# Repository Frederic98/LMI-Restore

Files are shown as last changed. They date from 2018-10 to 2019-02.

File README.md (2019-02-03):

# LMI-Restore

This is the github repository for the LMI re-store project at the Mechatronics lab at Fontys.

To run the software:
1. Start the server `python3 LMI_Server/server.py`
2. Start the client `python3 LMI_GUI/main.py`

The motion controller is programmed with Mbed: https://os.mbed.com/users/Frederic98/code/LMI_restore_V2/.  
The host talks to it using [g-code](https://reprap.org/wiki/G-code). It uses the existing codes where possible (G0/G1 to move to a position, G28 to home...) or a custom code when this doesn't exist yet. (M200 to set the velocity for an axis. Normally, this is done with Fxxx in a G0/G1 command to set the total velocity of all axes combined when they are all synchronized. This, however, is not the case in this project, so another command had to be added to set the velocity of a specific axis)

Initially, the G-code was sent over the ethernet interface to the nucleo. This, however, seemed a bit unstable with the connection dropping after a couple of commands.
For this reason, it was replaced by the USB UART port (available at the programming USB connector).

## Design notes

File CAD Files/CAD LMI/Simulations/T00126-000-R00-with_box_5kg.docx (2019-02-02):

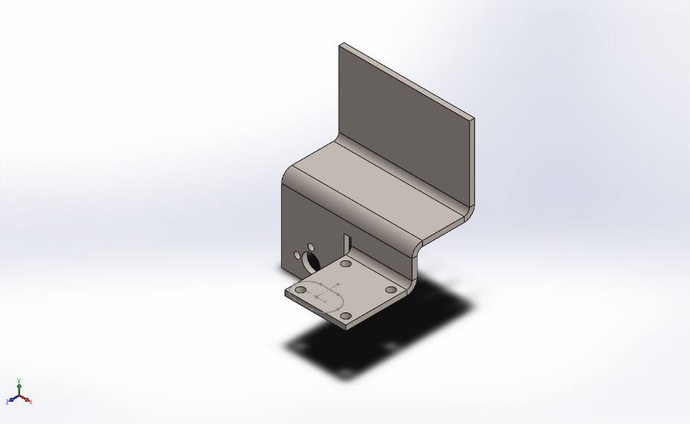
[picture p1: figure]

Simulation of T00126-000-R00

Date: woensdag 12 december 2018
Designer: Jari Wernaart

Study name: Static 2

Analysis type: Static
Description No Data

# Assumptions

# Model Information

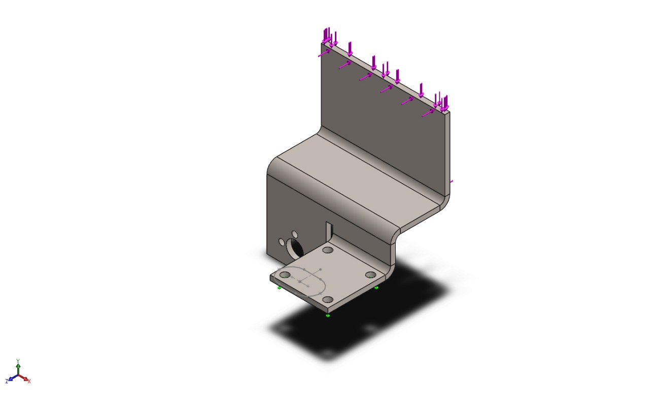
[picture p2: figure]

Model name: T00126-000-R00

Current Configuration: Default

# Study Properties

Study name | Static 2
Analysis type | Static
Mesh type | Shell Mesh Using Mid-surfaces
Thermal Effect: | On
Thermal option | Include temperature loads
Zero strain temperature | 298 Kelvin
Include fluid pressure effects from SOLIDWORKS Flow Simulation | Off
Solver type | FFEPlus
Inplane Effect: | Off
Soft Spring: | Off
Inertial Relief: | Off
Incompatible bonding options | Automatic
Large displacement | Off
Compute free body forces | On
Friction | Off
Use Adaptive Method: | Off
Result folder | SOLIDWORKS document (F:\Google drive\LMI restore system\1. Documenten\7. CAD files\CAD LMI)

# Units

Unit system: | SI (MKS)
Length/Displacement | mm
Temperature | Kelvin
Angular velocity | Rad/sec
Pressure/Stress | N/m^2

# Material Properties

Model Reference | Properties | Components

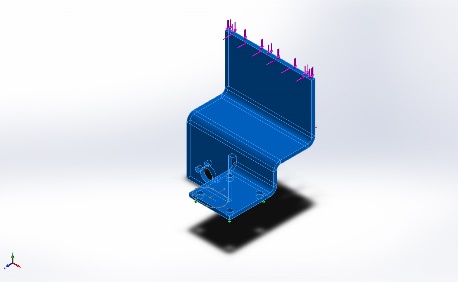
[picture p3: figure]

| Name: Alloy Steel Model type: Linear Elastic Isotropic Default failure criterion: Max von Mises Stress Yield strength: 6.20422e+08 N/m^2 Tensile strength: 7.23826e+08 N/m^2 Elastic modulus: 2.1e+11 N/m^2 Poisson's ratio: 0.28 Mass density: 7700 kg/m^3 Shear modulus: 7.9e+10 N/m^2 Thermal expansion coefficient: 1.3e-05 /Kelvin | SolidBody 1(Body-Move/Copy1)(T00126-000-R00)

Curve Data:N/A

# Loads and Fixtures

Fixture name | Fixture Image | Fixture Details

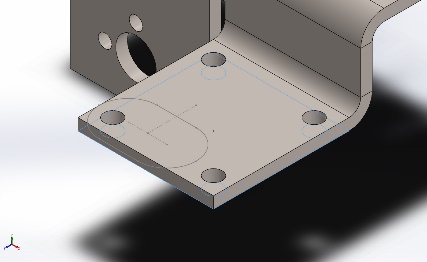
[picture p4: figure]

Fixed-1 | | Entities: 1 face(s) Type: Fixed Geometry

Resultant Forces

Components | X | Y | Z | Resultant
Reaction force(N) | -0.0373039 | 48.8594 | -0.0282078 | 48.8594
Reaction Moment(N.m) | 5.58892 | 0.000350614 | 0.00770916 | 5.58893

Load name | Load Image | Load Details

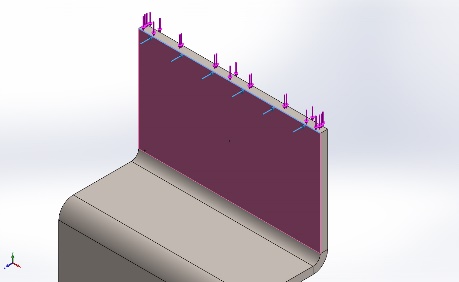
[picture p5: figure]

Force-2 | | Entities: 1 edge(s) Reference: Face< 1 > Type: Apply force Values: ---, ---, -87.2 N Moments: ---, ---, --- N.m

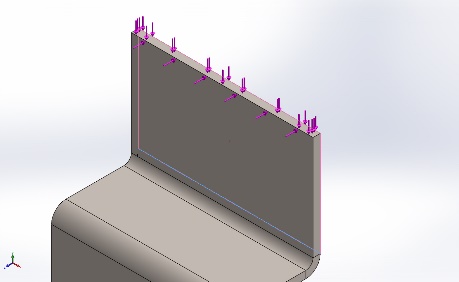
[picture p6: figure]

Force-3 | | Entities: 1 edge(s) Reference: Face< 1 > Type: Apply force Values: ---, ---, 87.2 N Moments: ---, ---, --- N.m

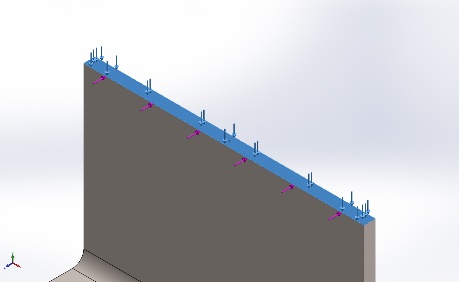
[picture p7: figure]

Force-4 | | Entities: 1 face(s) Type: Apply normal force Value: 49.05 N

# Connector Definitions

No Data

# Contact Information

No Data

# Mesh information

Mesh type | Shell Mesh Using Mid-surfaces
Mesher Used: | Standard mesh
Automatic Transition: | Off
Include Mesh Auto Loops: | Off
Jacobian points | 4 Points
Element Size | 1.9994 mm
Tolerance | 0.0999699 mm
Mesh Quality Plot | High

## Mesh information - Details

Total Nodes | 10121
Total Elements | 4902
Time to complete mesh(hh;mm;ss): | 00:00:03
Computer name:

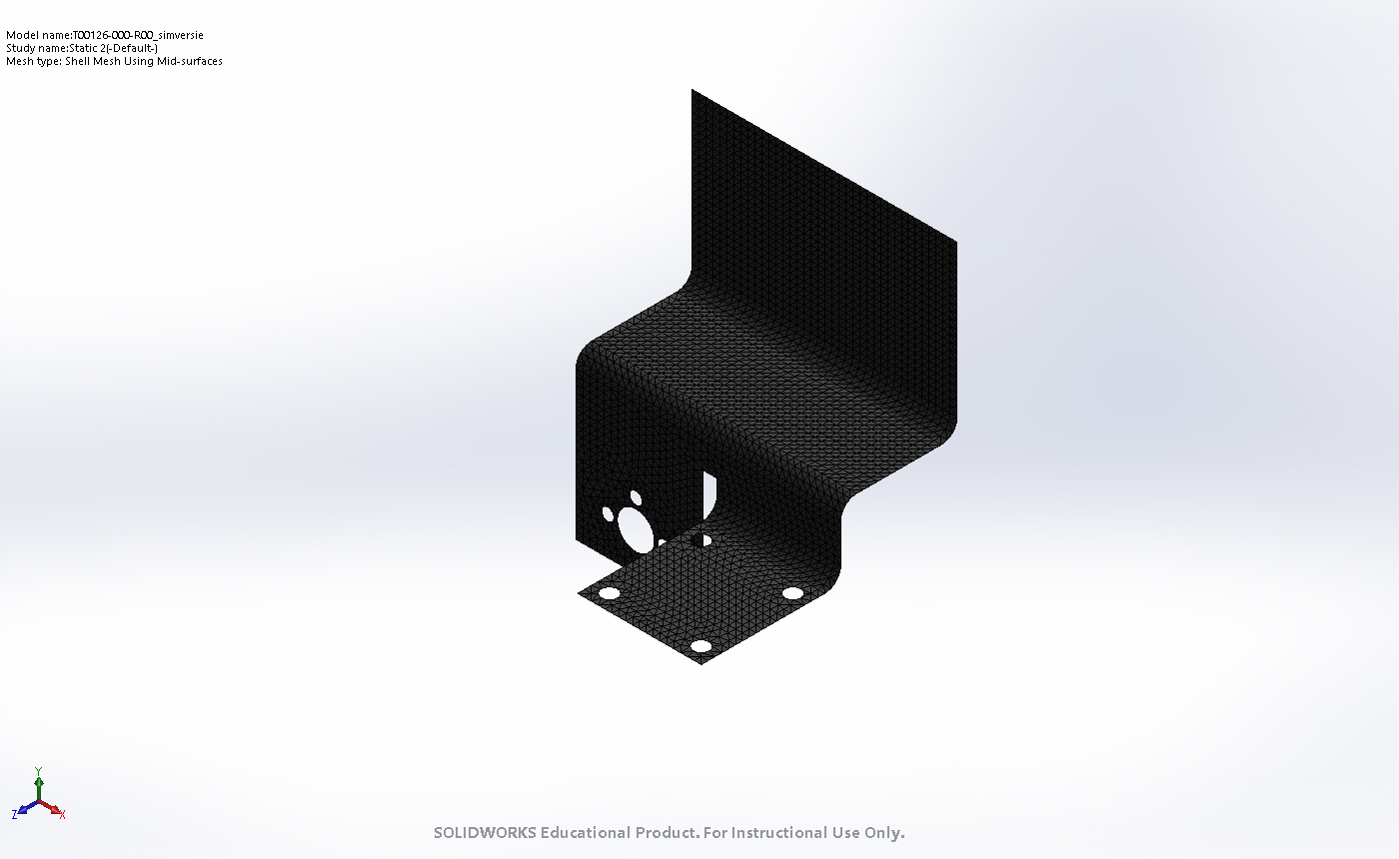
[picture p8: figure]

# Sensor Details

No Data

# Resultant Forces

## Reaction forces

Selection set | Units | Sum X | Sum Y | Sum Z | Resultant
Entire Model | N | -0.0373039 | 48.8594 | -0.0282078 | 48.8594

## Reaction Moments

Selection set | Units | Sum X | Sum Y | Sum Z | Resultant
Entire Model | N.m | 5.58892 | 0.000350614 | 0.00770916 | 5.58893

# Beams

No Data

# Study Results

Name | Type | Min | Max
Stress1 | VON: von Mises Stress | 0.000e+00 N/m^2 Node: 2273 | 2.903e+08 N/m^2 Node: 925

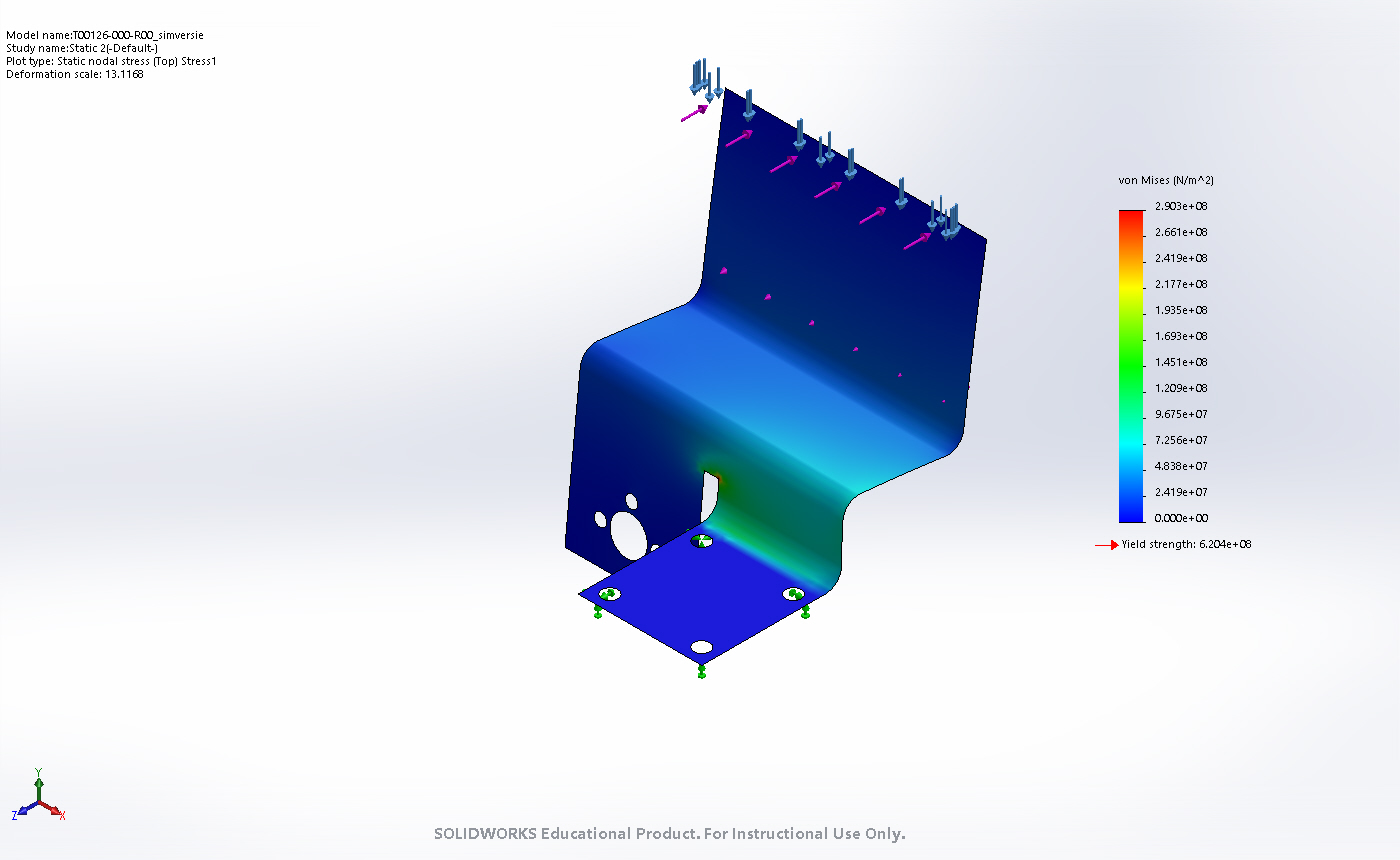
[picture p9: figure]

T00126-000-R00 -Static 2-Stress-Stress1

Name | Type | Min | Max
Displacement1 | URES: Resultant Displacement | 0.000e+00 mm Node: 2200 | 7.911e-01 mm Node: 1339

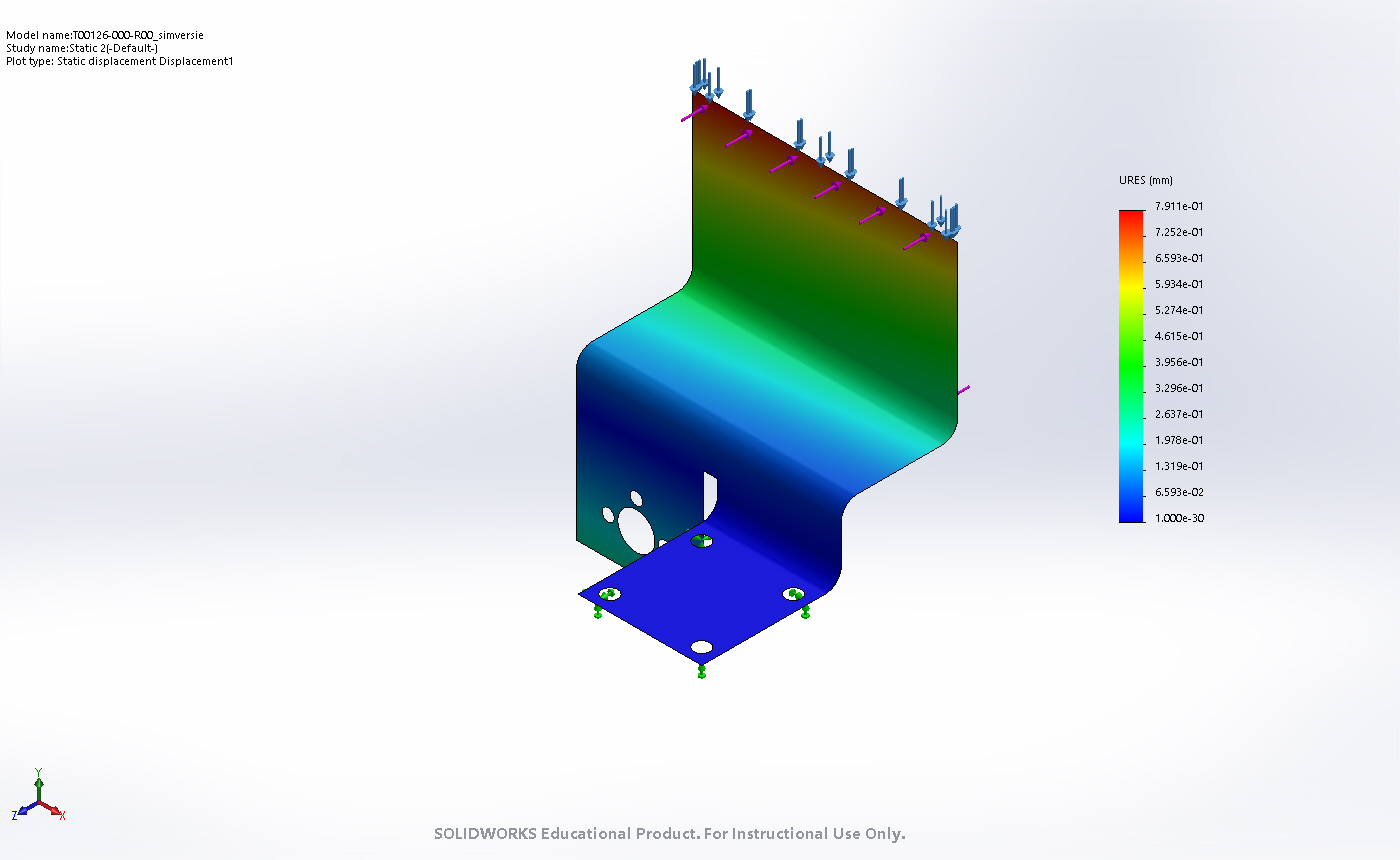
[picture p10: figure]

T00126-000-R00 -Static 2-Displacement-Displacement1

Name | Type | Min | Max
Strain1 | ESTRN: Equivalent Strain | 0.000e+00 Element: 4295 | 7.981e-04 Element: 2136

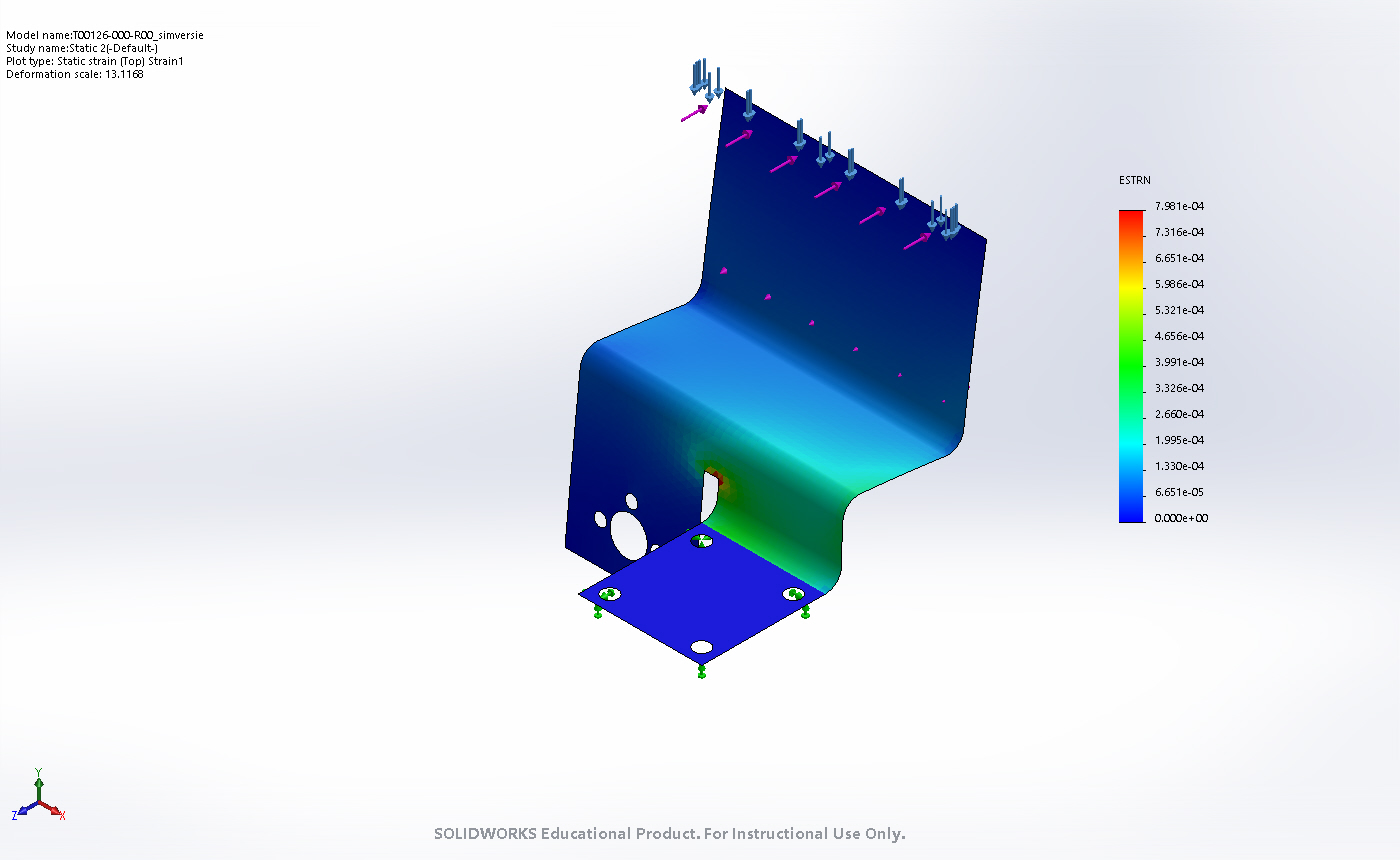
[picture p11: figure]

T00126-000-R00 -Static 2-Strain-Strain1

# Conclusion

Analyzed with SOLIDWORKS Simulation Simulation of T00126-000-R00 7

Analyzed with SOLIDWORKS Simulation Simulation of T00126-000-R00 1

Fontys Jari Wernaart 12-12-2018

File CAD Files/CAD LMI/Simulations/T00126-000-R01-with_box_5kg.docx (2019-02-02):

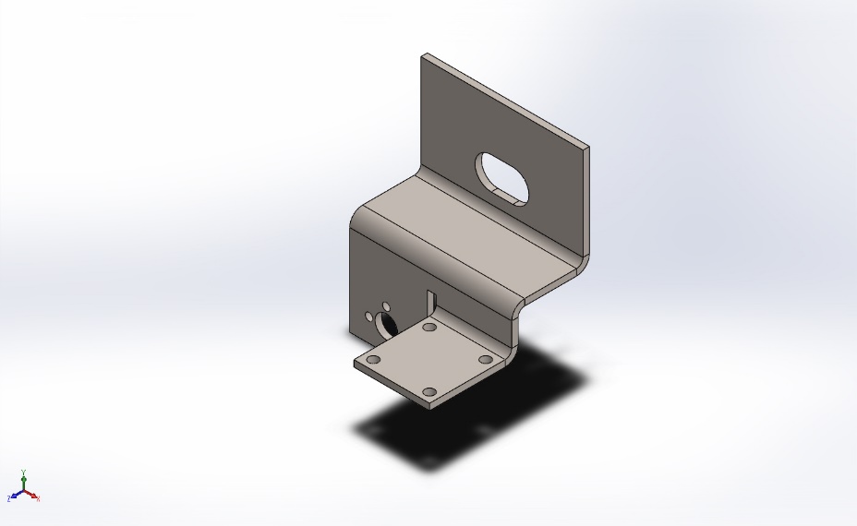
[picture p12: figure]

Simulation of T00126-000-R01

Date: woensdag 12 december 2018
Designer: Jari Wernaart

Study name: Static 2

Analysis type: Static
Description No Data

# Assumptions

# Model Information

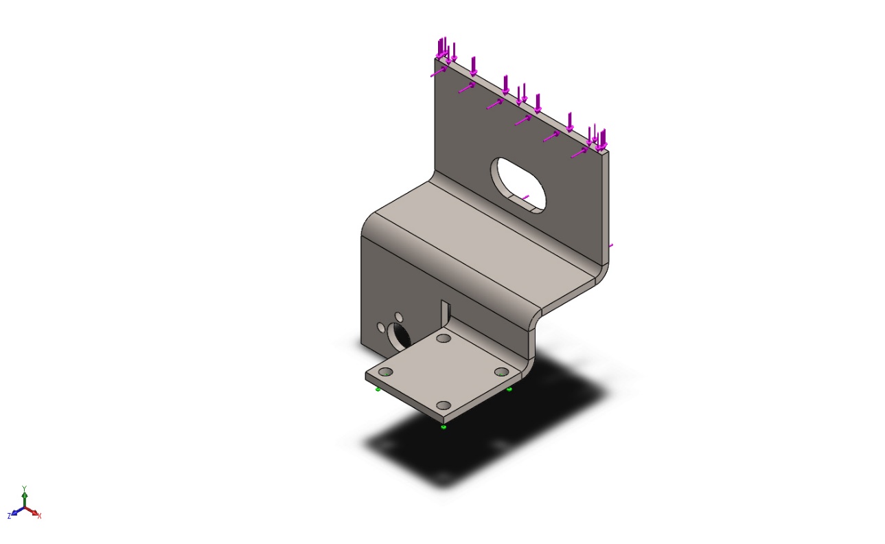
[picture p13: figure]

Model name: T00126-000-R01

Current Configuration: Default

# Study Properties

Study name | Static 2
Analysis type | Static
Mesh type | Shell Mesh Using Mid-surfaces
Thermal Effect: | On
Thermal option | Include temperature loads
Zero strain temperature | 298 Kelvin
Include fluid pressure effects from SOLIDWORKS Flow Simulation | Off
Solver type | FFEPlus
Inplane Effect: | Off
Soft Spring: | Off
Inertial Relief: | Off
Incompatible bonding options | Automatic
Large displacement | Off
Compute free body forces | On
Friction | Off
Use Adaptive Method: | Off
Result folder | SOLIDWORKS document (F:\Google drive\LMI restore system\1. Documenten\7. CAD files\CAD LMI)

# Units

Unit system: | SI (MKS)
Length/Displacement | mm
Temperature | Kelvin
Angular velocity | Rad/sec
Pressure/Stress | N/m^2

# Material Properties

Model Reference | Properties | Components

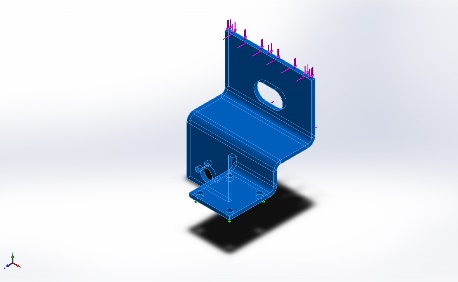
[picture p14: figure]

| Name: Alloy Steel Model type: Linear Elastic Isotropic Default failure criterion: Max von Mises Stress Yield strength: 6.20422e+08 N/m^2 Tensile strength: 7.23826e+08 N/m^2 Elastic modulus: 2.1e+11 N/m^2 Poisson's ratio: 0.28 Mass density: 7700 kg/m^3 Shear modulus: 7.9e+10 N/m^2 Thermal expansion coefficient: 1.3e-05 /Kelvin | SolidBody 1(Body-Move/Copy1)(T00126-000-R01)

Curve Data:N/A

# Loads and Fixtures

Fixture name | Fixture Image | Fixture Details

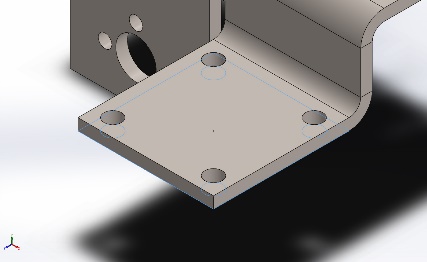
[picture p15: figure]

Fixed-1 | | Entities: 1 face(s) Type: Fixed Geometry

Resultant Forces

Components | X | Y | Z | Resultant
Reaction force(N) | -0.0425277 | 48.854 | -0.00805473 | 48.854
Reaction Moment(N.m) | 5.58896 | 0.000318305 | 0.00770636 | 5.58896

Load name | Load Image | Load Details

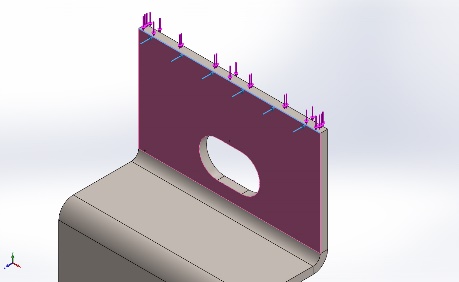
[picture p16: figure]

Force-2 | | Entities: 1 edge(s) Reference: Face< 1 > Type: Apply force Values: ---, ---, -87.2 N Moments: ---, ---, --- N.m

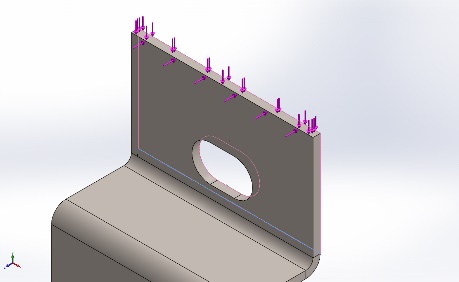
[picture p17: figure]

Force-3 | | Entities: 1 edge(s) Reference: Face< 1 > Type: Apply force Values: ---, ---, 87.2 N Moments: ---, ---, --- N.m

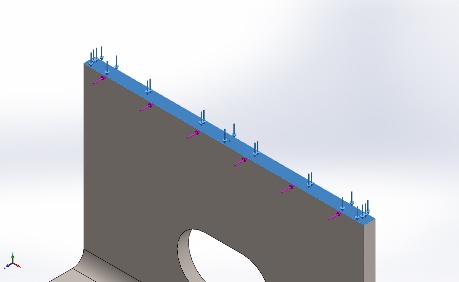
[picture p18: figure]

Force-4 | | Entities: 1 face(s) Type: Apply normal force Value: 49.05 N

# Connector Definitions

No Data

# Contact Information

No Data

# Mesh information

Mesh type | Shell Mesh Using Mid-surfaces
Mesher Used: | Standard mesh
Automatic Transition: | Off
Include Mesh Auto Loops: | Off
Jacobian points | 4 Points
Element Size | 1.9994 mm
Tolerance | 0.0999699 mm
Mesh Quality Plot | High

## Mesh information - Details

Total Nodes | 9826
Total Elements | 4738
Time to complete mesh(hh;mm;ss): | 00:00:03
Computer name:

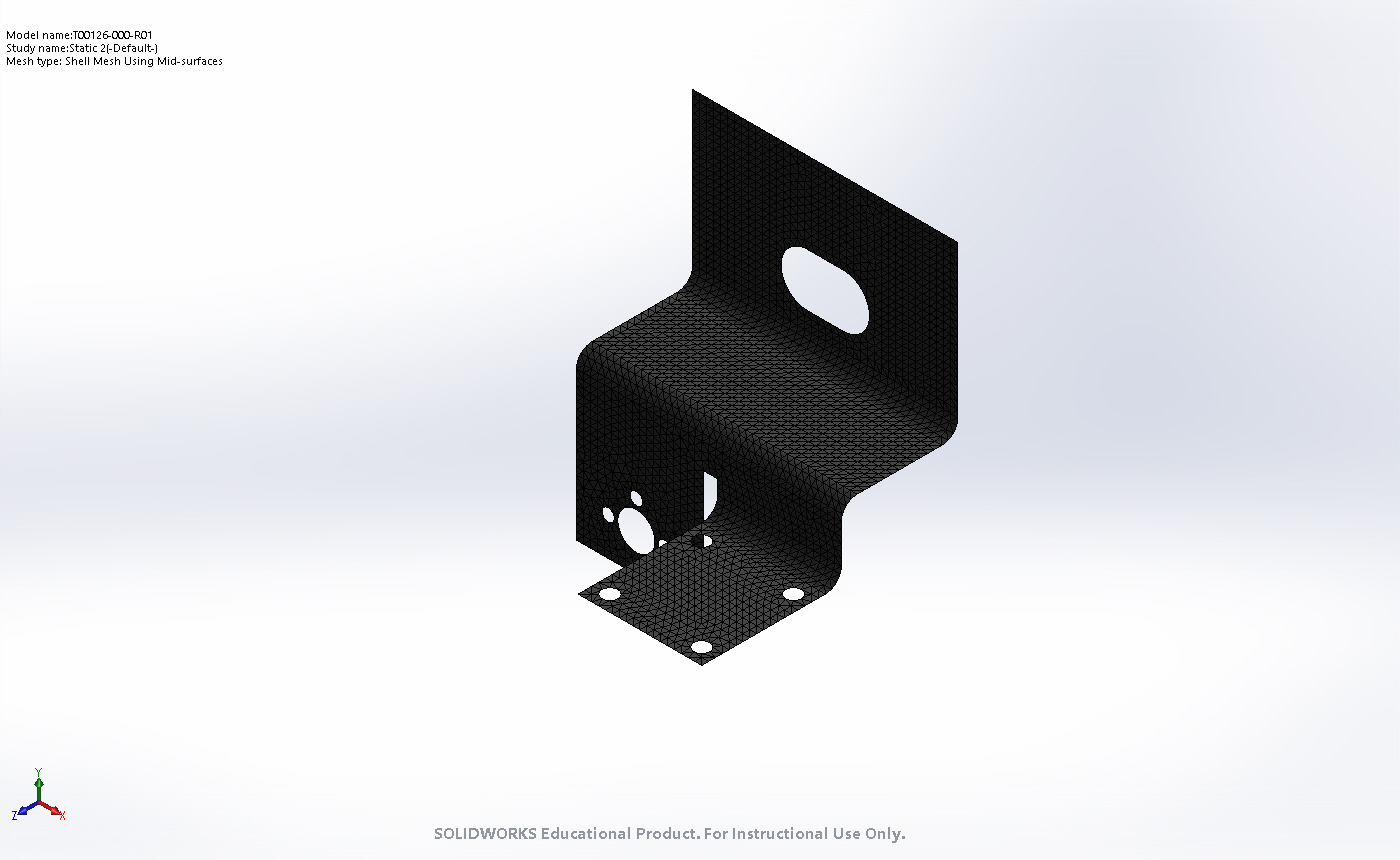
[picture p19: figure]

# Sensor Details

No Data

# Resultant Forces

## Reaction forces

Selection set | Units | Sum X | Sum Y | Sum Z | Resultant
Entire Model | N | -0.0425277 | 48.854 | -0.00805473 | 48.854

## Reaction Moments

Selection set | Units | Sum X | Sum Y | Sum Z | Resultant
Entire Model | N.m | 5.58896 | 0.000318305 | 0.00770636 | 5.58896

# Beams

No Data

# Study Results

Name | Type | Min | Max
Stress1 | VON: von Mises Stress | 0.000e+00 N/m^2 Node: 2207 | 2.911e+08 N/m^2 Node: 925

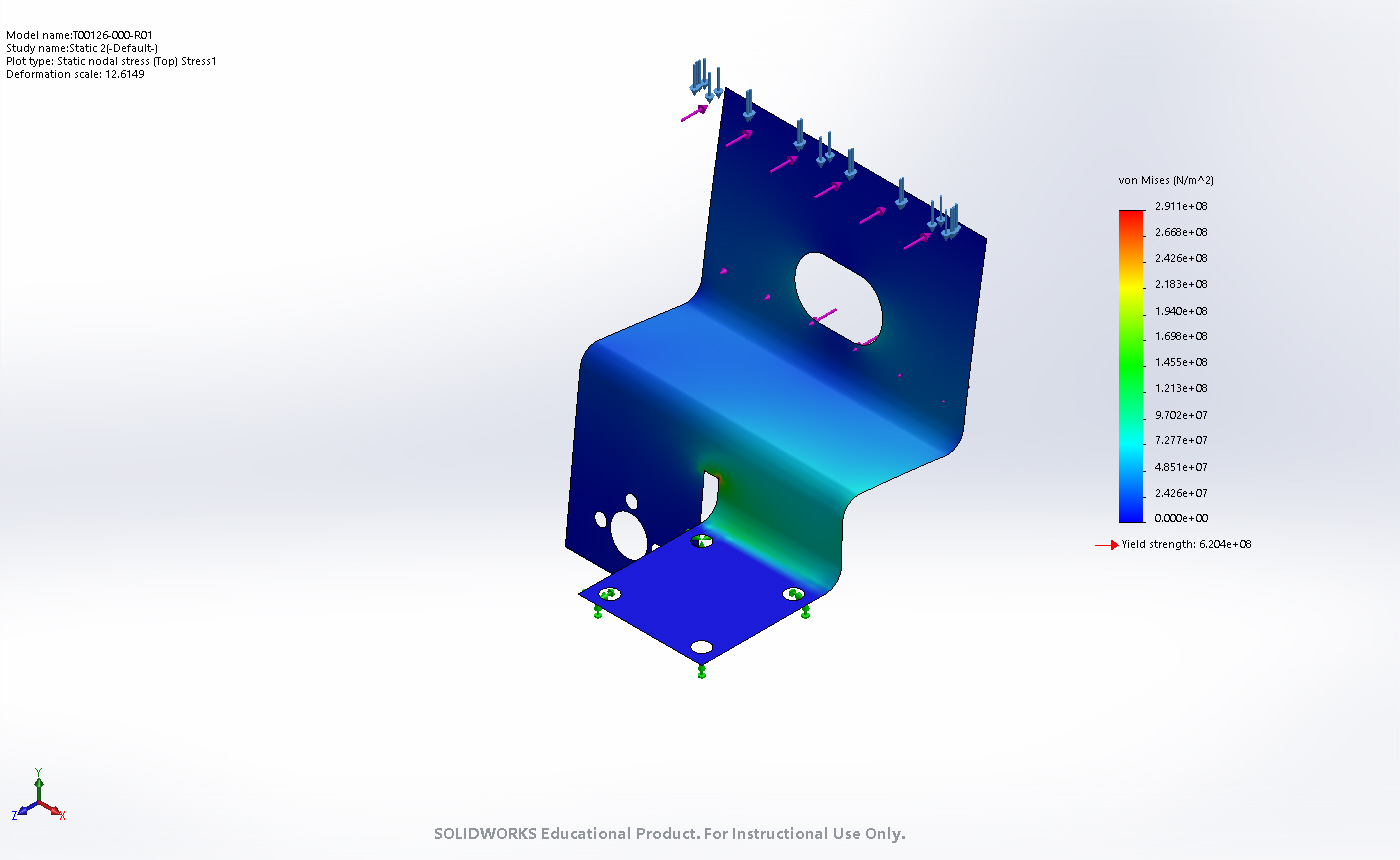
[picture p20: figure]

T00126-000-R01-Static 2-Stress-Stress1

Name | Type | Min | Max
Displacement1 | URES: Resultant Displacement | 0.000e+00 mm Node: 2134 | 8.171e-01 mm Node: 1373

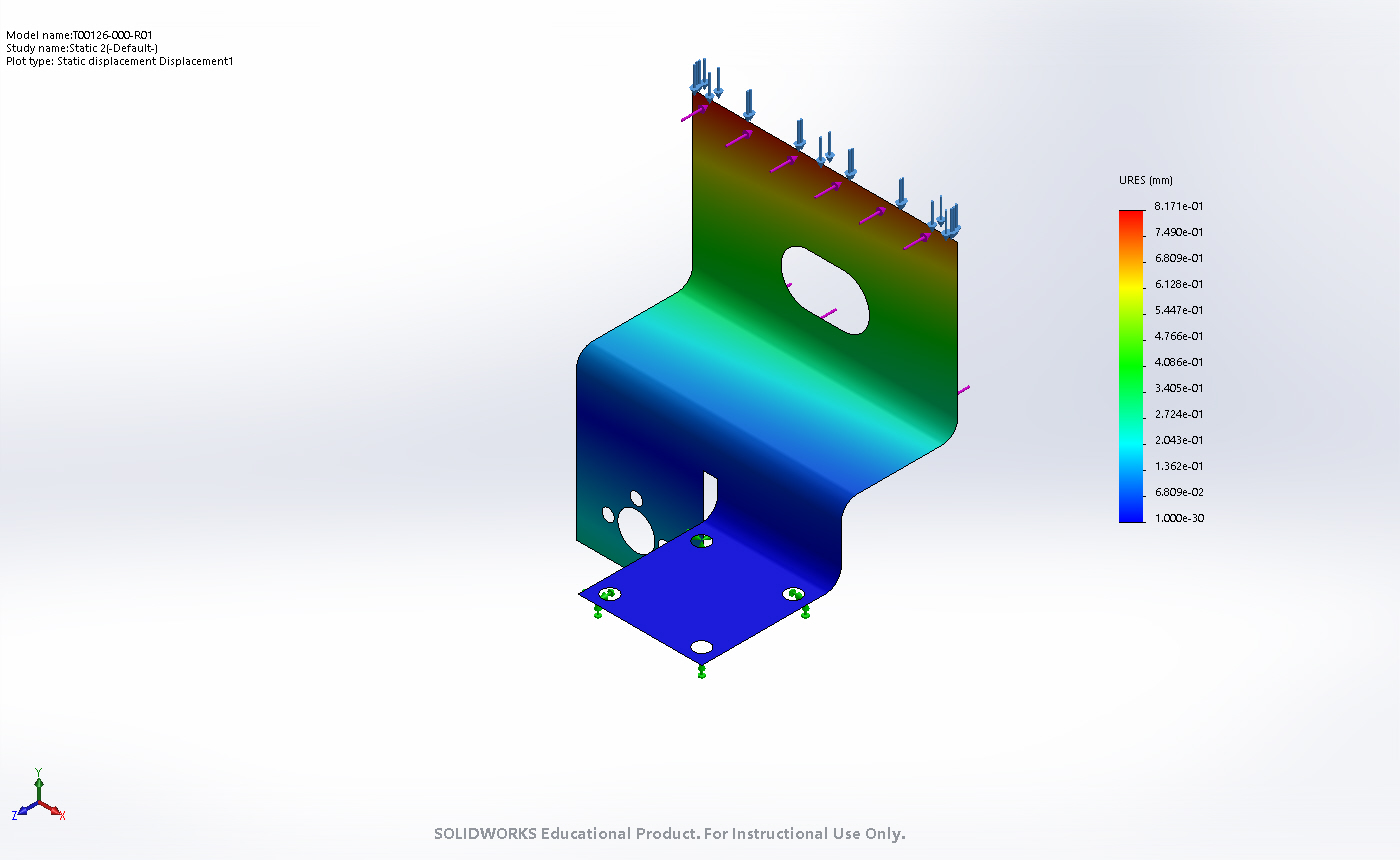
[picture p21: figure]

T00126-000-R01-Static 2-Displacement-Displacement1

Name | Type | Min | Max
Strain1 | ESTRN: Equivalent Strain | 0.000e+00 Element: 4131 | 7.999e-04 Element: 2136

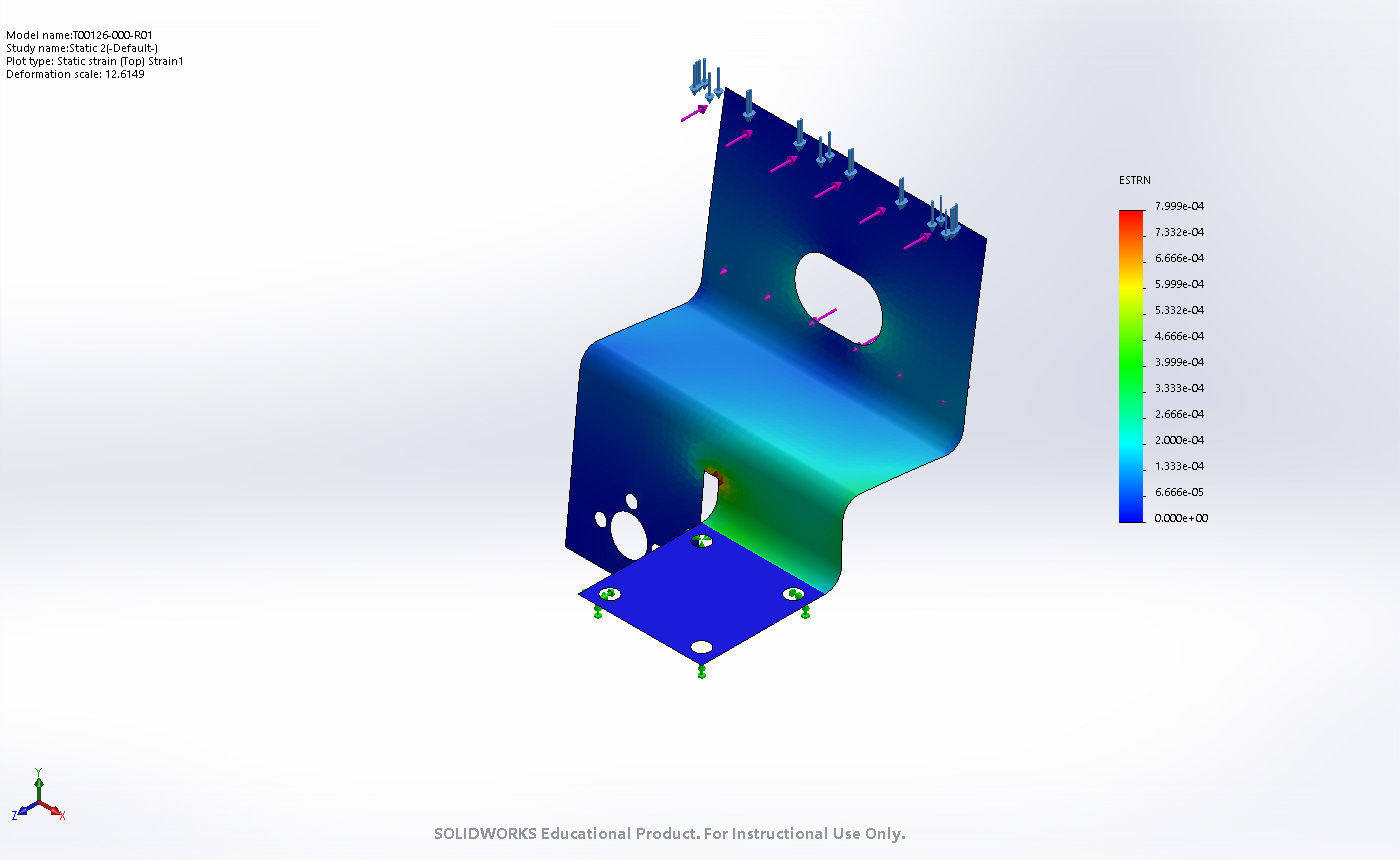
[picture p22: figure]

T00126-000-R01-Static 2-Strain-Strain1

# Conclusion

Analyzed with SOLIDWORKS Simulation Simulation of T00126-000-R01 7

Analyzed with SOLIDWORKS Simulation Simulation of T00126-000-R01 1

Fontys Jari Wernaart 12-12-2018

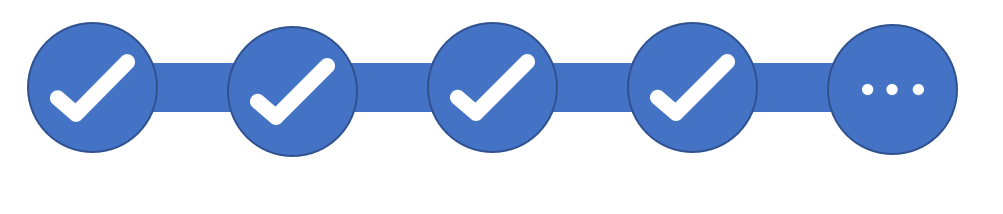
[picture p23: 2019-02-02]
LMI_GUI/Images/busy_5.PNG

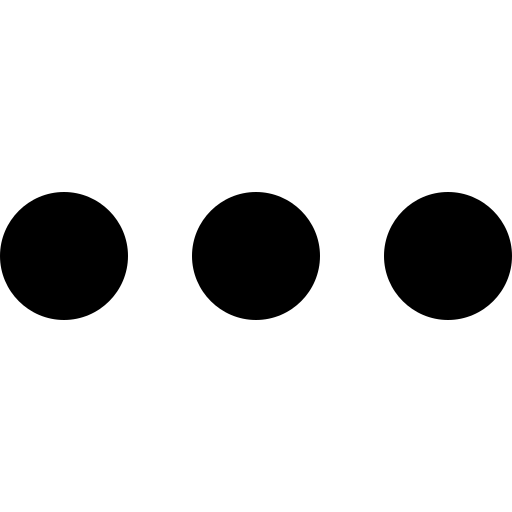
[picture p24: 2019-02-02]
LMI_GUI/Images/Triple-dot_black.png

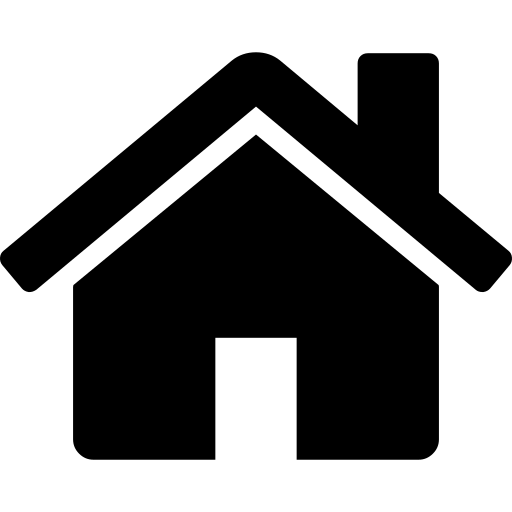
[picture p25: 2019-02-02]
LMI_GUI/Images/home.png

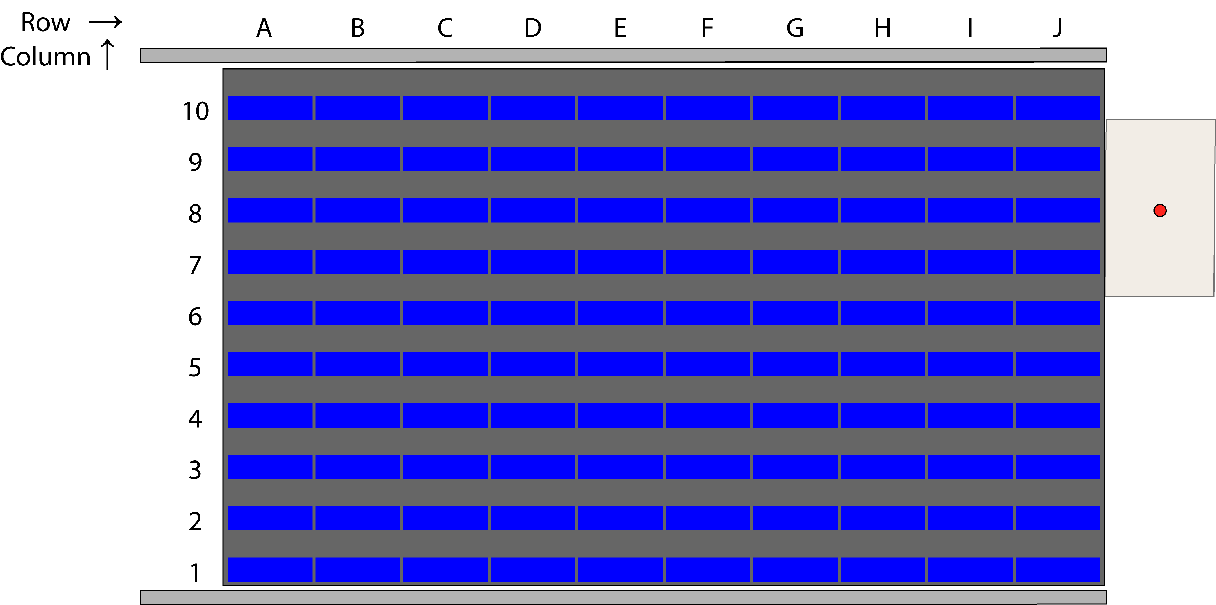
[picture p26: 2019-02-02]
LMI_GUI/Images/Storage_unit_RC.png

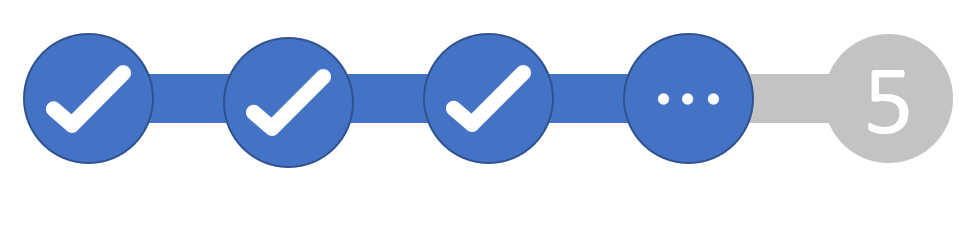
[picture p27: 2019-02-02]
LMI_GUI/Images/busy_4.PNG

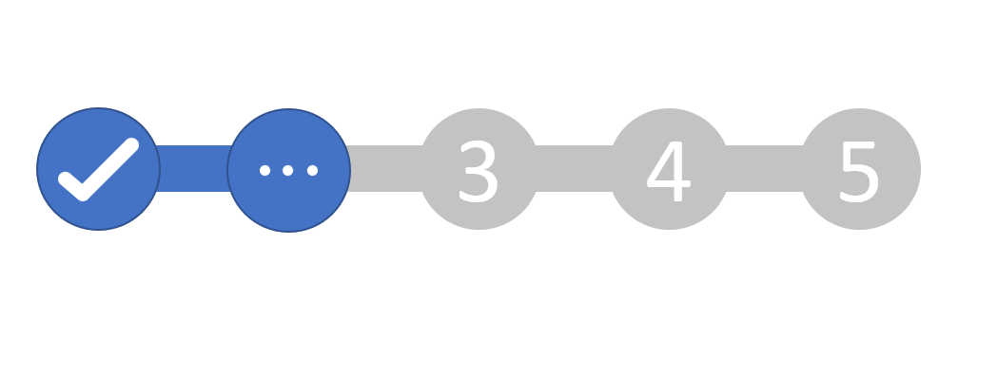
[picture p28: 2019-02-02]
LMI_GUI/Images/busy_2.PNG

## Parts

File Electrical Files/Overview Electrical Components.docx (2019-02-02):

Electrical components inside electrical box

QTY | Functie | Model/type | Leverancier - artikelnummer
1 | Elektrokast 400x500x210mm | Rittal AE 1045.500 | Conrad - 531738 (https://www.conrad.nl/p/rittal-ae-1045500-schakelkast-400-x-500-x-210-plaatstaal-grijs-wit-ral-7035-1-stuks-531738)
1 | 230V connector | 59JR101-1FR-LR | Conrad - 736709 (https://www.conrad.nl/p/apparaatstekker-42r-serie-connectoren-42r-stekker-inbouw-verticaal-totaal-aantal-polen-2-pe-10-a-zwart-k-b-59jr1-736709)
1 | Emergency switch | 1233815 | Conrad - 1233815 (https://www.conrad.nl/p/deca-a20l-v4e02q6r-noodstopschakelaar-met-contactelement-240-vac-6-a-2x-nc-ip65-1-stuks-1233815)
1 | Power supply 24V, 15A | POWER-S25024 - 24V | Reprap World - 8719128324975 (https://reprapworld.nl/products/elektronica/voeding/stroomadapter_24v_240_115v_15a_max/)
1 | Power supply 12V, 30A | POWER-S25012-12V30A | Reprap World - 8719128327037 (https://reprapworld.nl/products/elektronica/voeding/stroomadapter_12v_240_115v_30a_max/)
2 | Stepper driver R and Z | SDTB6600 9-42V, 3.5A | Reprap World - 8719345004964 (https://reprapworld.nl/products/elektronica/stappenmotordriver/tb6600_stappenmotor_3_5a_1_32_microstappen_9_42v/)
2 | Stepper driver X and Y | SL2690A 20-90V, 6.5A | Reprap World - 8719345005824 (https://reprapworld.nl/products/elektronica/stappenmotordriver/sl2690a_stappenmotor_6_5a_1_128_microstappen_20_90v/)
1 | 5V relay 1-channel high active | 5VRELHA | TinyTronics - 000131 (https://www.tinytronics.nl/shop/nl/diversen/relais/5v-relais-1-channel-hoog-actief?search=relais)
1 | STM32 Nucleo-144 | NUCLEO-F439ZI | Farnll - 2845532 (https://nl.farnell.com/stmicroelectronics/nucleo-f439zi/dev-board-32bit-arm-cortex-m4/dp/2845532?ost=2845532)
1 | Raspberry Pi 3 Model B+ 1GB | RPI3B+ | TinyTronics - 001587 (https://www.tinytronics.nl/shop/nl/raspberry-pi/main-boards/raspberry-pi-3-model-b-1gb-1?search=1587)
1 | Ethernet cable | F6TP0,25RT | Conrad - 1886785 (https://www.conrad.nl/p/econ-connect-rj45-netwerk-aansluitkabel-cat-6-sftp-025-m-rood-pair-afscherming-1886785)
2 | USB Adapter | NAUSB-W | Farnell - 1760681 (https://nl.farnell.com/neutrik/nausb-w/usb-adaptor-2-0-type-a-type-b/dp/1760681?ost=1760681)
2 | USB-B cable | USB-BUSB30CM | TinyTronics - 000927 (https://www.tinytronics.nl/shop/nl/kabels/usb/usb-b-usb-kabel-30cm?search=927)
2 | PC-ventilator | BL046 | Conrad - 756546 (https://www.conrad.nl/p/bequiet-pure-wings-2-pc-ventilator-zwart-b-x-h-x-d-120-x-120-x-25-mm-756546)
2 | PC fan grille | GRM120-30 | Conrad - 998782 (https://www.conrad.nl/p/pc-fan-grille-with-filter-akasa-grm120-30-120-x-120-mm-998782)
1 | Touchscreen | 7LCD1024X600TOUCHRPI | TinyTronics - 001501 (https://www.tinytronics.nl/shop/nl/raspberry-pi/accessoires/7-inch-lcd-display-1024*600-pixels-met-touchscreen-raspberry-pi-compatible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)
1 | HDMI cable | HDMICABLE1M | TinyTronics - 001270 (https://www.tinytronics.nl/shop/nl/kabels/hdmi/hdmi-kabel-1m?search=hdmi)
2 | Plug-in bridge - FBS 4-5 | Phoenix Contact FBS 4-5 | Conrad - 744072 (https://www.conrad.nl/p/geleiderbrug-fbs-4-5-phoenix-contact-inhoud-1-stuks-744072)
44 | Feed-through terminal block | Phoenix Contact UT2,5 | Conrad - 744725 (https://www.conrad.nl/p/phoenix-contact-ut-25-3044076-doorgangsklem-aantal-polen-2-014-mm-4-mm-grijs-1-stuks-744725)

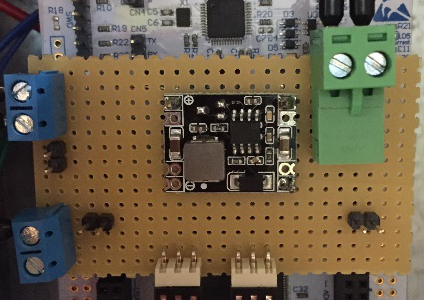
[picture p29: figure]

Nucleo Shield Components inside electrical box

QTY | Functie | Model/type | Leverancier - artikelnummer
1 | Voltage converter | DCDCSTEPDOWN5V | TinyTronics - 001319 (https://www.tinytronics.nl/shop/nl/spanning-converters/step-down/dc-dc-step-down-buck-converter-1.5a-5v-output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)
2 | Fan connector | 1580964 | Conrad - 1580964 (https://www.conrad.nl/p/tru-components-male-header-standaard-totaal-aantal-polen-3-rastermaat-254-mm-1580964-1-stuks-1580964)
2 | 2 pin screw terminal | PM 5.08/2/90 3.5 SW -1760510000 | RS - 425-8720 (https://nl.rs-online.com/web/p/pcb-terminal-blocks/4258720/)
1 | Pluggable Terminal Block PCB header | 691313510002 | RS - 826-7494 (https://nl.rs-online.com/web/p/pcb-terminal-blocks/8267494/)
1 | Pluggable Terminal Block | 1758364 | RS - 802-5919 (https://nl.rs-online.com/web/p/pcb-terminal-blocks/8025919/)

Raspberry Pi Shield Components inside electrical box

QTY | Functie | Model/type | Leverancier - artikelnummer
1 | Voltage converter | XL6009UPDOWN | TinyTronics - 001319 (https://www.tinytronics.nl/shop/nl/spanning-converters/step-up/dc-dc-verstelbare-step-up-down-buck-boost-converter-xl6009-4a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)
2 | 2 pin screw terminal | PM 5.08/2/90 3.5 SW -1760510000 | RS - 425-8720 (https://nl.rs-online.com/web/p/pcb-terminal-blocks/4258720/)
1 | Mini RS232 to TTL converter | MAX3232 | OpenCircuit - 34764 (https://opencircuit.nl/Product/11581/MAX3232-Mini-RS232-naar-TTL-converter)
2 | PCB Terminal Block | 1725656 | RS- 220-4260 (https://nl.rs-online.com/web/p/pcb-terminal-blocks/2204260/)

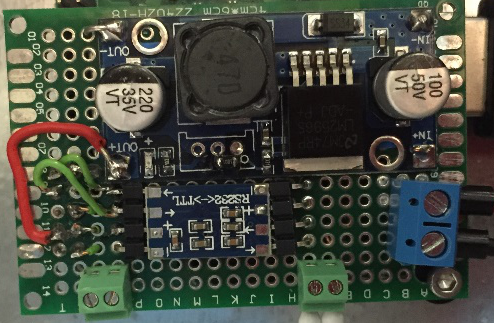
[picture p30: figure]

Electrical components outside electrical box

QTY | Functie | Model/type | Leverancier - artikelnummer
2 | Stepper Motor NEMA17 | SL42S247A | Reprap World - 8719345003981 (https://reprapworld.nl/products/motoren_fans/stappenmotoren/nema17_stappenmotor_1_8_stap_stekker_platte_as_5_0_kg_cm/)
1 | Stepper Motor NEMA23 | SMNM23S18KG31 | Reprap World - 8719345005800 (https://reprapworld.nl/products/motoren_fans/stappenmotoren/nema23_stappenmotor_1_8_stap_30_59_kg_cm)
1 | Nema 24 Stepper w/ Brake | 24HS39-4204D-B200 | Stepperonline - 24HS39-4204D-B200 (https://www.omc-stepperonline.com/nema-24-stepper-40nm566-ozin-w-brake-friction-torque-20nm283ozin-24hs39-4204d-b200.html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)
5 | Panasonic lightswitch F-type | PM-F65W-P | Conrad - 1547476 (https://www.conrad.nl/p/panasonic-pm-f65w-p-vorklichtsluis-f-type-lichtschakelend-donkerschakelend-5-24-vdc-1-stuks-1547476)
2 | Panasonic lightswitch | PM-Y65-P | Conrad - 1547442 (https://www.conrad.nl/p/panasonic-pm-y65-p-vorklichtsluis-y-type-lichtschakelend-donkerschakelend-5-24-vdc-1-stuks-1547442)
1 | Panasonic CN14AC1 light switch cable (1m) | CN14AC1 | Conrad - 1429076 (https://www.conrad.nl/p/panasonic-cn14ac1-aansluitkabel-serie-cn14-uitvoering-algemeen-aansluitkabel-1429076)
1 | Panasonic CN14AC3 light switch cable (3m) | CN14AC3 | Conrad - 1429107 (https://www.conrad.nl/p/panasonic-cn14ac3-aansluitkabel-serie-cn14-uitvoering-algemeen-aansluitkabel-1429107)
5 | Panasonic CN14AC5 light switch cable (5m) | CN14AC5 | Conrad - 1429077 (https://www.conrad.nl/p/panasonic-cn14ac5-aansluitkabel-serie-cn14-uitvoering-algemeen-aansluitkabel-1429077)
3 | Load cell – 5kg | LOADCELL5KG | Tinytronics - 000951 (https://www.tinytronics.nl/shop/nl/sensoren/gewicht-druk-kracht/load-cell-5kg)
3 | Load Cell Amplifier - HX711 | HX711MOD | TinyTronics - 000747 (https://www.tinytronics.nl/shop/nl/sensoren/gewicht-druk-kracht/load-cell-versterker-hx711?search=747)
1 | Voltage converter | DCDCSTEPDOWN5V | TinyTronics - 001319 (https://www.tinytronics.nl/shop/nl/spanning-converters/step-down/dc-dc-step-down-buck-converter-1.5a-5v-output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)
1 | Mini RS232 to TTL converter | MAX3232 | OpenCircuit - 34764 (https://opencircuit.nl/Product/11581/MAX3232-Mini-RS232-naar-TTL-converter)
1 | Barcode Scanner Module – 1D/2D | WS-14810 | Kiwi Electronics - WS-14810 (https://www.kiwi-electronics.nl/barcode-scanner-14810)
1 | GX16-4 Connector Set | GX16-4 | TinyTronics - 001081 (https://www.tinytronics.nl/shop/nl/connectoren/overige/gx16-4-connector-set?search=1081)
1 | GX16-6 Connector Set | GX16-6 | TinyTronics - 001593 (https://www.tinytronics.nl/shop/nl/connectoren/overige/gx16-6-connector-set?search=Connector%20Set)

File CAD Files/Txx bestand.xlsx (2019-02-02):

Tekeningnummer: | Omschrijving: | K/M | CAD Model: | Drawing: | 3D machining file (Bijv. STL of STEP): | Custom: | Hoogste revisie: | Samenstelling: | Link: | Bestandsnaam:
00000 | LMI Re-store system hoofdsamenstelling | K/M | JA | NEE | NEE | JA | 01 |  |  | T00000-000-R01 | 01 | 000 | 00000
00001 | XY-carriage samenstelling | K/M | JA | NEE | NEE | JA | 01 |  |  | T00001-000-R01 | 01 | 000 | 00001
00002 | Magazijn samenstelling | K/M | JA | NEE | NEE | JA | 00 |  |  | T00002-000-R00 | 00 | 000 | 00002
00003 | Arm samenstelling | K/M | JA | NEE | NEE | JA | 02 | 00001 |  | T00003-000-R02 | 02 | 000 | 00003
00004 | Weegschaal samenstelling | K/M | JA | NEE | NEE | JA | 00 | 00002 |  | T00004-000-R00 | 00 | 000 | 00004
00005 | Barcode case samenstelling | K/M | JA | NEE | NEE | JA | 00 |  |  | T00005-000-R00 | 00 | 000 | 00005
00006 | Pick-up plate samenstelling | K/M | JA | NEE | NEE | JA | 00 |  |  | T00006-000-R00 | 00 | 000 | 00006
00007 | Elektrobox samenstelling | K/M | JA | NEE | NEE | JA | 00 | 00000 |  | T00007-000-R00 | 00 | 000 | 00007
00008 |  |  |  |  |  |  |  |  |  |  |  | Error | 00008
00009 |  |  |  |  |  |  |  |  |  |  |  | Error | 00009
00010 |  |  |  |  |  |  |  |  |  |  |  | Error | 00010
00011 |  |  |  |  |  |  |  |  |  |  |  | Error | 00011
00012 |  |  |  |  |  |  |  |  |  |  |  | Error | 00012
00013 |  |  |  |  |  |  |  |  |  |  |  | Error | 00013
00014 |  |  |  |  |  |  |  |  |  |  |  | Error | 00014
00015 |  |  |  |  |  |  |  |  |  |  |  | Error | 00015
00016 |  |  |  |  |  |  |  |  |  |  |  | Error | 00016
00017 |  |  |  |  |  |  |  |  |  |  |  | Error | 00017
00018 |  |  |  |  |  |  |  |  |  |  |  | Error | 00018
00019 |  |  |  |  |  |  |  |  |  |  |  | Error | 00019
00020 |  |  |  |  |  |  |  |  |  |  |  | Error | 00020
00021 |  |  |  |  |  |  |  |  |  |  |  | Error | 00021
00022 |  |  |  |  |  |  |  |  |  |  |  | Error | 00022
00023 |  |  |  |  |  |  |  |  |  |  |  | Error | 00023
00024 |  |  |  |  |  |  |  |  |  |  |  | Error | 00024
00025 |  |  |  |  |  |  |  |  |  |  |  | Error | 00025
00026 |  |  |  |  |  |  |  |  |  |  |  | Error | 00026
00027 |  |  |  |  |  |  |  |  |  |  |  | Error | 00027
00028 |  |  |  |  |  |  |  |  |  |  |  | Error | 00028
00029 |  |  |  |  |  |  |  |  |  |  |  | Error | 00029
00030 |  |  |  |  |  |  |  |  |  |  |  | Error | 00030
00031 |  |  |  |  |  |  |  |  |  |  |  | Error | 00031
00032 |  |  |  |  |  |  |  |  | https://nl.aliexpress.com/store/product/10Pcs-7mm-Thread-Multicolor-2-Pins-Momentary-Push-Button-Switch/1965448_32788356922.html |  |  | Error | 00032
00033 |  |  |  |  |  |  |  |  |  |  |  | Error | 00033
00034 |  |  |  |  |  |  |  |  |  |  |  | Error | 00034
00035 |  |  |  |  |  |  |  |  |  |  |  | Error | 00035
00036 |  |  |  |  |  |  |  |  | https://www.alternate.nl/Sharkoon/SilentStorm-SFX-450-Bronze-450-Watt-voeding/html/product/1161908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 |  |  | Error | 00036
00037 |  |  |  |  |  |  |  |  |  |  |  | Error | 00037
00038 |  |  |  |  |  |  |  |  |  |  |  | Error | 00038
00039 |  |  |  |  |  |  |  |  |  |  |  | Error | 00039
00040 |  |  |  |  |  |  |  |  |  |  |  | Error | 00040
00041 |  |  |  |  |  |  |  |  |  |  |  | Error | 00041
00042 |  |  |  |  |  |  |  |  |  |  |  | Error | 00042
00043 |  |  |  |  |  |  |  |  |  |  |  | Error | 00043
00044 |  |  |  |  |  |  |  |  |  |  |  | Error | 00044
00045 |  |  |  |  |  |  |  |  |  |  |  | Error | 00045
00046 |  |  |  |  |  |  |  |  |  |  |  | Error | 00046
00047 |  |  |  |  |  |  |  |  |  |  |  | Error | 00047
00048 |  |  |  |  |  |  |  |  |  |  |  | Error | 00048
00049 |  |  |  |  |  |  |  |  |  |  |  | Error | 00049
00050 |  |  |  |  |  |  |  |  |  |  |  | Error | 00050
00051 |  |  |  |  |  |  |  |  |  |  |  | Error | 00051
00052 |  |  |  |  |  |  |  |  |  |  |  | Error | 00052
00053 |  |  |  |  |  |  |  |  |  |  |  | Error | 00053
00054 |  |  |  |  |  |  |  |  |  |  |  | Error | 00054
00055 |  |  |  |  |  |  |  |  |  |  |  | Error | 00055
00056 |  |  |  |  |  |  |  |  | https://www.jerrycanshop.nl/stalen-groene-leger-jerrycan-20-liter-voor-benzine-diesel.html |  |  | Error | 00056
00057 |  |  |  |  |  |  |  |  |  |  |  | Error | 00057
00058 |  |  |  |  |  |  |  |  |  |  |  | Error | 00058
00059 |  |  |  |  |  |  |  |  |  |  |  | Error | 00059
00060 |  |  |  |  |  |  |  |  |  |  |  | Error | 00060
00061 |  |  |  |  |  |  |  |  | https://nl.aliexpress.com/item/200pcs-M3-PCB-Hex-Male-Female-Threaded-Brass-Spacer-Standoffs-Screw-Nut-Assortment-Set-kit/32645948444.html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 |  |  | Error | 00061
00062 |  |  |  |  |  |  |  |  | https://nl.aliexpress.com/item/200pcs-M3-PCB-Hex-Male-Female-Threaded-Brass-Spacer-Standoffs-Screw-Nut-Assortment-Set-kit/32645948444.html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 |  |  | Error | 00062
00063 |  |  |  |  |  |  |  |  | https://nl.aliexpress.com/item/10pcs-lot-m3-m4-m5-m6-m8-Aluminum-alloy-Multicolour-step-hand-thumb-screw/32819063866.html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 |  |  | Error | 00063
00064 |  |  |  |  |  |  |  |  |  |  |  | Error | 00064
00065 |  |  |  |  |  |  |  |  |  |  |  | Error | 00065
00066 |  |  |  |  |  |  |  |  |  |  |  | Error | 00066
00067 |  |  |  |  |  |  |  |  |  |  |  | Error | 00067
00068 |  |  |  |  |  |  |  |  |  |  |  | Error | 00068
00069 |  |  |  |  |  |  |  |  |  |  |  | Error | 00069
00070 |  |  |  |  |  |  |  |  |  |  |  | Error | 00070
00071 |  |  |  |  |  |  |  |  | https://nl.aliexpress.com/item/21-5mm-Cam-Lock-For-Security-Door-Cabinet-Mailbox-Drawer-Cupboard-Locker-With-2-Keys-Home/32734726775.html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 |  |  | Error | 00071
00072 |  |  |  |  |  |  |  |  |  |  |  | Error | 00072
00073 |  |  |  |  |  |  |  |  | https://nl.aliexpress.com/item/Cabinet-Drawer-Door-Plastic-Handle-Pull-Knob-120mm-4-7-2-Pcs/32814874852.html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 |  |  | Error | 00073
00074 |  |  |  |  |  |  |  |  |  |  |  | Error | 00074
00075 |  |  |  |  |  |  |  |  |  |  |  | Error | 00075
00076 |  |  |  |  |  |  |  |  |  |  |  | Error | 00076
00077 |  |  |  |  |  |  |  |  |  |  |  | Error | 00077
00078 |  |  |  |  |  |  |  |  |  |  |  | Error | 00078
00079 |  |  |  |  |  |  |  |  |  |  |  | Error | 00079
00080 |  |  |  |  |  |  |  |  |  |  |  | Error | 00080
00081 |  |  |  |  |  |  |  |  |  |  |  | Error | 00081
00082 |  |  |  |  |  |  |  |  |  |  |  | Error | 00082
00083 |  |  |  |  |  |  |  |  |  |  |  | Error | 00083
00084 |  |  |  |  |  |  |  |  |  |  |  | Error | 00084
00085 |  |  |  |  |  |  |  |  |  |  |  | Error | 00085
00086 |  |  |  |  |  |  |  |  |  |  |  | Error | 00086
00087 |  |  |  |  |  |  |  |  |  |  |  | Error | 00087
00088 |  |  |  |  |  |  |  |  |  |  |  | Error | 00088
00089 |  |  |  |  |  |  |  |  |  |  |  | Error | 00089
00090 |  |  |  |  |  |  |  |  |  |  |  | Error | 00090
00091 |  |  |  |  |  |  |  |  |  |  |  | Error | 00091
00092 |  |  |  |  |  |  |  |  |  |  |  | Error | 00092
00093 |  |  |  |  |  |  |  |  |  |  |  | Error | 00093
00094 |  |  |  |  |  |  |  |  |  |  |  | Error | 00094
00095 |  |  |  |  |  |  |  |  |  |  |  | Error | 00095
00096 |  |  |  |  |  |  |  |  |  |  |  | Error | 00096
00097 |  |  |  |  |  |  |  |  |  |  |  | Error | 00097
00098 |  |  |  |  |  |  |  |  |  |  |  | Error | 00098
00099 |  |  |  |  |  |  |  |  |  |  |  | Error | 00099 | VANAF HIER: PARTS
00100 | Flenslager binnenØ 15mm | K | JA | NEE | NEE | NEE | 00 | 00001 |  | T00100-E00-R00 | 00 | E00 | 00100
00101 | Reely Kogellager radiaal Chroomstaal Binnen binnenØ 8mm, buitenØ 15mm (Conrad artnr: 239758) | K | JA | NEE | NEE | NEE | 00 | 00001 | Link (https://www.conrad.nl/p/reely-kogellager-radiaal-chroomstaal-binnen-214477) | T00101-E00-R00 | 00 | E00 | 00101
00102 | Timing pulley T10 Ø 15mm | K | JA | NEE | NEE | NEE | 00 | 00001 | Link (https://uk.misumi-ec.com/vona2/detail/110300406910/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) | T00102-E00-R00 | 00 | E00 | 00102
00103 | Blickle 346601 wiel binnenØ 6mm, BuitenØ 50 mm (Conrad artnr: 826519) | K | JA | NEE | NEE | NEE | 00 | 00001 | Link (https://www.conrad.nl/p/blickle-346601-zwenkwiel-50-mm-uitvoering-algemeen-zwenkwiel-met-schroefplaat-826519) | T00103-E00-R00 | 00 | E00 | 00103
00104 | Afstandsbus 20x12x25mm | K | JA | NEE | NEE | NEE | 00 | 00001 |  | T00104-E00-R00 | 00 | E00 | 00104
00105 | Afstandsbus klein | K | JA | NEE | NEE | NEE | 00 | 00003 |  | T00105-E00-R00 | 00 | E00 | 00105
00106 | Stepper Motor DCNC-NEMA23-2.5Nm (RepRapworld.nl artnr: 8719345005800) | K | JA | NEE | NEE | NEE | 00 | 00001 | Link (https://reprapworld.nl/products/motoren_fans/stappenmotoren/nema23_stappenmotor_1_8_stap_30_59_kg_cm/) | T00106-E00-R00 | 00 | E00 | 00106
00107 | Stepper Motor DCNC-NEMA17-0.5Nm (RepRapworld.nl arnr: 8719345003981) | K | JA | NEE | NEE | NEE | 00 | 00003 | Link (https://reprapworld.nl/products/motoren_fans/stepper_motors/nema17_stappenmotor_1_8_stap_stekker_platte_as_5_0_kg_cm/) | T00107-E00-R00 | 00 | E00 | 00107
00108 | Carriage HG15 | K | JA | NEE | NEE | NEE | 00 | 00003 |  | T00108-E00-R00 | 00 | E00 | 00108
00109 | Rail HGR15R l=1530mm | K | JA | NEE | NEE | NEE | 00 | 00001 |  | T00109-E00-R00 | 00 | E00 | 00109
00110 | Rail HGR15R l=270mm | K | JA | NEE | NEE | NEE | 00 | 00003 | https://www.rotar.si/en/SPARE-PARTS-1/50EMB-WOLF-REZILO-SKARIJ | T00110-E00-R00 | 00 | E00 | 00110
00111 | Draaispindel l=240mm | K | JA | NEE | NEE | NEE | 00 | 00003 | https://www.rotar.si/en/SPARE-PARTS-1/50EMB-WOLF-REZILO-SKARIJ | T00111-000-R00 | 00 | 000 | 00111
00112 | Rechthoekig buisprofiel 50x30x2,6x1540mm (hoogte x breedte x dikte x lengte) | M | JA | NEE | NEE | JA | 00 | 00001 | https://www.zilvertron.com/product/ecg2232-12-14-dc-borstelloos/ | T00112-000-R00 | 00 | 000 | 00112
00113 | Vierkant buisprofiel 60x60x3,2x1600mm (hoogte x breedte x dikte x lengte) | M | JA | NEE | NEE | JA | 00 | 00002 |  | T00113-000-R00 | 00 | 000 | 00113
00114 | Voorplaat (2mm dik) | M | JA | DXF | NEE | JA | 00 | 00002 |  | T00114-DXF-R00 | 00 | DXF | 00114
00115 | Achterplaat (2mm dik) | M | JA | DXF | NEE | JA | 01 | 00002 |  | T00115-DXF-R01 | 01 | DXF | 00115
00116 | La magazijn (1mm dik) | M | JA | A4 | NEE | JA | 00 | 00002 |  | T00116-0A4-R00 | 00 | 0A4 | 00116
00117 | u-profiel 30x50x3 | M | JA | NEE | NEE | JA | 00 | 00001 |  | T00117-000-R00 | 00 | 000 | 00117
00118 |  | M | JA | NEE | NEE | JA | 00 | 00001 |  |  | 00 | 000 | 00118
00119 | Strip wielbevestiging (3mm dik) | M | JA | DXF | NEE | JA | 00 | 00001 |  | T00119-DXF-R00 | 00 | DXF | 00119
00120 | Bevestigingsplaat Y as (4mm dik) | M | JA | DXF | NEE | JA | 00 | 00001 |  | T00120-DXF-R00 | 00 | DXF | 00120
00121 | Bevestiging Nema Y as (4mm dik) | M | JA | A4 | NEE | JA | 00 | 00001 |  | T00121-0A4-R00 | 00 | 0A4 | 00121
00122 | Eindplaat rails (4mm dik) | M | JA | DXF | NEE | JA | 00 | 00001 |  | T00122-DXF-R00 | 00 | DXF | 00122
00123 | y-as staaf Ø 16mm | M | JA | A3 | NEE | JA | 01 | 00001 |  | T00123-0A3-R01 | 01 | 0A3 | 00123
00124 | Bevestigingsplaat motor x-as (4mm dik) | M | JA | DXF | NEE | JA | 00 | 00001 |  | T00124-DXF-R00 | 00 | DXF | 00124
00125 | X-as onderkant | M | JA | A4 | NEE | JA | 00 | 00001 |  | T00125-0A4-R00 | 00 | 0A4 | 00125
00126 | Oppikplaat (3mm dik) | M | JA | NEE | NEE | JA | 00 | 00003 |  | T00126-000-R00 | 00 | 000 | 00126
00127 | lager binnenØ 15mm DIN 625 6002 | K | JA | NEE | NEE | NEE | 00 | 00003 |  | T00127-E00-R00 | 00 | E00 | 00127
00128 | As rotatie r richting | M | JA | A4 | NEE | JA | 00 | 00003 |  | T00128-0A4-R00 | 00 | 0A4 | 00128
00129 | Zegering | K | JA | NEE | NEE | NEE | 00 | 00003 |  | T00129-E00-R00 | 00 | E00 | 00129
00130 | Draaiflens | M | JA | A4 | NEE | JA | 00 | 00003 |  | T00130-0A4-R00 | 00 | 0A4 | 00130
00131 | Reely Stalen tandwiel Boor-Ø = 5mm (Conrad artnr: 240311) | K | JA | NEE | NEE | NEE | 00 | 00003 |  | T00131-E00-R00 | 00 | E00 | 00131
00132 | Reely polyacetaal tandwiel Boor-Ø = 8mm (Conrad artnr: 1515292) | K | JA | NEE | NEE | NEE | 00 | 00003 | Link (https://www.conrad.nl/p/polyacetaal-recht-tandwiel-reely-soort-module-10-boordiameter-8-mm-aantal-tanden-60-1515292) | T00132-E00-R00 | 00 | E00 | 00132
00133 | Plateau stappenmotor R-as (3mm) | M | JA | A4 | NEE | JA | 00 | 00003 |  | T00133-0A4-R00 | 00 | 0A4 | 00133
00134 | Zijplaat plateau (3mm) | M | JA | DXF | NEE | JA | 00 | 00003 |  | T00134-DXF-R00 | 00 | DXF | 00134
00135 | Plaat draaiplateau (3mm) | M | JA | DXF | NEE | JA | 00 | 00003 |  | T00135-DXF-R00 | 00 | DXF | 00135
00136 | Meenemer tandriem (3mm) | M | JA | DXF | NEE | JA | 01 | 00003 |  | T00136-DXF-R01 | 01 | DXF | 00136
00137 | Oplasplaat plateau stappenmotor | M | JA | NEE | NEE | JA | 00 | 00003 |  | T00137-000-R00 | 00 | 000 | 00137
00138 | Oplasplaat plateau stappenmotor gespiegeld | M | JA | NEE | NEE | JA | 00 | 00003 |  | T00138-000-R00 | 00 | 000 | 00138
00139 | Zijplaat magazijn (2mm) | M | JA | DXF | NEE | JA | 00 | 00002 |  | T00139-DXF-R00 | 00 | DXF | 00139
00140 | Top- en onderplaat magazijn (2mm) | M | JA | A4 | NEE | JA | 00 | 00002 |  | T00140-0A4-R00 | 00 | 0A4 | 00140
00141 | Voetje | K | JA | NEE | NEE | NEE | 00 | 00002 |  | T00141-E00-R00 | 00 | E00 | 00141
00142 | Zijplaat rechtsonder (4mm) | M | JA | A4 | NEE | JA | 00 |  |  | T00142-0A4-R00 | 00 | 0A4 | 00142
00143 | Zijplaat links (4mm) | M | JA | DXF | NEE | JA | 00 |  |  | T00143-DXF-R00 | 00 | DXF | 00143
00144 | Zijplaat rechtsboven (4mm) | M | JA | A4 | NEE | JA | 00 |  |  | T00144-0A4-R00 | 00 | 0A4 | 00144
00145 | Reely Kogellager radiaal Chroomstaal Binnen binnenØ 8mm, buitenØ 22mm (Conrad artnr: 214477) | K | JA | NEE | NEE | NEE | 00 |  |  | T00145-E00-R00 | 00 | E00 | 00145
00146 | Rittal AE 1045.500 schakelkast 400x500x210mm (Conrad artnr:531738) | K/M | JA | NEE | NEE | NEE | 00 |  |  | T00146-E00-R00 | 00 | E00 | 00146
00147 | Vloer [referentie] |  | JA | NEE | NEE | NEE | 00 |  |  | T00147-E00-R00 | 00 | E00 | 00147
00148 | Bakje | K | JA | NEE | NEE | NEE | 00 | 00003 |  | T00148-E00-R00 | 00 | E00 | 00148
00149 | Panasonic PM-Y65-P Infrarood gate sensor (Conrad artnr: 1547442) | K | JA | NEE | NEE | NEE | 00 | 00001 | Link (https://www.conrad.nl/p/panasonic-pm-y65-p-vorklichtsluis-y-type-lichtschakelend-donkerschakelend-5-24-vdc-1-stuks-1547442) | T00149-E00-R00 | 00 | E00 | 00149
00150 | Eindstop X-as links (X+) en rechts (X-) | M | JA | NEE | JA | JA | 00 | 00001 |  | T00150-03D-R00 | 00 | 03D | 00150
00151 | Bracket eindstop Y boven (Y+) | M | JA | NEE | JA | JA | 00 | 00001 |  | T00151-03D-R00 | 00 | 03D | 00151
00152 | Bracket eindstop Y onder (Y-) | M | JA | NEE | JA | JA | 00 | 00001 |  | T00152-03D-R00 | 00 | 03D | 00152
00153 | Panasonic PM-F65W-P infrarood gate sensor (Conrad artnr: 1547476) | K | JA | NEE | NEE | NEE | 00 | 00001 |  | T00153-E00-R00 | 00 | E00 | 00153
00154 | Barcode Scanner Module - 1D/2D Codes Reader (Kiwi electronics artnr:WS-14810) | K | JA | NEE | NEE | NEE | 01 |  | Link (https://www.kiwi-electronics.nl/barcode-scanner-14810) | T00154-E00-R01 | 01 | E00 | 00154
00155 | Onderplaat weegschaal | M | JA | A4 | NEE | JA | 00 |  |  | T00155-0A4-R00 | 00 | 0A4 | 00155
00156 | Bovenplaat weegschaal | M | JA | NEE | NEE | JA | 00 |  |  | T00156-000-R00 | 00 | 000 | 00156
00157 | Load cell 5kg (Tinytronics artnr: 000951) | K | JA | NEE | NEE | NEE | 00 |  | Link (https://www.tinytronics.nl/shop/nl/sensoren/gewicht-druk-kracht/load-cell-5kg) | T00157-E00-R00 | 00 | E00 | 00157
00158 | Achterplaat 1v2 (2mm dik) | M | JA | DXF | NEE | JA | 00 | 0155 |  | T00158-DXF-R00 | 00 | DXF | 00158
00159 | Achterplaat 1v2 (2mm dik) | M | JA | DXF | NEE | JA | 00 | 0155 |  | T00159-DXF-R00 | 00 | DXF | 00159
00160 | Nema 24 Stappenmotor 4.0Nm(566 oz.in) w/ Rem Wrijvingskoppel 2.0Nm(283oz.in) (Stepperonline artnr: 24HS39-4204D-B200) | K | JA | NEE | NEE | NEE | 00 |  |  | T00160-E00-R00 | 00 | E00 | 00160
00161 | Bracket eindstop R as (R+ en R-) | M | JA | A4 | NEE | JA | 00 | 00003 |  | T00161-0A4-R00 | 00 | 0A4 | 00161
00162 | Eindstop R as (R+ of R-) | M | JA | NEE | JA | JA | 03 |  |  | T00162-03D-R03 | 03 | 03D | 00162
00163 | Eindstop Z | M | JA | NEE | JA | JA | 02 |  |  | T00163-03D-R02 | 02 | 03D | 00163
00164 | Eindstop houder R+ | M | JA | NEE | JA | JA | 00 |  |  | T00164-03D-R00 | 00 | 03D | 00164
00165 | Eindstop houder R- | M | JA | NEE | JA | JA | 00 |  |  | T00165-03D-R00 | 00 | 03D | 00165
00166 | HabaSYNC T10 Conveyer timing belt (Misumi) | K | JA | NEE | NEE | NEE | 00 | 00001 | Link (https://uk.misumi-ec.com/vona2/detail/221000419357/?CategorySpec=00000049757%3a%3ai) | T00166-E00-R00 | 00 | E00 | 00166
00167 | Bevestigingsplaat connectoren | M | JA | A4 | NEE | JA | 00 |  |  | T00167-0A4-R00 | 00 | 0A4 | 00167
00168 | Hoeksteun eindstop Z | M | JA | NEE | JA | JA | 01 | 00003 |  | T00168-03D-R01 | 01 | 03D | 00168
00169 | 7 inch HDMi Display-c 1024x600 pixel USB touch (Tinytronics) | K | JA | NEE | NEE | NEE | 00 | 00007 | Link (https://www.tinytronics.nl/shop/nl/raspberry-pi/7-inch-lcd-display-1024*600-pixels-met-touchscreen-raspberry-pi-compatible) | T00169-E00-R00 | 00 | E00 | 00169
00170 | Cover 7 inch Display | M | JA | NEE | JA | JA | 00 | 00000 |  | T00170-03D-R00 | 00 | 03D | 00170
00171 | Barcode scanner case bottom | M | JA | NEE | NEE | JA | 01 |  |  | T00171-000-R01 | 01 | 000 | 00171
00172 | Barcode scanner case top | M | JA | NEE | NEE | JA | 01 |  |  | T00172-000-R01 | 01 | 000 | 00172
00173 | Barcode scanner case button | M | JA | NEE | NEE | JA | 01 |  |  | T00173-000-R01 | 01 | 000 | 00173
00174 |  |  |  |  |  |  |  |  |  |  |  | Error | 00174
00175 |  |  |  |  |  |  |  |  |  |  |  | Error | 00175
00176 |  |  |  |  |  |  |  |  |  |  |  | Error | 00176
00177 |  |  |  |  |  |  |  |  |  |  |  | Error | 00177
00178 |  |  |  |  |  |  |  |  |  |  |  | Error | 00178
00179 |  |  |  |  |  |  |  |  |  |  |  | Error | 00179
00180 |  |  |  |  |  |  |  |  |  |  |  | Error | 00180
00181 |  |  |  |  |  |  |  |  |  |  |  | Error | 00181
00182 |  |  |  |  |  |  |  |  |  |  |  | Error | 00182
00183 |  |  |  |  |  |  |  |  |  |  |  | Error | 00183
00184 |  |  |  |  |  |  |  |  |  |  |  | Error | 00184
00185 |  |  |  |  |  |  |  |  |  |  |  | Error | 00185
00186 |  |  |  |  |  |  |  |  |  |  |  | Error | 00186
00187 |  |  |  |  |  |  |  |  |  |  |  | Error | 00187
00188 |  |  |  |  |  |  |  |  |  |  |  | Error | 00188
00189 |  |  |  |  |  |  |  |  |  |  |  | Error | 00189
00190 |  |  |  |  |  |  |  |  |  |  |  | Error | 00190
00191 |  |  |  |  |  |  |  |  |  |  |  | Error | 00191
00192 |  |  |  |  |  |  |  |  |  |  |  | Error | 00192
00193 |  |  |  |  |  |  |  |  |  |  |  | Error | 00193
00194 |  |  |  |  |  |  |  |  |  |  |  | Error | 00194
00195 |  |  |  |  |  |  |  |  |  |  |  | Error | 00195
00196 |  |  |  |  |  |  |  |  |  |  |  | Error | 00196
00197 |  |  |  |  |  |  |  |  |  |  |  | Error | 00197
00198 |  |  |  |  |  |  |  |  |  |  |  | Error | 00198
00199 |  |  |  |  |  |  |  |  |  |  |  | Error | 00199
00200 |  |  |  |  |  |  |  |  |  |  |  | Error | 00200
00201 |  |  |  |  |  |  |  |  |  |  |  | Error | 00201
00202 |  |  |  |  |  |  |  |  |  |  |  | Error | 00202
00203 |  |  |  |  |  |  |  |  |  |  |  | Error | 00203
00204 |  |  |  |  |  |  |  |  |  |  |  | Error | 00204
00205 |  |  |  |  |  |  |  |  |  |  |  | Error | 00205
00206 |  |  |  |  |  |  |  |  |  |  |  | Error | 00206
00207 |  |  |  |  |  |  |  |  |  |  |  | Error | 00207
00208 |  |  |  |  |  |  |  |  |  |  |  | Error | 00208
00209 |  |  |  |  |  |  |  |  |  |  |  | Error | 00209
00210 |  |  |  |  |  |  |  |  |  |  |  | Error | 00210
00211 |  |  |  |  |  |  |  |  |  |  |  | Error | 00211
00212 |  |  |  |  |  |  |  |  |  |  |  | Error | 00212
00213 |  |  |  |  |  |  |  |  |  |  |  | Error | 00213
00214 |  |  |  |  |  |  |  |  |  |  |  | Error | 00214
00215 |  |  |  |  |  |  |  |  |  |  |  | Error | 00215
00216 |  |  |  |  |  |  |  |  |  |  |  | Error | 00216
00217 |  |  |  |  |  |  |  |  |  |  |  | Error | 00217
00218 |  |  |  |  |  |  |  |  |  |  |  | Error | 00218
00219 |  |  |  |  |  |  |  |  |  |  |  | Error | 00219
00220 |  |  |  |  |  |  |  |  |  |  |  | Error | 00220
00221 |  |  |  |  |  |  |  |  |  |  |  | Error | 00221
00222 |  |  |  |  |  |  |  |  |  |  |  | Error | 00222
00223 |  |  |  |  |  |  |  |  |  |  |  | Error | 00223
00224 |  |  |  |  |  |  |  |  |  |  |  | Error | 00224
00225 |  |  |  |  |  |  |  |  |  |  |  | Error | 00225
00226 |  |  |  |  |  |  |  |  |  |  |  | Error | 00226
00227 |  |  |  |  |  |  |  |  |  |  |  | Error | 00227
00228 |  |  |  |  |  |  |  |  |  |  |  | Error | 00228
00229 |  |  |  |  |  |  |  |  |  |  |  | Error | 00229
00230 |  |  |  |  |  |  |  |  |  |  |  | Error | 00230
00231 |  |  |  |  |  |  |  |  |  |  |  | Error | 00231
00232 |  |  |  |  |  |  |  |  |  |  |  | Error | 00232
00233 |  |  |  |  |  |  |  |  |  |  |  | Error | 00233
00234 |  |  |  |  |  |  |  |  |  |  |  | Error | 00234
00235 |  |  |  |  |  |  |  |  |  |  |  | Error | 00235
00236 |  |  |  |  |  |  |  |  |  |  |  | Error | 00236
00237 |  |  |  |  |  |  |  |  |  |  |  | Error | 00237
00238 |  |  |  |  |  |  |  |  |  |  |  | Error | 00238
00239 |  |  |  |  |  |  |  |  |  |  |  | Error | 00239
00240 |  |  |  |  |  |  |  |  |  |  |  | Error | 00240
00241 |  |  |  |  |  |  |  |  |  |  |  | Error | 00241
00242 |  |  |  |  |  |  |  |  |  |  |  | Error | 00242
00243 |  |  |  |  |  |  |  |  |  |  |  | Error | 00243
00244 |  |  |  |  |  |  |  |  |  |  |  | Error | 00244
00245 |  |  |  |  |  |  |  |  |  |  |  | Error | 00245
00246 |  |  |  |  |  |  |  |  |  |  |  | Error | 00246
00247 |  |  |  |  |  |  |  |  |  |  |  | Error | 00247
00248 |  |  |  |  |  |  |  |  |  |  |  | Error | 00248
00249 |  |  |  |  |  |  |  |  |  |  |  | Error | 00249
00250 |  |  |  |  |  |  |  |  |  |  |  | Error | 00250
00251 |  |  |  |  |  |  |  |  |  |  |  | Error | 00251
00252 |  |  |  |  |  |  |  |  |  |  |  | Error | 00252
00253 |  |  |  |  |  |  |  |  |  |  |  | Error | 00253
00254 |  |  |  |  |  |  |  |  |  |  |  | Error | 00254
00255 |  |  |  |  |  |  |  |  |  |  |  | Error | 00255
00256 |  |  |  |  |  |  |  |  |  |  |  | Error | 00256
00257 |  |  |  |  |  |  |  |  |  |  |  | Error | 00257
00258 |  |  |  |  |  |  |  |  |  |  |  | Error | 00258
00259 |  |  |  |  |  |  |  |  |  |  |  | Error | 00259
00260 |  |  |  |  |  |  |  |  |  |  |  | Error | 00260
00261 |  |  |  |  |  |  |  |  |  |  |  | Error | 00261
00262 |  |  |  |  |  |  |  |  |  |  |  | Error | 00262
00263 |  |  |  |  |  |  |  |  |  |  |  | Error | 00263
00264 |  |  |  |  |  |  |  |  |  |  |  | Error | 00264
00265 |  |  |  |  |  |  |  |  |  |  |  | Error | 00265
00266 |  |  |  |  |  |  |  |  |  |  |  | Error | 00266
00267 |  |  |  |  |  |  |  |  |  |  |  | Error | 00267
00268 |  |  |  |  |  |  |  |  |  |  |  | Error | 00268
00269 |  |  |  |  |  |  |  |  |  |  |  | Error | 00269
00270 |  |  |  |  |  |  |  |  |  |  |  | Error | 00270
00271 |  |  |  |  |  |  |  |  |  |  |  | Error | 00271
00272 |  |  |  |  |  |  |  |  |  |  |  | Error | 00272
00273 |  |  |  |  |  |  |  |  |  |  |  | Error | 00273
00274 |  |  |  |  |  |  |  |  |  |  |  | Error | 00274
00275 |  |  |  |  |  |  |  |  |  |  |  | Error | 00275
00276 |  |  |  |  |  |  |  |  |  |  |  | Error | 00276
00277 |  |  |  |  |  |  |  |  |  |  |  | Error | 00277
00278 |  |  |  |  |  |  |  |  |  |  |  | Error | 00278
00279 |  |  |  |  |  |  |  |  |  |  |  | Error | 00279
00280 |  |  |  |  |  |  |  |  |  |  |  | Error | 00280
00281 |  |  |  |  |  |  |  |  |  |  |  | Error | 00281
00282 |  |  |  |  |  |  |  |  |  |  |  | Error | 00282
00283 |  |  |  |  |  |  |  |  |  |  |  | Error | 00283
00284 |  |  |  |  |  |  |  |  |  |  |  | Error | 00284
00285 |  |  |  |  |  |  |  |  |  |  |  | Error | 00285
00286 |  |  |  |  |  |  |  |  |  |  |  | Error | 00286
00287 |  |  |  |  |  |  |  |  |  |  |  | Error | 00287
00288 |  |  |  |  |  |  |  |  |  |  |  | Error | 00288
00289 |  |  |  |  |  |  |  |  |  |  |  | Error | 00289
00290 |  |  |  |  |  |  |  |  |  |  |  | Error | 00290
00291 |  |  |  |  |  |  |  |  |  |  |  | Error | 00291
00292 |  |  |  |  |  |  |  |  |  |  |  | Error | 00292
00293 |  |  |  |  |  |  |  |  |  |  |  | Error | 00293
00294 |  |  |  |  |  |  |  |  |  |  |  | Error | 00294
00295 |  |  |  |  |  |  |  |  |  |  |  | Error | 00295
00296 |  |  |  |  |  |  |  |  |  |  |  | Error | 00296
00297 |  |  |  |  |  |  |  |  |  |  |  | Error | 00297
00298 |  |  |  |  |  |  |  |  |  |  |  | Error | 00298
00299 |  |  |  |  |  |  |  |  |  |  |  | Error | 00299
00300 |  |  |  |  |  |  |  |  |  |  |  | Error | 00300
00301 |  |  |  |  |  |  |  |  |  |  |  | Error | 00301
00302 |  |  |  |  |  |  |  |  |  |  |  | Error | 00302
00303 |  |  |  |  |  |  |  |  |  |  |  | Error | 00303
00304 |  |  |  |  |  |  |  |  |  |  |  | Error | 00304
00305 |  |  |  |  |  |  |  |  |  |  |  | Error | 00305
00306 |  |  |  |  |  |  |  |  |  |  |  | Error | 00306
00307 |  |  |  |  |  |  |  |  |  |  |  | Error | 00307
00308 |  |  |  |  |  |  |  |  |  |  |  | Error | 00308
00309 |  |  |  |  |  |  |  |  |  |  |  | Error | 00309
00310 |  |  |  |  |  |  |  |  |  |  |  | Error | 00310
00311 |  |  |  |  |  |  |  |  |  |  |  | Error | 00311
00312 |  |  |  |  |  |  |  |  |  |  |  | Error | 00312
00313 |  |  |  |  |  |  |  |  |  |  |  | Error | 00313
00314 |  |  |  |  |  |  |  |  |  |  |  | Error | 00314
00315 |  |  |  |  |  |  |  |  |  |  |  | Error | 00315
00316 |  |  |  |  |  |  |  |  |  |  |  | Error | 00316
00317 |  |  |  |  |  |  |  |  |  |  |  | Error | 00317
00318 |  |  |  |  |  |  |  |  |  |  |  | Error | 00318
00319 |  |  |  |  |  |  |  |  |  |  |  | Error | 00319
00320 |  |  |  |  |  |  |  |  |  |  |  | Error | 00320
00321 |  |  |  |  |  |  |  |  |  |  |  | Error | 00321
00322 |  |  |  |  |  |  |  |  |  |  |  | Error | 00322
00323 |  |  |  |  |  |  |  |  |  |  |  | Error | 00323
00324 |  |  |  |  |  |  |  |  |  |  |  | Error | 00324
00325 |  |  |  |  |  |  |  |  |  |  |  | Error | 00325
00326 |  |  |  |  |  |  |  |  |  |  |  | Error | 00326
00327 |  |  |  |  |  |  |  |  |  |  |  | Error | 00327
00328 |  |  |  |  |  |  |  |  |  |  |  | Error | 00328
00329 |  |  |  |  |  |  |  |  |  |  |  | Error | 00329
00330 |  |  |  |  |  |  |  |  |  |  |  | Error | 00330
00331 |  |  |  |  |  |  |  |  |  |  |  | Error | 00331
00332 |  |  |  |  |  |  |  |  |  |  |  | Error | 00332
00333 |  |  |  |  |  |  |  |  |  |  |  | Error | 00333
00334 |  |  |  |  |  |  |  |  |  |  |  | Error | 00334
00335 |  |  |  |  |  |  |  |  |  |  |  | Error | 00335
00336 |  |  |  |  |  |  |  |  |  |  |  | Error | 00336
00337 |  |  |  |  |  |  |  |  |  |  |  | Error | 00337
00338 |  |  |  |  |  |  |  |  |  |  |  | Error | 00338
00339 |  |  |  |  |  |  |  |  |  |  |  | Error | 00339
00340 |  |  |  |  |  |  |  |  |  |  |  | Error | 00340
00341 |  |  |  |  |  |  |  |  |  |  |  | Error | 00341
00342 |  |  |  |  |  |  |  |  |  |  |  | Error | 00342
00343 |  |  |  |  |  |  |  |  |  |  |  | Error | 00343
00344 |  |  |  |  |  |  |  |  |  |  |  | Error | 00344
00345 |  |  |  |  |  |  |  |  |  |  |  | Error | 00345
00346 |  |  |  |  |  |  |  |  |  |  |  | Error | 00346
00347 |  |  |  |  |  |  |  |  |  |  |  | Error | 00347
00348 |  |  |  |  |  |  |  |  |  |  |  | Error | 00348
00349 |  |  |  |  |  |  |  |  |  |  |  | Error | 00349
00350 |  |  |  |  |  |  |  |  |  |  |  | Error | 00350
00351 |  |  |  |  |  |  |  |  |  |  |  | Error | 00351
00352 |  |  |  |  |  |  |  |  |  |  |  | Error | 00352
00353 |  |  |  |  |  |  |  |  |  |  |  | Error | 00353
00354 |  |  |  |  |  |  |  |  |  |  |  | Error | 00354
00355 |  |  |  |  |  |  |  |  |  |  |  | Error | 00355
00356 |  |  |  |  |  |  |  |  |  |  |  | Error | 00356
00357 |  |  |  |  |  |  |  |  |  |  |  | Error | 00357
00358 |  |  |  |  |  |  |  |  |  |  |  | Error | 00358
00359 |  |  |  |  |  |  |  |  |  |  |  | Error | 00359
00360 |  |  |  |  |  |  |  |  |  |  |  | Error | 00360
00361 |  |  |  |  |  |  |  |  |  |  |  | Error | 00361
00362 |  |  |  |  |  |  |  |  |  |  |  | Error | 00362
00363 |  |  |  |  |  |  |  |  |  |  |  | Error | 00363
00364 |  |  |  |  |  |  |  |  |  |  |  | Error | 00364
00365 |  |  |  |  |  |  |  |  |  |  |  | Error | 00365
00366 |  |  |  |  |  |  |  |  |  |  |  | Error | 00366
00367 |  |  |  |  |  |  |  |  |  |  |  | Error | 00367
00368 |  |  |  |  |  |  |  |  |  |  |  | Error | 00368
00369 |  |  |  |  |  |  |  |  |  |  |  | Error | 00369
00370 |  |  |  |  |  |  |  |  |  |  |  | Error | 00370
00371 |  |  |  |  |  |  |  |  |  |  |  | Error | 00371
00372 |  |  |  |  |  |  |  |  |  |  |  | Error | 00372
00373 |  |  |  |  |  |  |  |  |  |  |  | Error | 00373
00374 |  |  |  |  |  |  |  |  |  |  |  | Error | 00374
00375 |  |  |  |  |  |  |  |  |  |  |  | Error | 00375
00376 |  |  |  |  |  |  |  |  |  |  |  | Error | 00376
00377 |  |  |  |  |  |  |  |  |  |  |  | Error | 00377
00378 |  |  |  |  |  |  |  |  |  |  |  | Error | 00378
00379 |  |  |  |  |  |  |  |  |  |  |  | Error | 00379
00380 |  |  |  |  |  |  |  |  |  |  |  | Error | 00380
00381 |  |  |  |  |  |  |  |  |  |  |  | Error | 00381
00382 |  |  |  |  |  |  |  |  |  |  |  | Error | 00382
00383 |  |  |  |  |  |  |  |  |  |  |  | Error | 00383
00384 |  |  |  |  |  |  |  |  |  |  |  | Error | 00384
00385 |  |  |  |  |  |  |  |  |  |  |  | Error | 00385
00386 |  |  |  |  |  |  |  |  |  |  |  | Error | 00386
00387 |  |  |  |  |  |  |  |  |  |  |  | Error | 00387
00388 |  |  |  |  |  |  |  |  |  |  |  | Error | 00388
00389 |  |  |  |  |  |  |  |  |  |  |  | Error | 00389
00390 |  |  |  |  |  |  |  |  |  |  |  | Error | 00390
00391 |  |  |  |  |  |  |  |  |  |  |  | Error | 00391
00392 |  |  |  |  |  |  |  |  |  |  |  | Error | 00392
00393 |  |  |  |  |  |  |  |  |  |  |  | Error | 00393
00394 |  |  |  |  |  |  |  |  |  |  |  | Error | 00394
00395 |  |  |  |  |  |  |  |  |  |  |  | Error | 00395
00396 |  |  |  |  |  |  |  |  |  |  |  | Error | 00396
00397 |  |  |  |  |  |  |  |  |  |  |  | Error | 00397
00398 |  |  |  |  |  |  |  |  |  |  |  | Error | 00398
00399 |  |  |  |  |  |  |  |  |  |  |  | Error | 00399
00400 |  |  |  |  |  |  |  |  |  |  |  | Error | 00400
00401 |  |  |  |  |  |  |  |  |  |  |  | Error | 00401
00402 |  |  |  |  |  |  |  |  |  |  |  | Error | 00402
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

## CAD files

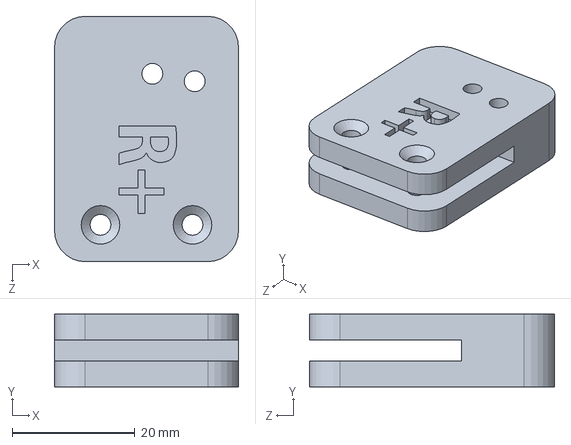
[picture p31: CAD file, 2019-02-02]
CAD Files/CAD LMI/Archief/s.SLDPRT
30.0 x 11.9 x 40.0 mm

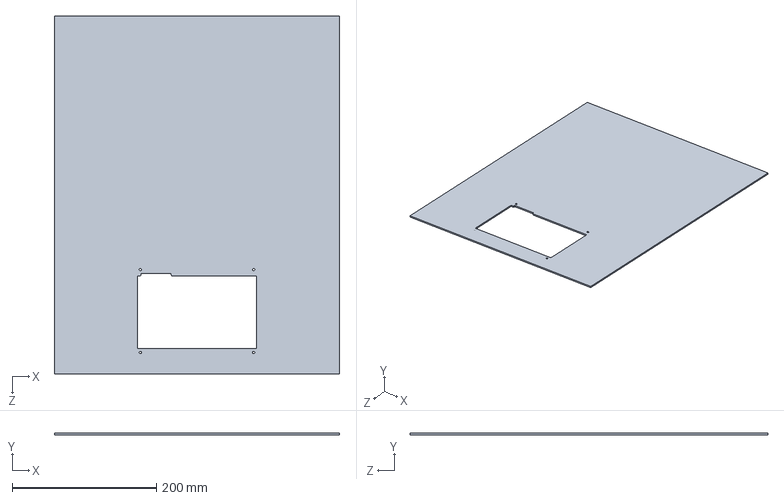
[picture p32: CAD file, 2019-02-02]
CAD Files/CAD LMI/DXF/Gat elektrokast.SLDPRT
395.0 x 2.50 x 496.0 mm

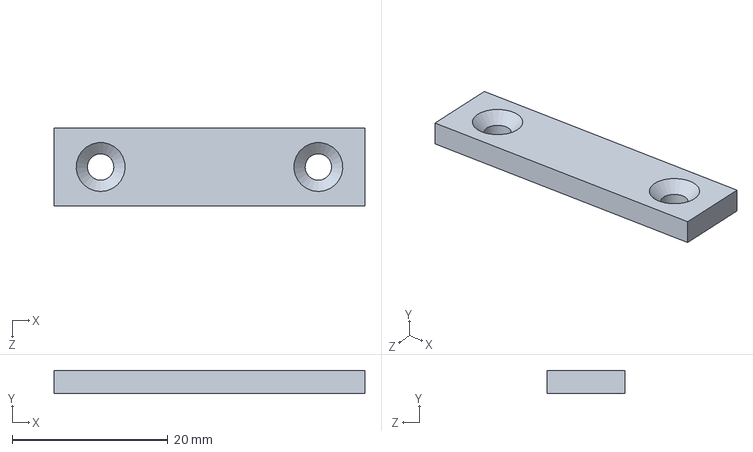
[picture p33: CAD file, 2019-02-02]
CAD Files/CAD LMI/Part1.SLDPRT
40.0 x 3.00 x 10.0 mm

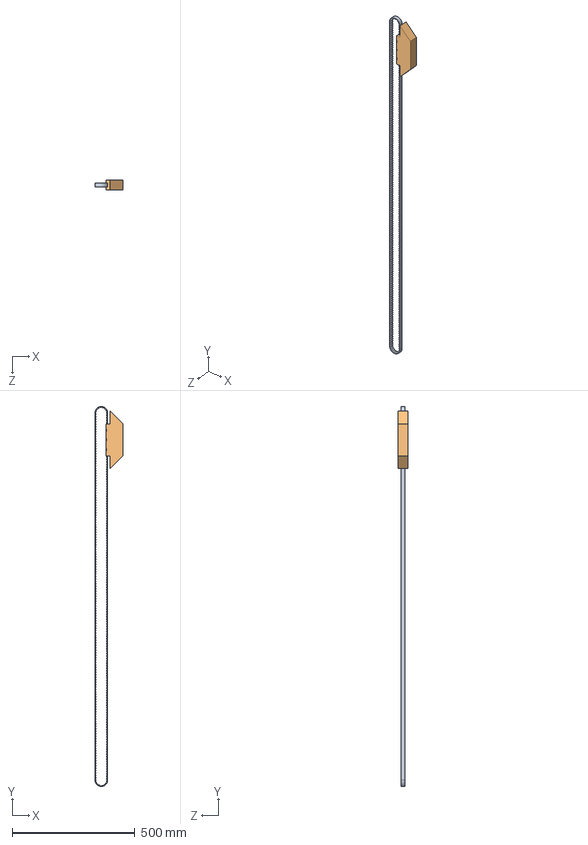
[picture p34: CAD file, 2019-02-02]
CAD Files/CAD LMI/Archief/T00005-0A3-R00.SLDASM
114.5 x 1547.1 x 40.0 mm
T00166-E00-R00
T00164-0A3-R00
T00165-0A4-R00 x 3
countersunk flat head cross recess screw_din x 9

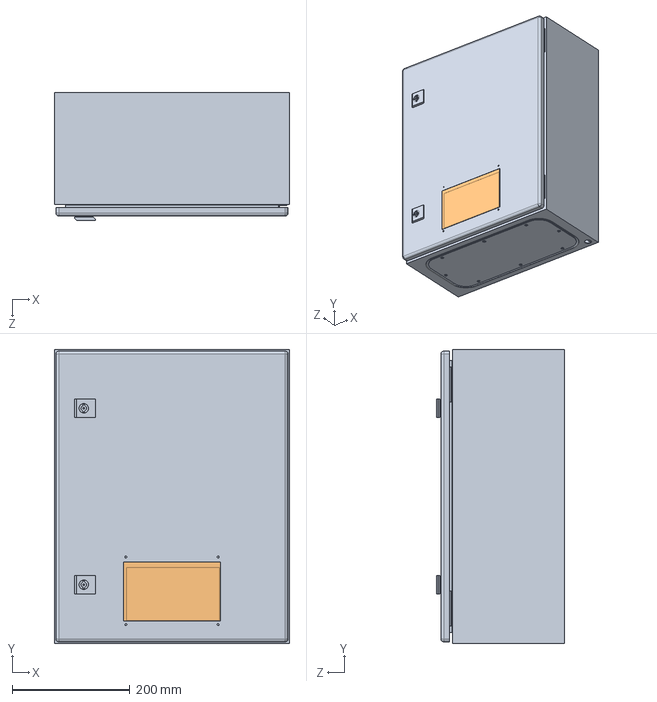
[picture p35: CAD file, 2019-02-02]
CAD Files/CAD LMI/T00007-000-R00.SLDASM
400.0 x 500.0 x 217.0 mm
T00146-E00-R00
T00169-E00-R00

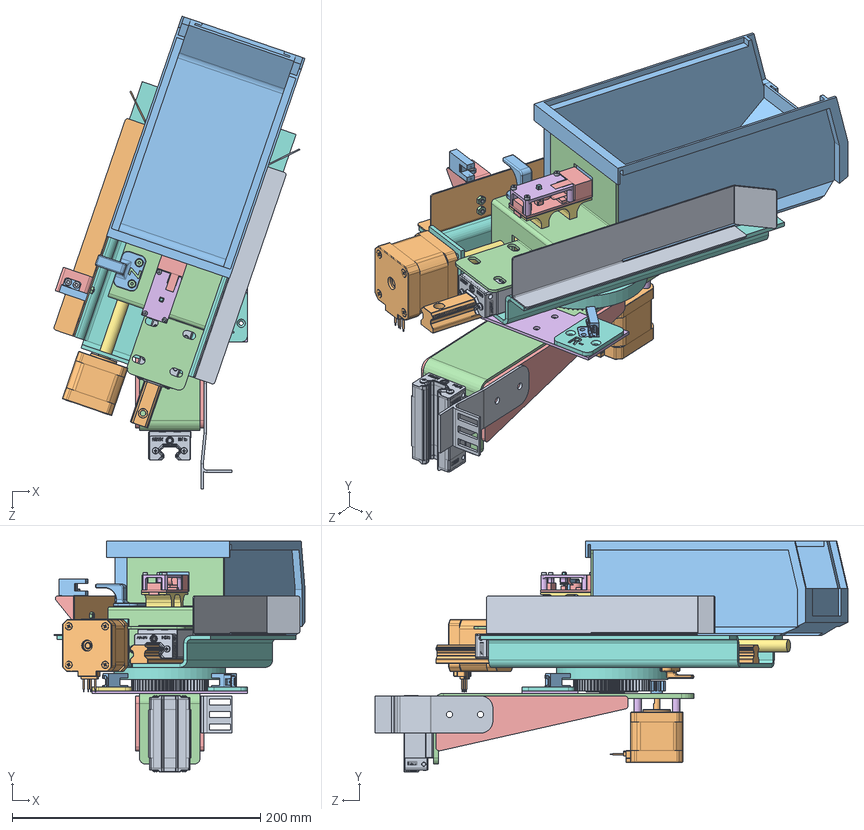
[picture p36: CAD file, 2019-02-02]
CAD Files/CAD LMI/T00003-000-R02.SLDASM
202.2 x 185.9 x 380.8 mm
T00108-E00-R00 x 2
T00110-E00-R00
T00148-E00-R00
T00126-000-R02
T00154-E00-R01
T00172-000-R01
T00171-000-R01
T00173-000-R01
socket head cap screw_iso x 9
hex thin nut chamfered gradeab_iso x 4
T00163-03D-R01
socket countersunk head screw_iso x 2
T00127-E00-R00
T00128-0A4-R00
T00129-E00-R00
T00130-0A4-R01
T00132-E00-R00
T00107-E00-R00 x 2
T00131-E00-R00
T00133-0A4-R00
T00134-DXF-R00 x 2
T00105-E00-R00 x 4
T00111-E00-R00
T00135-DXF-R01
T00136-DXF-R01
T00138-000-R00
T00153-E00-R00 x 3
hex nut style 1 gradeab_iso x 4
T00168-03D-R00
T00161-0A4-R00
T00164-03D-R00
T00165-03D-R00
T00137-000-R00
T00162-03D-R03

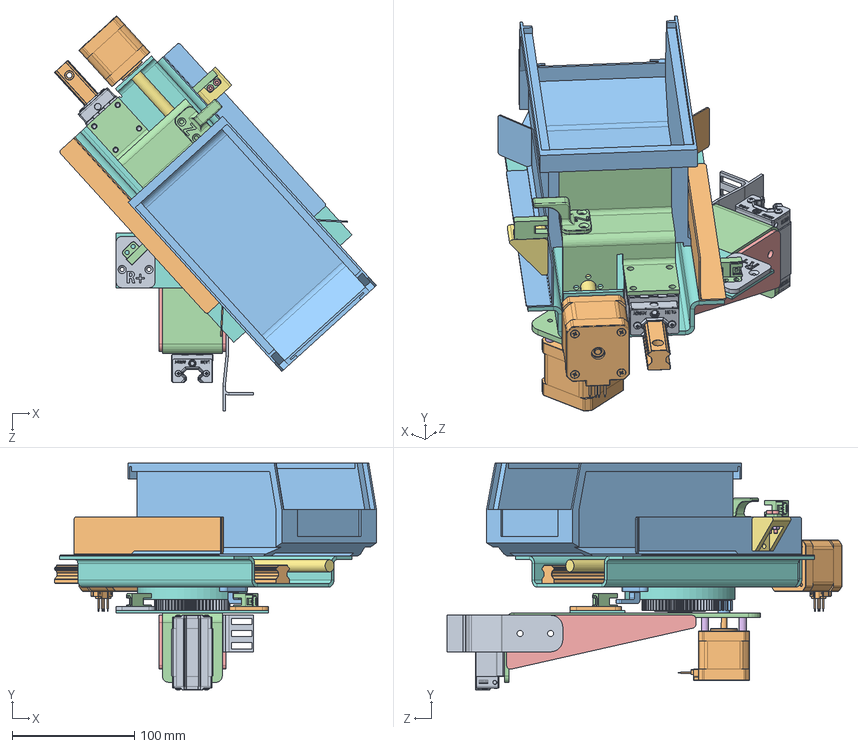
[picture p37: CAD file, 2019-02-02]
CAD Files/CAD LMI/T00003-000-R01.SLDASM
263.8 x 185.9 x 323.5 mm
T00108-E00-R00 x 2
T00110-E00-R00
T00148-E00-R00
T00126-000-R00
T00127-E00-R00
T00128-0A4-R00
T00129-E00-R00
T00130-0A4-R01
T00132-E00-R00
T00107-E00-R00 x 2
T00131-E00-R00
T00133-0A4-R00
T00134-DXF-R00 x 2
T00105-E00-R00 x 4
T00111-E00-R00
T00135-DXF-R01
T00136-DXF-R01
T00137-000-R00
T00138-000-R00
T00153-E00-R00 x 3
socket head cap screw_iso x 2
hex nut style 1 gradeab_iso x 2
T00168-03D-R00
T00161-0A4-R00
T00164-03D-R00
T00165-03D-R00
T00162-03D-R02
T00163-03D-R01

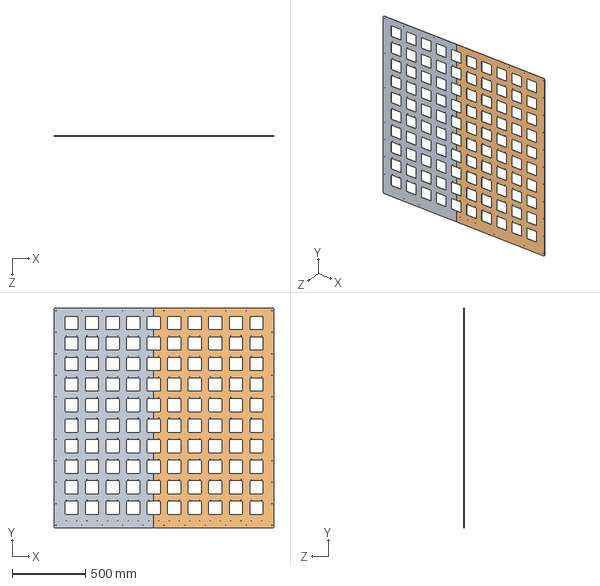
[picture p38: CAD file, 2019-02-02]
CAD Files/CAD LMI/T00115-DXF-R01.SLDASM
1500.0 x 1500.0 x 2.00 mm
T00158-DXF-R00
T00159-DXF-R00

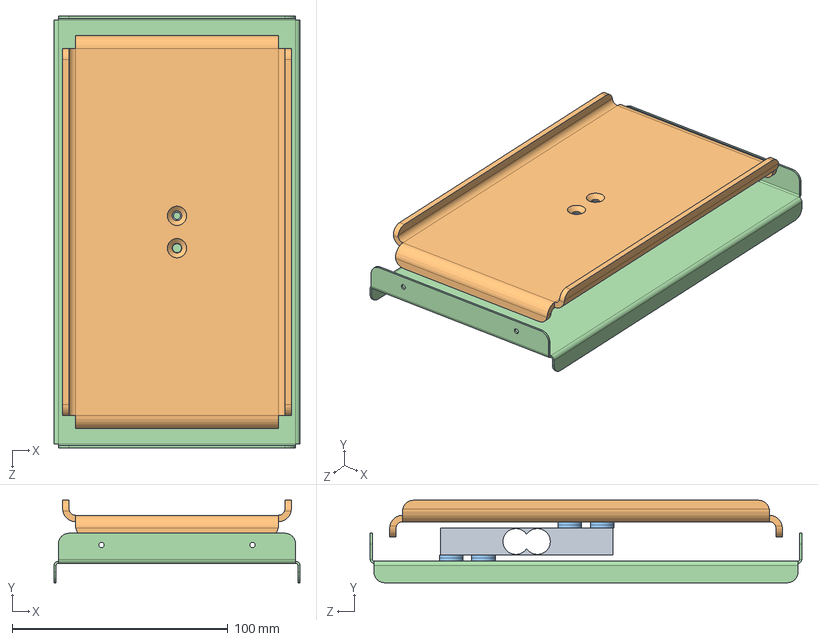
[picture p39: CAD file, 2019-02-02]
CAD Files/CAD LMI/T00004-000-R00.SLDASM
114.0 x 38.3 x 200.0 mm
T00157-E00-R00
T00156-000-R00
flat washer narrow_am x 8
T00155-0A3-R00

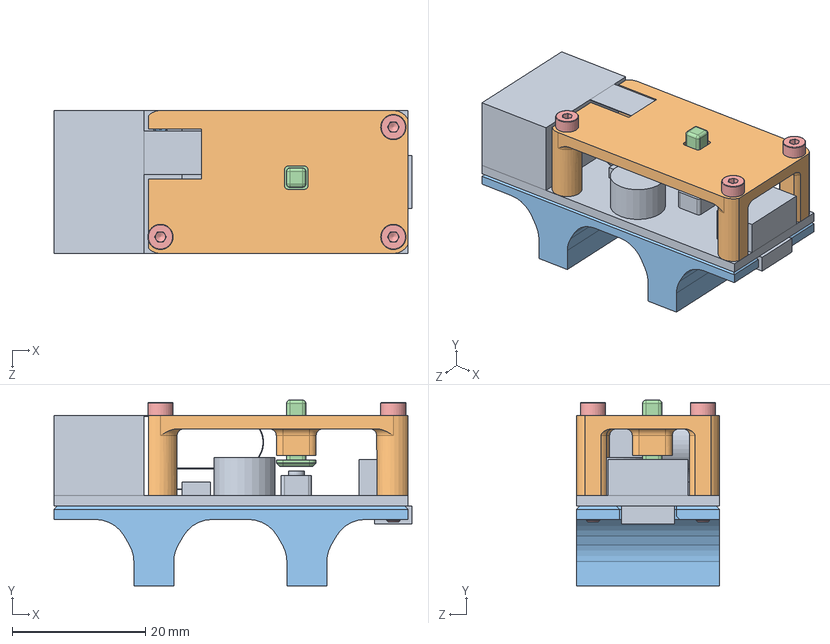
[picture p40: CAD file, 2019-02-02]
CAD Files/CAD LMI/T00005-000-R00.SLDASM
53.8 x 27.9 x 21.5 mm
T00154-E00-R01
T00172-000-R01
T00171-000-R01
T00173-000-R01
socket head cap screw_iso x 3

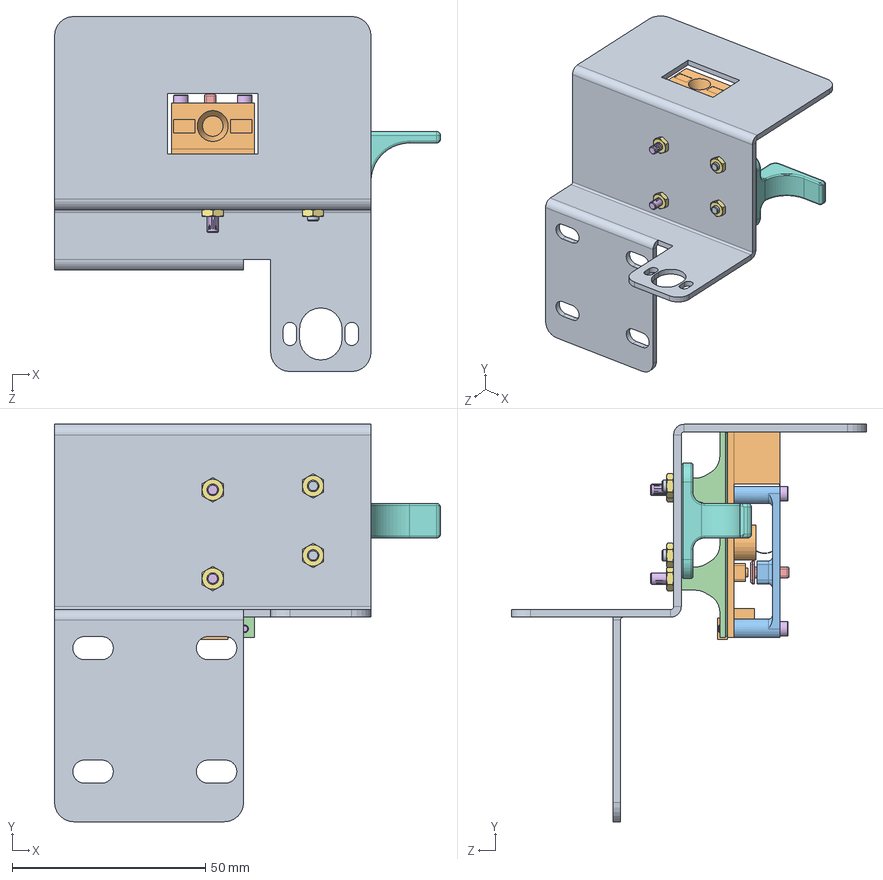
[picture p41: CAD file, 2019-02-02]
CAD Files/CAD LMI/T00006-000-R00.SLDASM
100.0 x 103.0 x 92.0 mm
T00126-000-R02
T00154-E00-R01
T00172-000-R01
T00171-000-R01
T00173-000-R01
socket head cap screw_iso x 5
hex thin nut chamfered gradeab_iso x 4
T00163-03D-R01
socket countersunk head screw_iso x 2

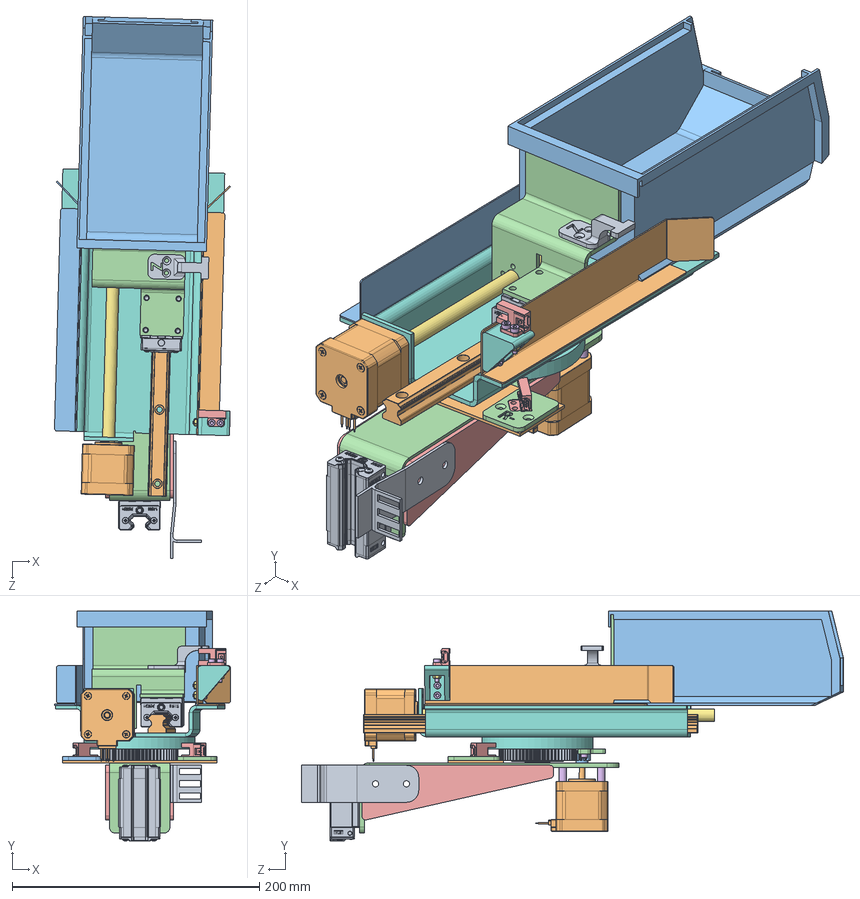
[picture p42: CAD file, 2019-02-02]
CAD Files/CAD LMI/T00003-000-R00.SLDASM
142.3 x 185.9 x 438.3 mm
T00108-E00-R00 x 2
T00110-E00-R00
T00148-E00-R00
T00126-000-R00
T00127-E00-R00
T00128-0A4-R00
T00129-E00-R00
T00130-0A4-R01
T00132-E00-R00
T00107-E00-R00 x 2
T00131-E00-R00
T00133-0A4-R00
T00134-DXF-R00 x 2
T00105-E00-R00 x 4
T00111-E00-R00
T00135-DXF-R01
T00136-DXF-R01
T00137-000-R00
T00138-000-R00
T00162-03D-R00
T00153-E00-R00 x 3
socket head cap screw_iso x 7
hex nut style 1 gradeab_iso x 4
T00168-03D-R00
T00163-03D-R00
T00161-0A4-R00
T00164-03D-R00
T00165-03D-R00

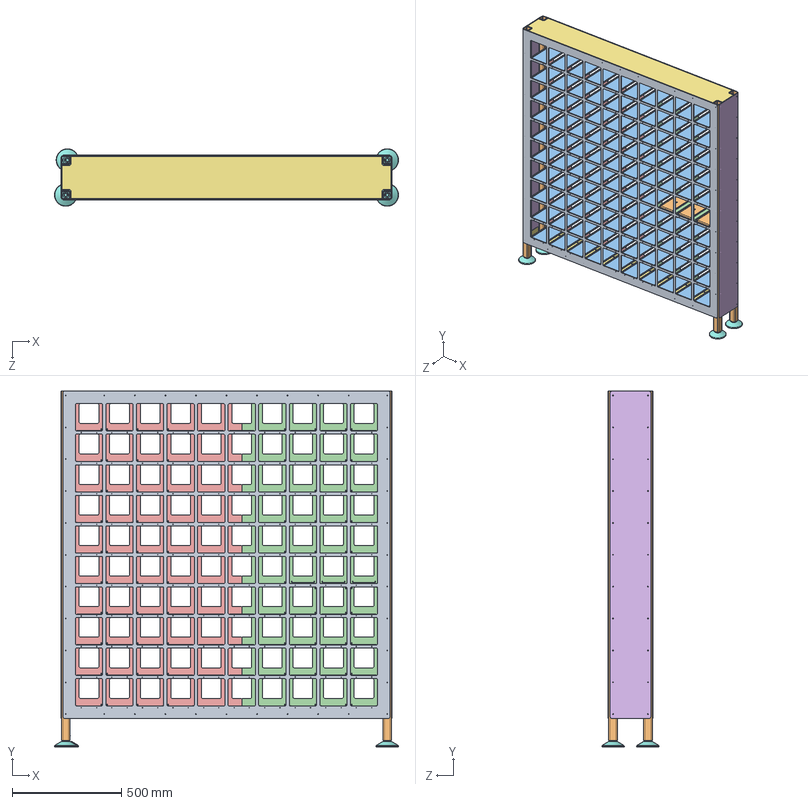
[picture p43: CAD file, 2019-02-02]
CAD Files/CAD LMI/T00002-000-R00.SLDASM
1575.8 x 1630.0 x 263.0 mm
T00114-DXF-R00
T00113-000-R00 x 4
T00116-0A4-R00 x 97
T00158-DXF-R00
T00159-DXF-R00
T00139-DXF-R00 x 2
T00140-0A4-R00 x 2
T00141-E00-R00 x 4
T00157-E00-R00 x 3
T00156-000-R00 x 3
flat washer narrow_am x 24
T00155-0A3-R00 x 3

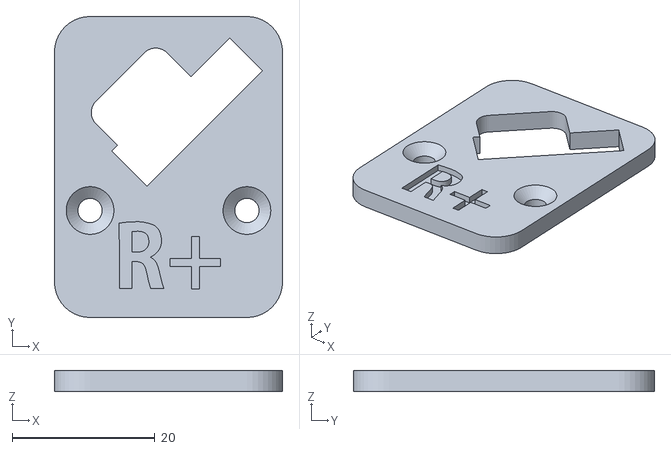
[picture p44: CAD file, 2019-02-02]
CAD Files/CAD LMI/3D machining files/Nu printen/T00164-03D-R00.STL
32.0 x 42.2 x 3.00

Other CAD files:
CAD Files/CAD LMI/Part4.sldprt
CAD Files/CAD LMI/Part6.sldprt
CAD Files/CAD LMI/3D machining files/T00151-03D-R01.STL
CAD Files/CAD LMI/DXF/T00140-0A4-R00-1v1.DXF
CAD Files/CAD LMI/3D machining files/Nu printen/T00162-03D-R00.STL
CAD Files/CAD LMI/3D machining files/Nu printen/T00165-03D-R00.STL
CAD Files/CAD LMI/3D machining files/T00150-03D-R00.STL
CAD Files/CAD LMI/3D machining files/T00151-03D-R00.STL
CAD Files/CAD LMI/3D machining files/T00152-03D-R00.STL
CAD Files/CAD LMI/3D machining files/T00152-03D-R01.STL
CAD Files/CAD LMI/3D machining files/T00162-03D-R02.STL
CAD Files/CAD LMI/3D machining files/T00163-03D-R00.STL
CAD Files/CAD LMI/3D machining files/T00168-03D-R00.STL
CAD Files/CAD LMI/3D machining files/T00170-03D-R00.STL
CAD Files/CAD LMI/Archief/T00005-0A3-R00.SLDDRW
CAD Files/CAD LMI/Archief/T00161-000-R00.SLDPRT
CAD Files/CAD LMI/Archief/T00161-03D-R00.SLDPRT
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

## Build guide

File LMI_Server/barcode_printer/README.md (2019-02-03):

# Barcode printer

This script prints a 2D barcode (DataMatrix) with the written ID for the containers. This works with a couple of label printers from the Brother QL series.
It uses the Linux kernel to talk to the label printer, so this won't work on Windows.

### Dependencies
- brother_ql
- elaphe3
- PIL

`pip3 install brother_ql elaphe3 pillow`

You have to add yourself to the `lp` group to be able to talk to the label printer.  
`sudo usermod -a -G lp USER_NAME`

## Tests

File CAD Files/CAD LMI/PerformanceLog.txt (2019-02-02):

Mesh Preparation:  0 hr 0 min 0 sec
Creating midsurfaces by SW:  0 hr 0 min 0 sec
Standard midsurf mesh midsurf map creation:  0 hr 0 min 0 sec
Standard midsurf mesh joint and bolt head imprint:  0 hr 0 min 0 sec
Standard midsurf mesh total preparation excluding midsurf creation:  0 hr 0 min 0 sec
Standard midsurf mesh surface mesh:  0 hr 0 min 1 sec
Standard midsurf mesh arranging data:  0 hr 0 min 0 sec
Standard midsurf mesh total:  0 hr 0 min 1 sec
Beam mesh:  0 hr 0 min 0 sec
Preparing to transfer data:  0 hr 0 min 0 sec
Processing material properties:  0 hr 0 min 0 sec
Processing element groups:  0 hr 0 min 0 sec
Processing drop test gap nodes:  0 hr 0 min 0 sec
Updating thickness for shell regions:  0 hr 0 min 0 sec
Processing rconst for elements:  0 hr 0 min 0 sec
Processing egroups:  0 hr 0 min 0 sec
Transferring loads and boundary conditions:  0 hr 0 min 0 sec
Generating body pairs to check contact:  0 hr 0 min 0 sec
Generating contacts:  0 hr 0 min 0 sec
Number of Contacts: 0
Transfer SL1 data:  0 hr 0 min 0 sec
Generate more accurate contact data:  0 hr 0 min 0 sec
Number of contact data: 0
Transfer beam/joint contact data:  0 hr 0 min 0 sec
Transferring other special loads:  0 hr 0 min 0 sec
Transferring bearing loads:  0 hr 0 min 0 sec
Transferring mass elements:  0 hr 0 min 0 sec
Transferring point loads:  0 hr 0 min 0 sec
Transferring distributed beam loads:  0 hr 0 min 0 sec
Transferring rigid bodies:  0 hr 0 min 0 sec
Transferring component no penetration:  0 hr 0 min 0 sec
Writing Data:  0 hr 0 min 0 sec
Transferring analysis options:  0 hr 0 min 0 sec
Total midsurf mapping:  0 hr 0 min 0 sec

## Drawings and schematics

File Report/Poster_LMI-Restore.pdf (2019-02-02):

# LMI Re-store

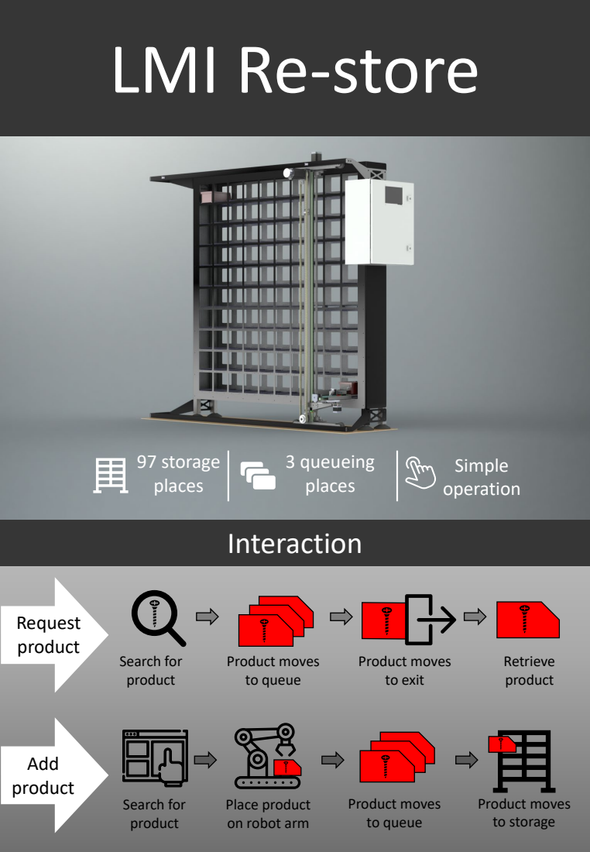
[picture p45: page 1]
Simple operation; 3 queueing places; 97 storage places; Interaction; Search for product; Product moves to queue; Product moves to exit; Retrieve product; Request product; Add product; Product moves to storage

Place product
on robot arm

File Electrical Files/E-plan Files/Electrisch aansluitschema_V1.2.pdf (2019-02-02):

+49 (0)2173 - 39 64 - 0

40789

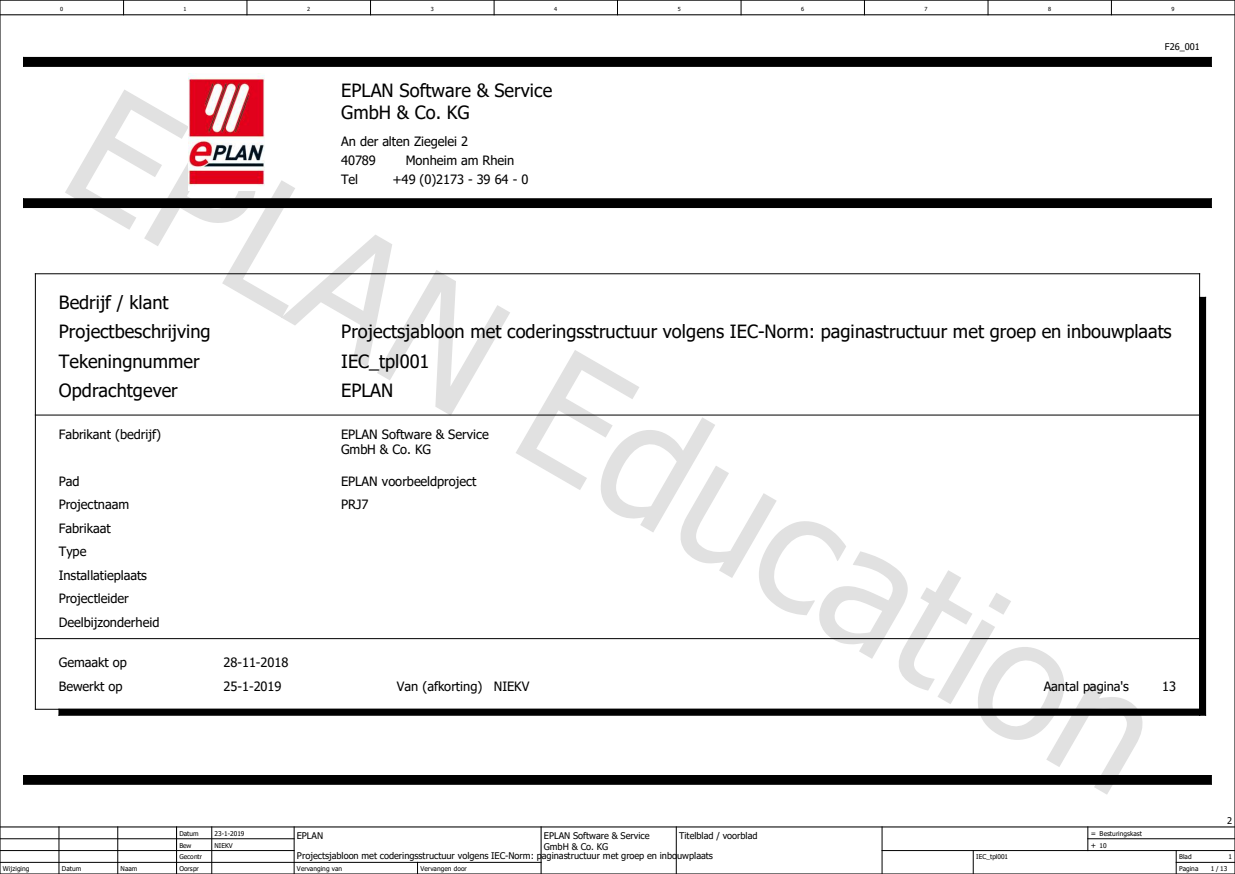
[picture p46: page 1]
Projectbeschrijving; Projectsjabloon met coderingsstructuur volgens IEC-Norm: paginastructuur met groep en inbouwplaats; Aantal pagina's; Opdrachtgever; Bewerkt op; IEC_tpl001; Gemaakt op; Tekeningnummer; EPLAN voorbeeldproject; Fabrikaat; NIEKV; Deelbijzonderheid; Pad; Fabrikant (bedrijf); Projectnaam; PRJ7; Projectleider; Tel; Type; Bedrijf / klant; Installatieplaats; Van (afkorting); EPLAN

EPLAN Software & Service
GmbH & Co. KG

An der alten Ziegelei 2

Monheim am Rhein

23-1-2019 | EPLAN Projectsjabloon met coderingsstructuur volgens IEC-Norm: paginastructuur met groep en inbouwplaats | EPLAN Software & Service GmbH & Co. KG | Titelblad / voorblad | = Besturingskast

Bew | NIEKV | | | | + 10
Gecontr | | | | | IEC_tpl001 | Blad

Wijziging | Datum | Naam | Oorspr | | Vervanging van | Vervangen door | | | | Pagina 1 / 13

# Inhoudsopgave

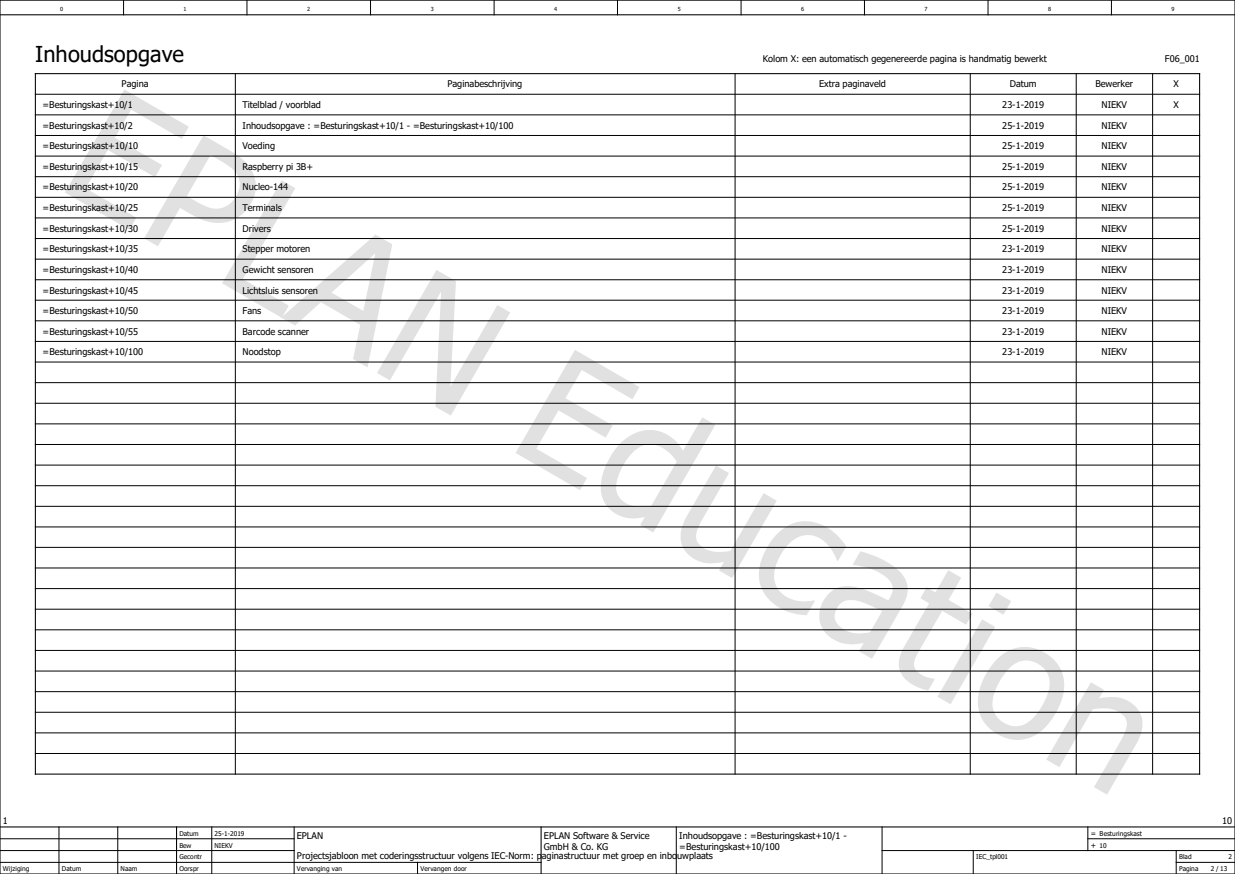
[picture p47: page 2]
Inhoudsopgave : =Besturingskast+10/1 - =Besturingskast+10/100; EPLAN Software & Service

Kolom X: een automatisch gegenereerde pagina is handmatig bewerkt

Pagina | Paginabeschrijving | Extra paginaveld | Datum | Bewerker | X

=Besturingskast+10/1 | | | 23-1-2019 | NIEKV Titelblad / voorblad | X
=Besturingskast+10/2 | | | 25-1-2019 | NIEKV Inhoudsopgave : =Besturingskast+10/1 - =Besturingskast+10/100
=Besturingskast+10/10 | Voeding | | 25-1-2019 | NIEKV
=Besturingskast+10/15 | Raspberry pi 3B+ | | 25-1-2019 | NIEKV
=Besturingskast+10/20 | Nucleo-144 | | 25-1-2019 | NIEKV
=Besturingskast+10/25 | Terminals | | 25-1-2019 | NIEKV
=Besturingskast+10/30 | Drivers | | 25-1-2019 | NIEKV
=Besturingskast+10/35 | Stepper motoren | | 23-1-2019 | NIEKV
=Besturingskast+10/40 | Gewicht sensoren | | 23-1-2019 | NIEKV
=Besturingskast+10/45 | Lichtsluis sensoren | | 23-1-2019 | NIEKV
=Besturingskast+10/50 | Fans | | 23-1-2019 | NIEKV
=Besturingskast+10/55 | Barcode scanner | | 23-1-2019 | NIEKV
=Besturingskast+10/100 | Noodstop | | 23-1-2019 | NIEKV

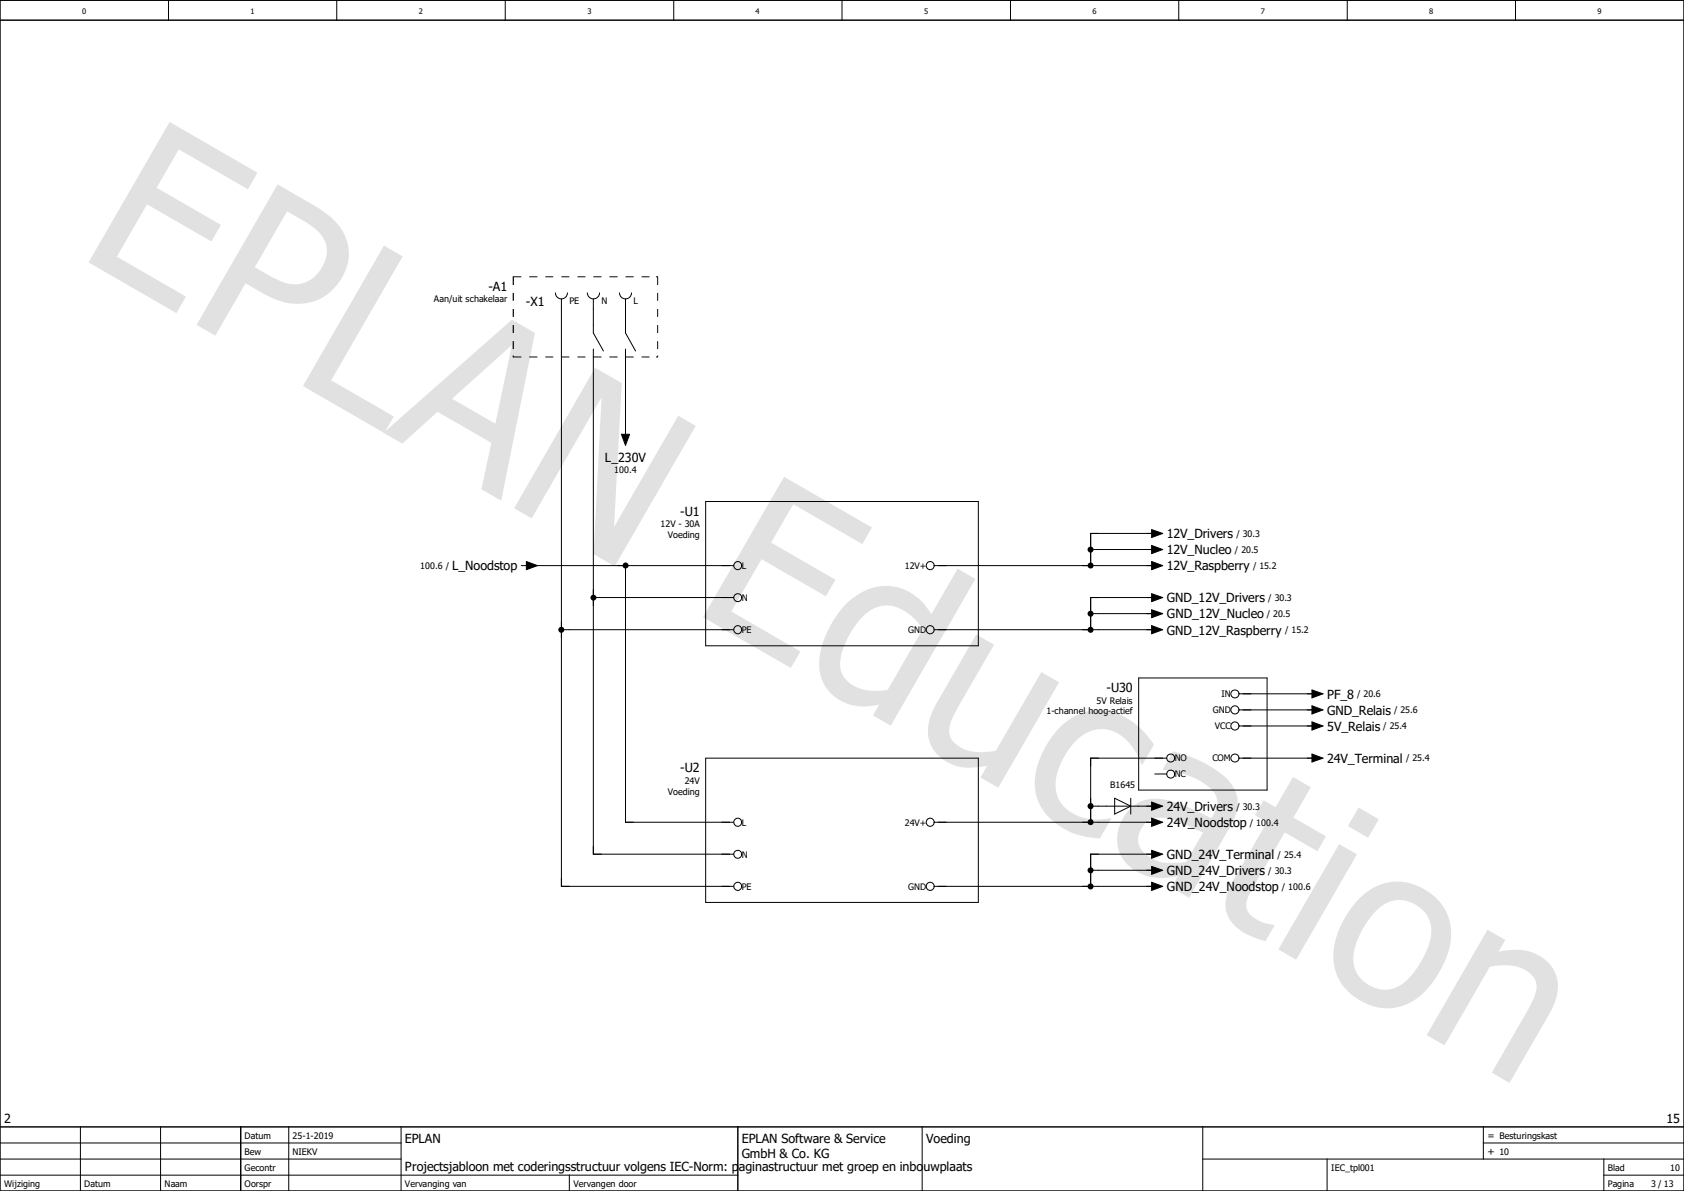
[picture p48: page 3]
Voeding; -U2 24V Voeding; GND; -U1 12V - 30A Voeding; -U30 5V Relais; COM; VCC; 12V_Drivers / 30.3; GND_12V_Drivers / 30.3; 24V_Terminal / 25.4; GND_24V_Drivers / 30.3; 24V_Noodstop / 100.4; GND_24V_Noodstop / 100.6; 12V_Nucleo / 20.5; GND_12V_Nucleo / 20.5; 100.6 / L_Noodstop; GND_24V_Terminal / 25.4; 24V_Drivers / 30.3; 12V_Raspberry / 15.2; GND_12V_Raspberry / 15.2; PF_8 / 20.6 GND_Relais / 25.6 5V_Relais / 25.4

Aan/uit schakelaar

1-channel hoog-actief

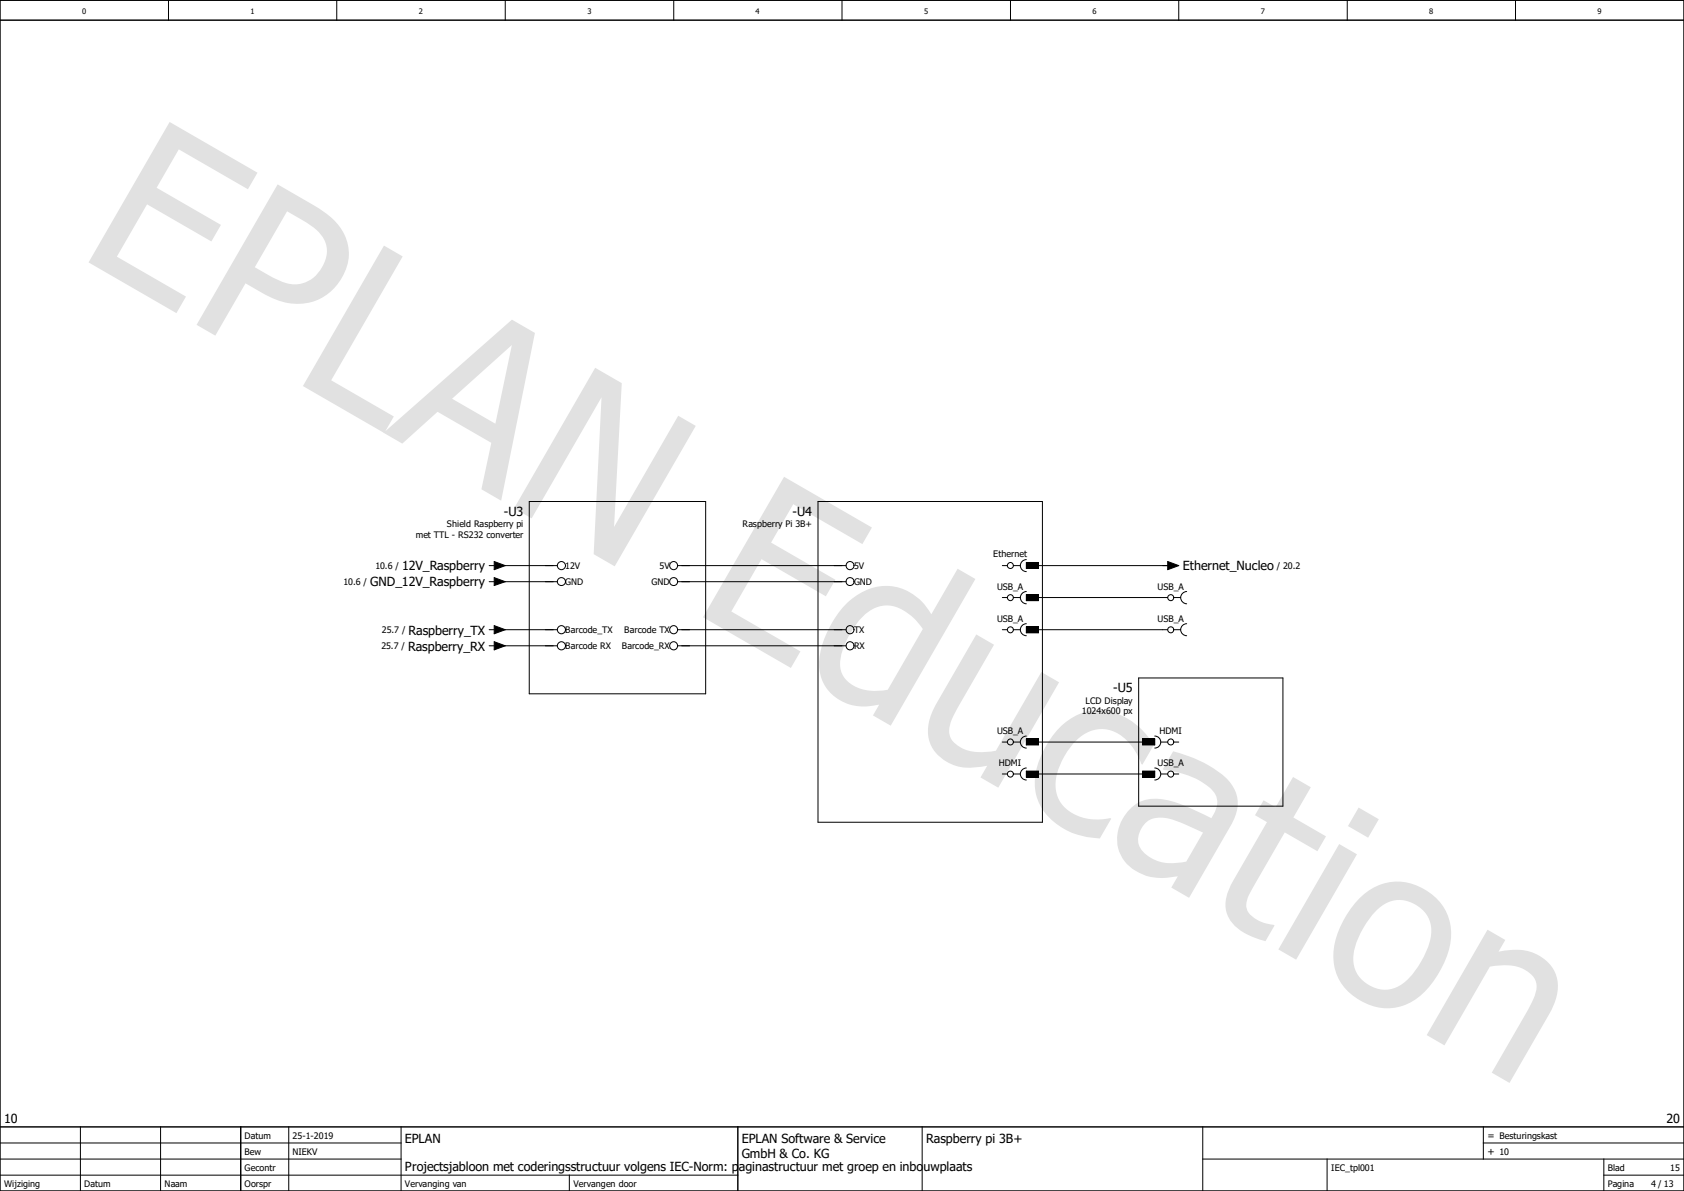
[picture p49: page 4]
Raspberry pi 3B+; -U4 Raspberry Pi 3B+; Ethernet; GND; Barcode RX; Barcode_TX Barcode TX Barcode_RX; USB_A; HDMI; -U5 LCD Display 1024x600 px; 10.6 / 12V_Raspberry; Ethernet_Nucleo / 20.2; 10.6 / GND_12V_Raspberry; 25.7 / Raspberry_TX 25.7 / Raspberry_RX

Shield Raspberry pi
met TTL - RS232 converter

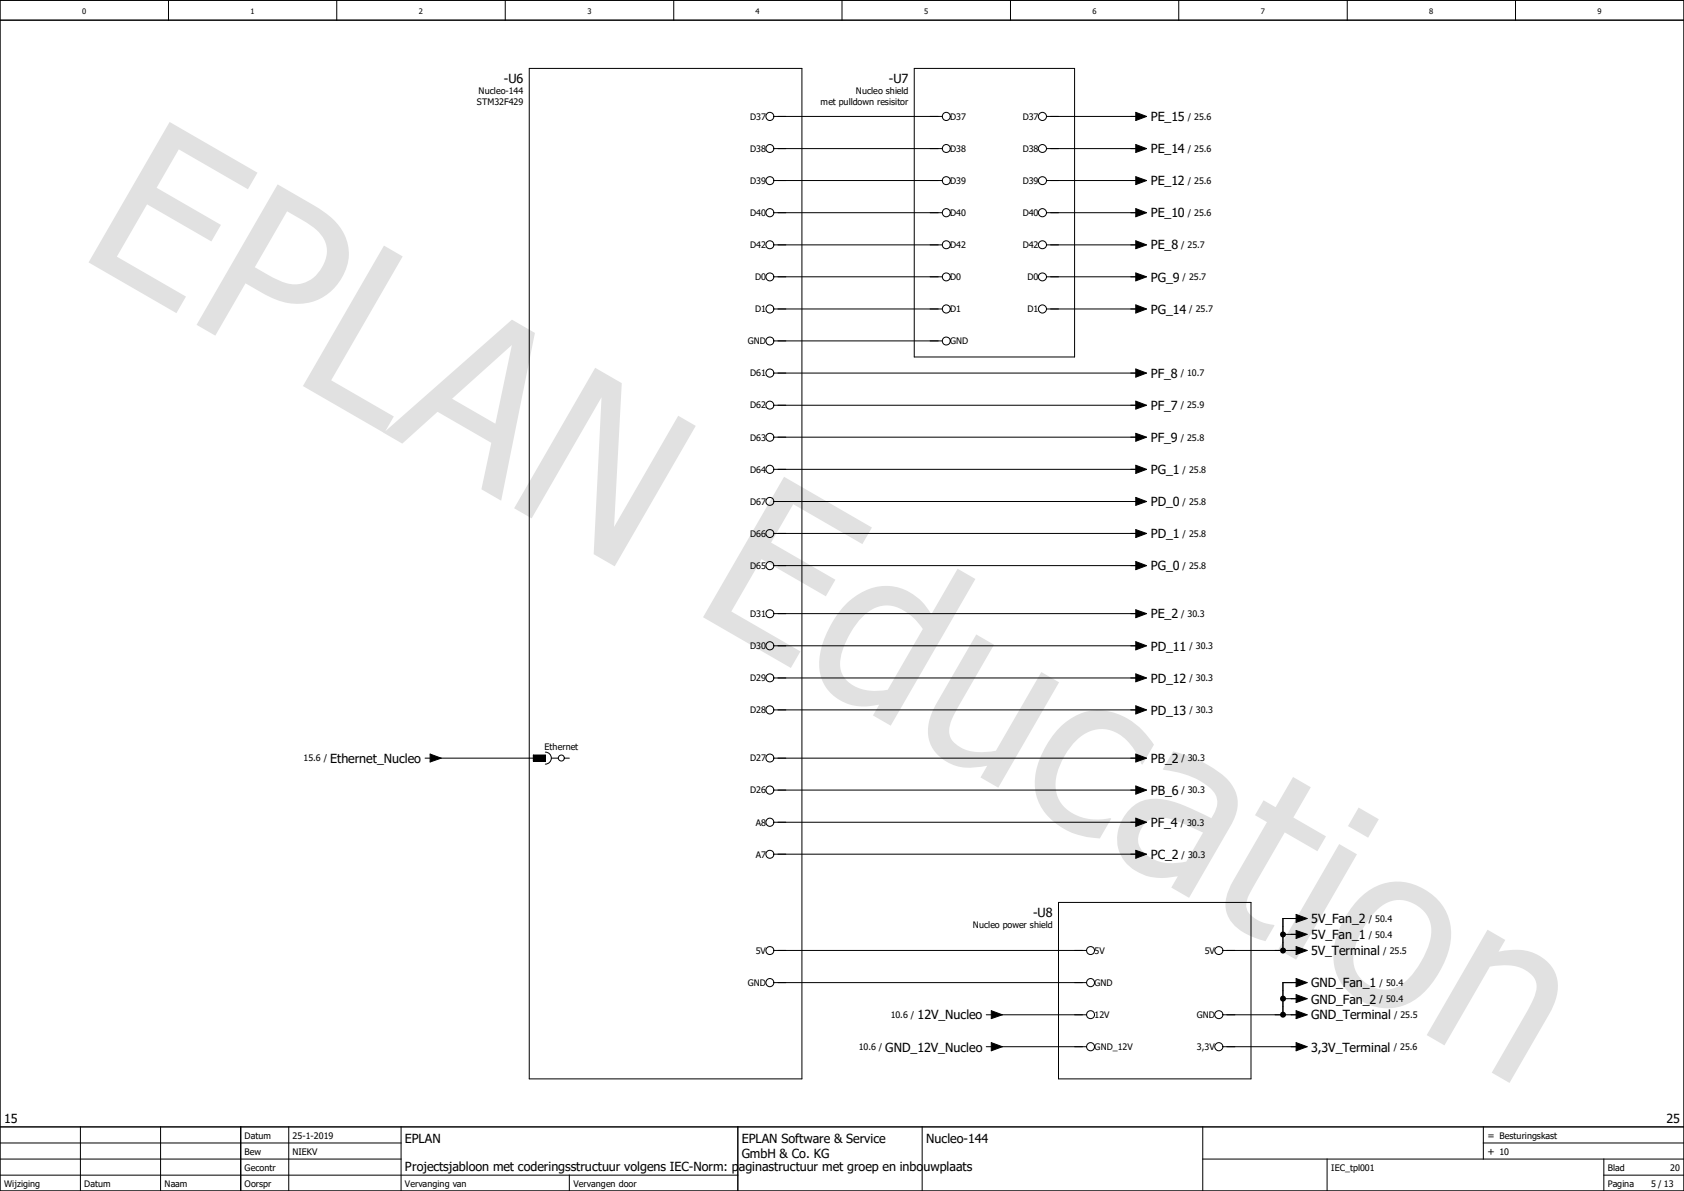
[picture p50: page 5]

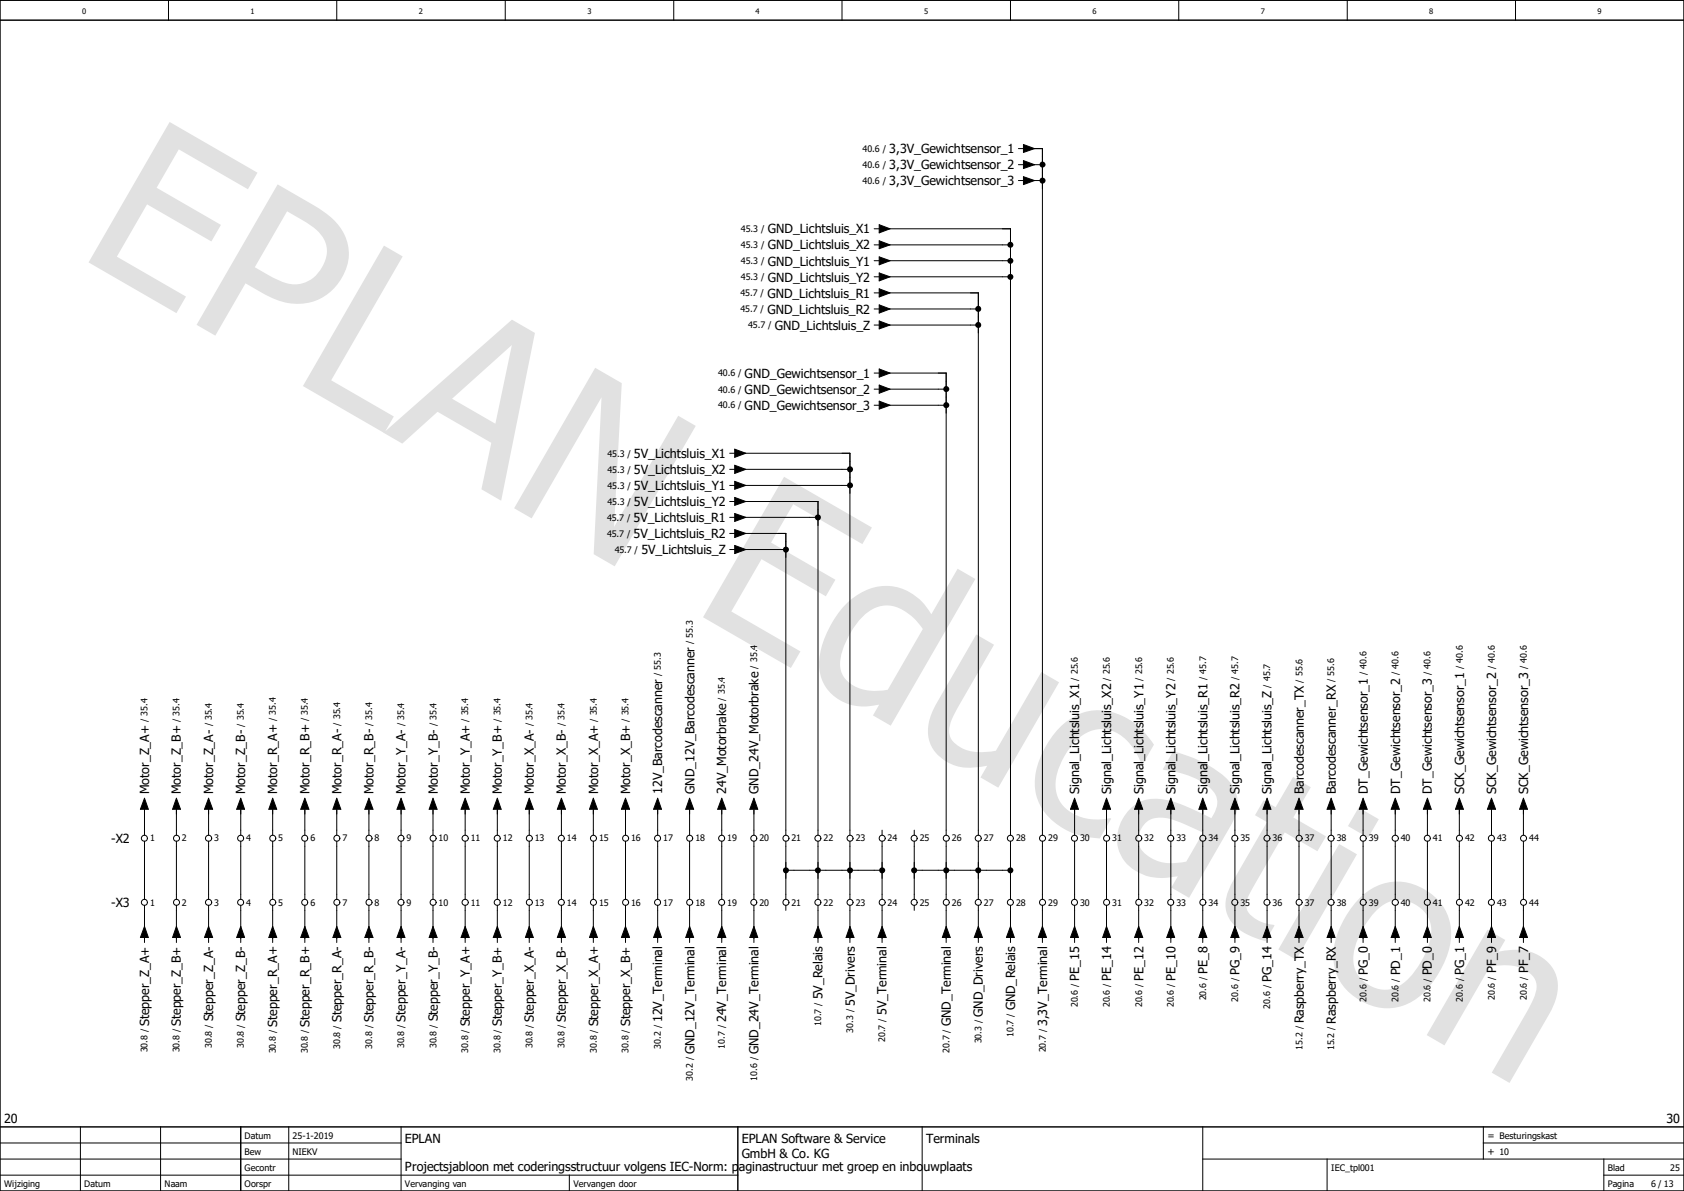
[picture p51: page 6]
Terminals; 44 Stepper_Z_A+ / 30.8; Stepper_Z_B+ / 30.8; Stepper_Z_A⁻ / 30.8; Stepper_Z_B⁻ / 30.8; Stepper_R_A+ / 30.8; Stepper_R_B+ / 30.8; Stepper_R_A⁻ / 30.8; Stepper_R_B⁻ / 30.8; Stepper_Y_A⁻ / 30.8; Stepper_Y_B⁻ / 30.8; Stepper_Y_A+ / 30.8; Stepper_Y_B+ / 30.8; Stepper_X_A⁻ / 30.8; Stepper_X_B⁻ / 30.8; Stepper_X_A+ / 30.8; Stepper_X_B+ / 30.8 Motor_Z_A+ / 35.4; Motor_Z_B+ / 35.4; Motor_Z_A⁻ / 35.4; Motor_Z_B⁻ / 35.4; Motor_R_A+ / 35.4; Motor_R_B+ / 35.4; Motor_R_A⁻ / 35.4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

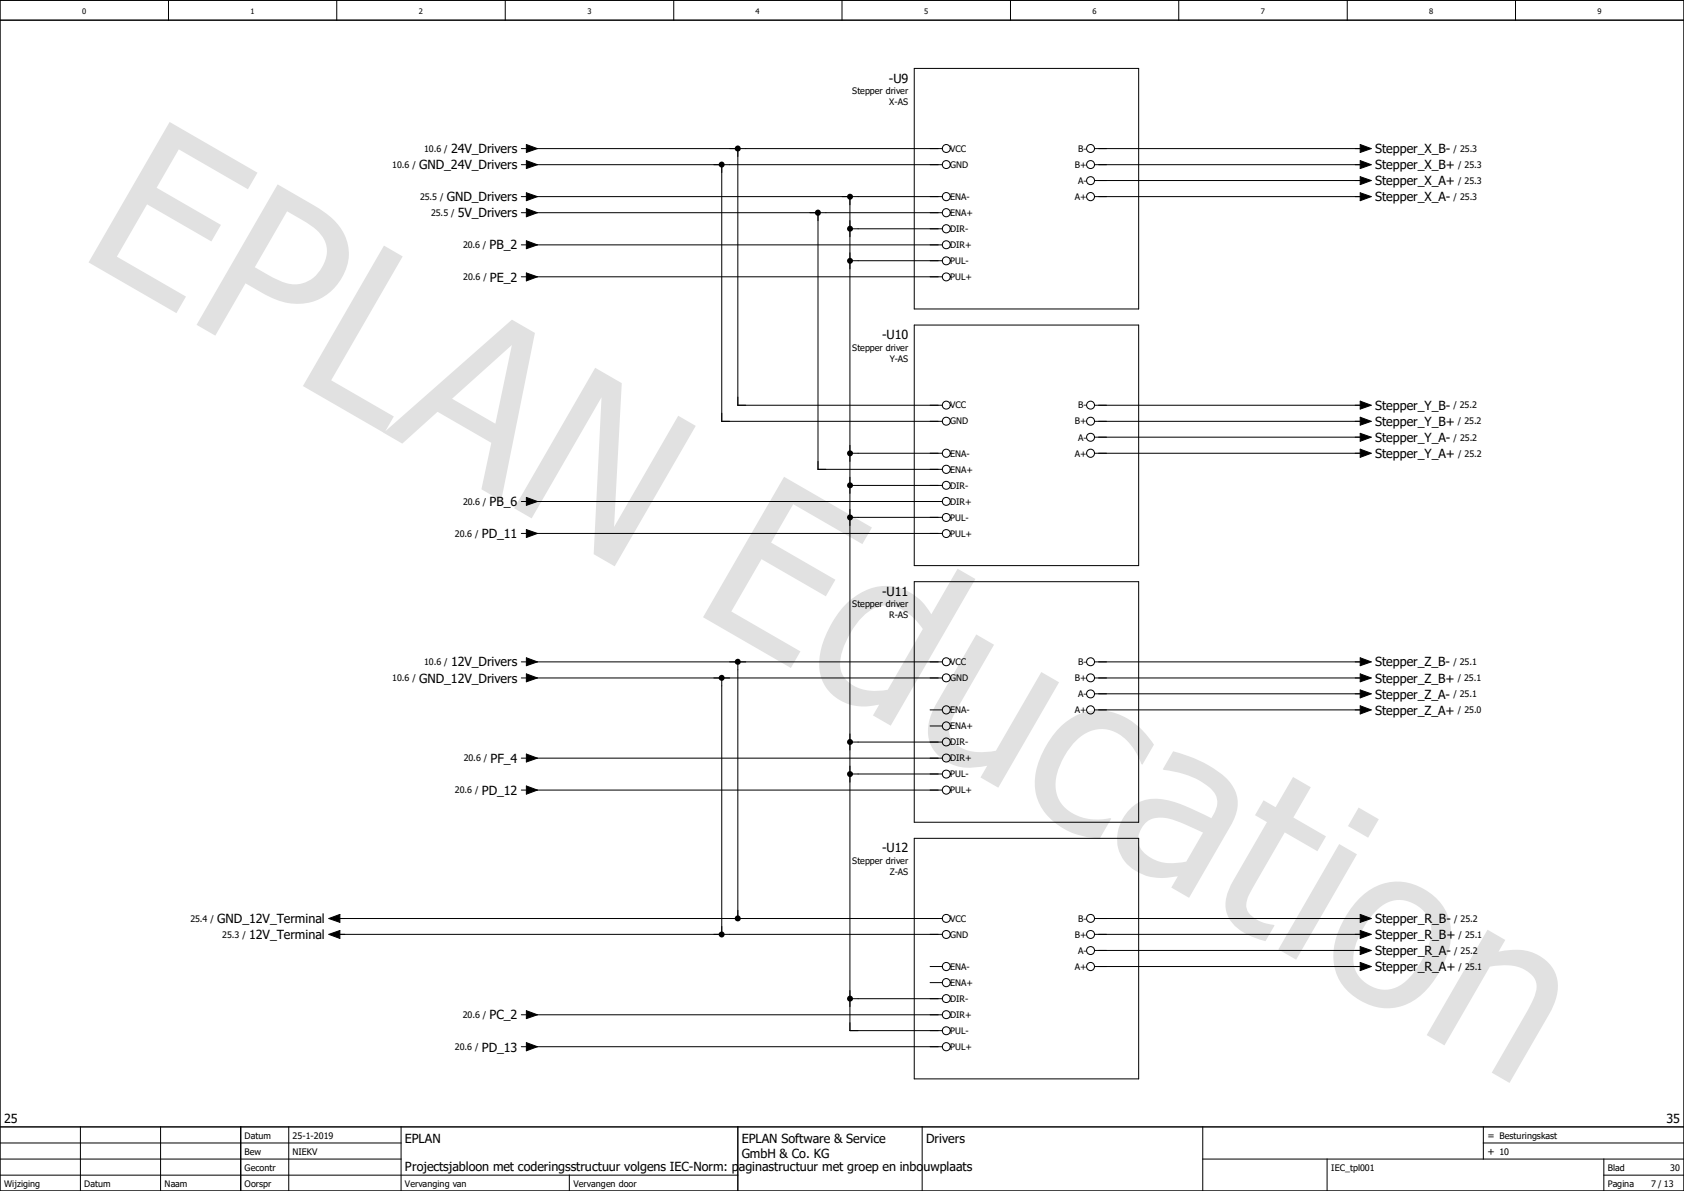
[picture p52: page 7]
Drivers; GND; -U12 Stepper driver Z-AS; VCC; ENA+; ENA-; DIR+; DIR-; PUL+; PUL-; -U11 Stepper driver R-AS; -U10 Stepper driver Y-AS; -U9 Stepper driver X-AS; 25.5 / GND_Drivers; 25.5 / 5V_Drivers; Stepper_Z_B- / 25.1 Stepper_Z_B+ / 25.1 Stepper_Z_A- / 25.1 Stepper_Z_A+ / 25.0; Stepper_R_B- / 25.2 Stepper_R_B+ / 25.1 Stepper_R_A- / 25.2 Stepper_R_A+ / 25.1; Stepper_Y_B- / 25.2 Stepper_Y_B+ / 25.2 Stepper_Y_A- / 25.2 Stepper_Y_A+ / 25.2; Stepper_X_A- / 25.3; Stepper_X_A+ / 25.3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

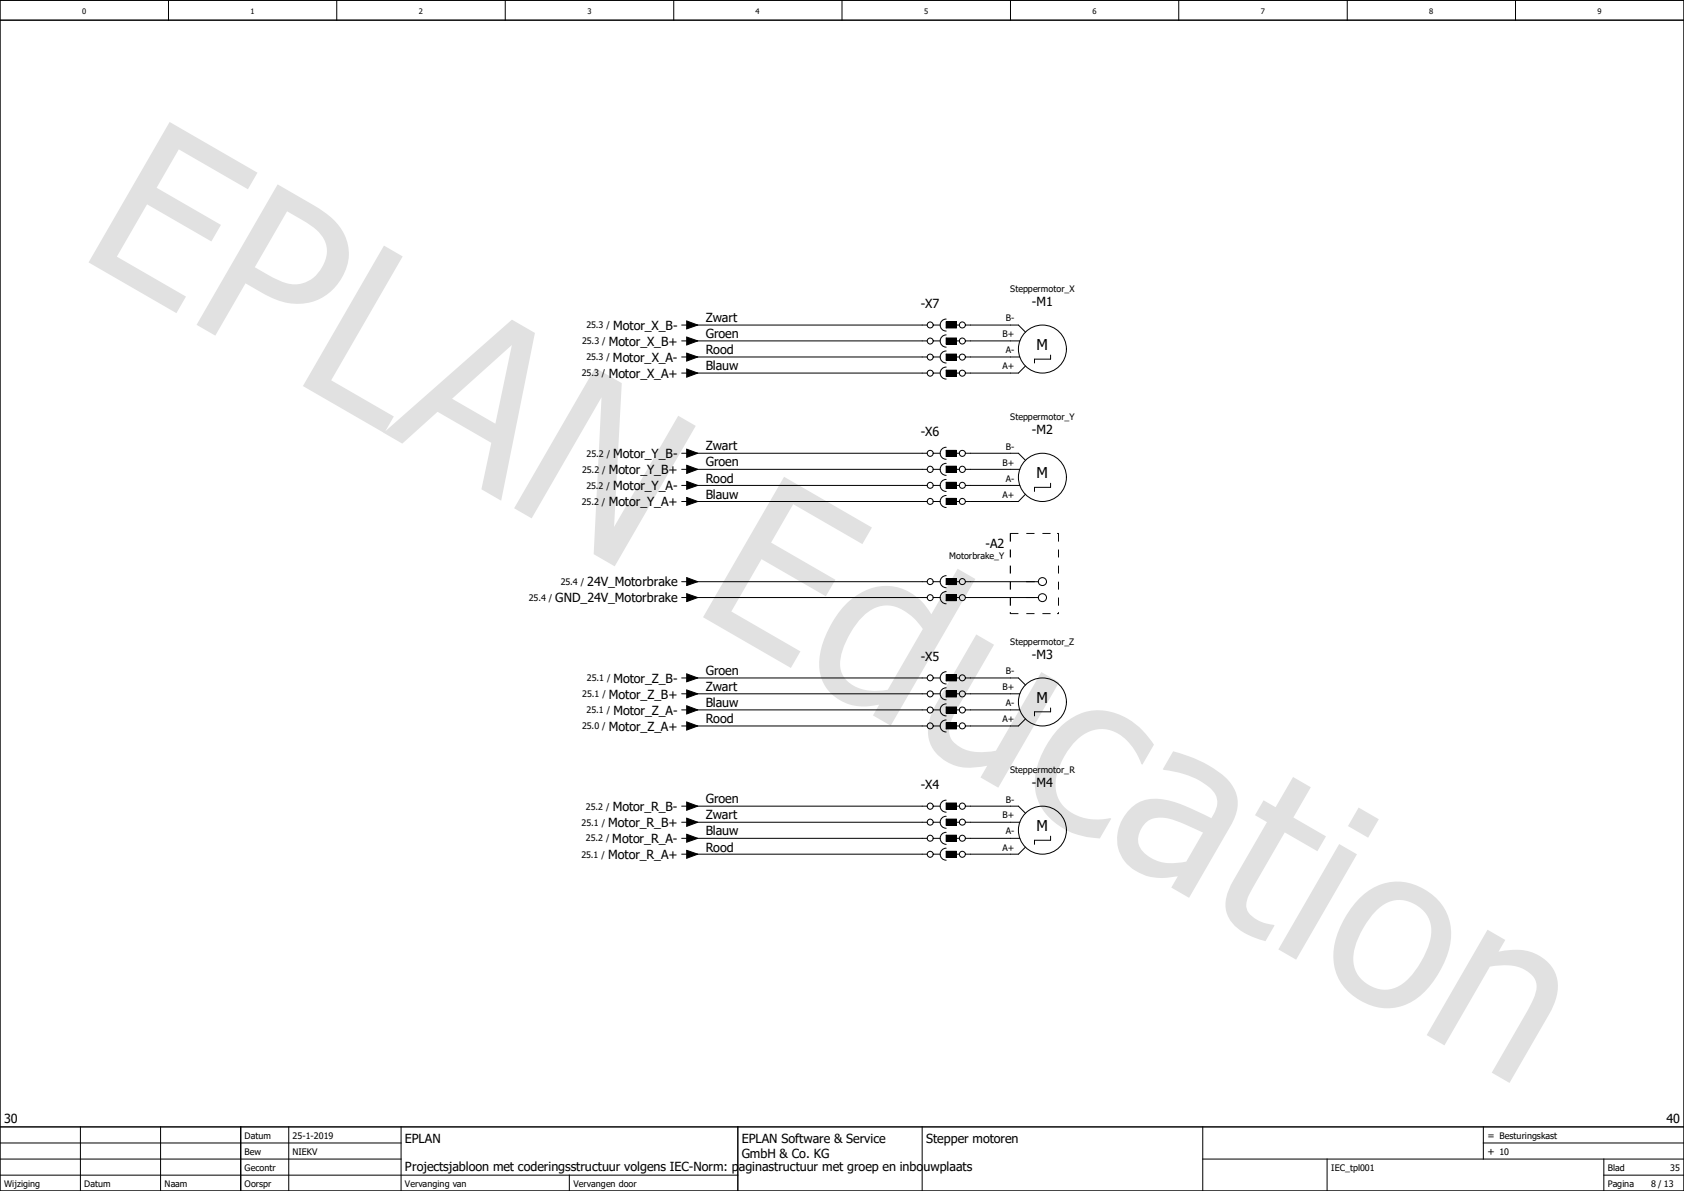
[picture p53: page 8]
Stepper motoren; Zwart; Zwart Groen; Groen; Blauw; Rood; Steppermotor_X M; Steppermotor_Y M; Steppermotor_Z M; Steppermotor_R M; -A2 Motorbrake_Y; 25.2 / Motor_Y_A+; 25.2 / Motor_Y_A-; 25.2 / Motor_Y_B+; 25.2 / Motor_Y_B-; 25.0 / Motor_Z_A+; 25.1 / Motor_Z_A-; 25.1 / Motor_Z_B+; 25.1 / Motor_Z_B-; 25.1 / Motor_R_A+; 25.2 / Motor_R_A-; 25.1 / Motor_R_B+; 25.2 / Motor_R_B-; 25.3 / Motor_X_B- 25.3 / Motor_X_B+ 25.3 / Motor_X_A- 25.3 / Motor_X_A+; 25.4 / GND_24V_Motorbrake; 25.4 / 24V_Motorbrake
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

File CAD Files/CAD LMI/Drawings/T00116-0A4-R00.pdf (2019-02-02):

E E

F F

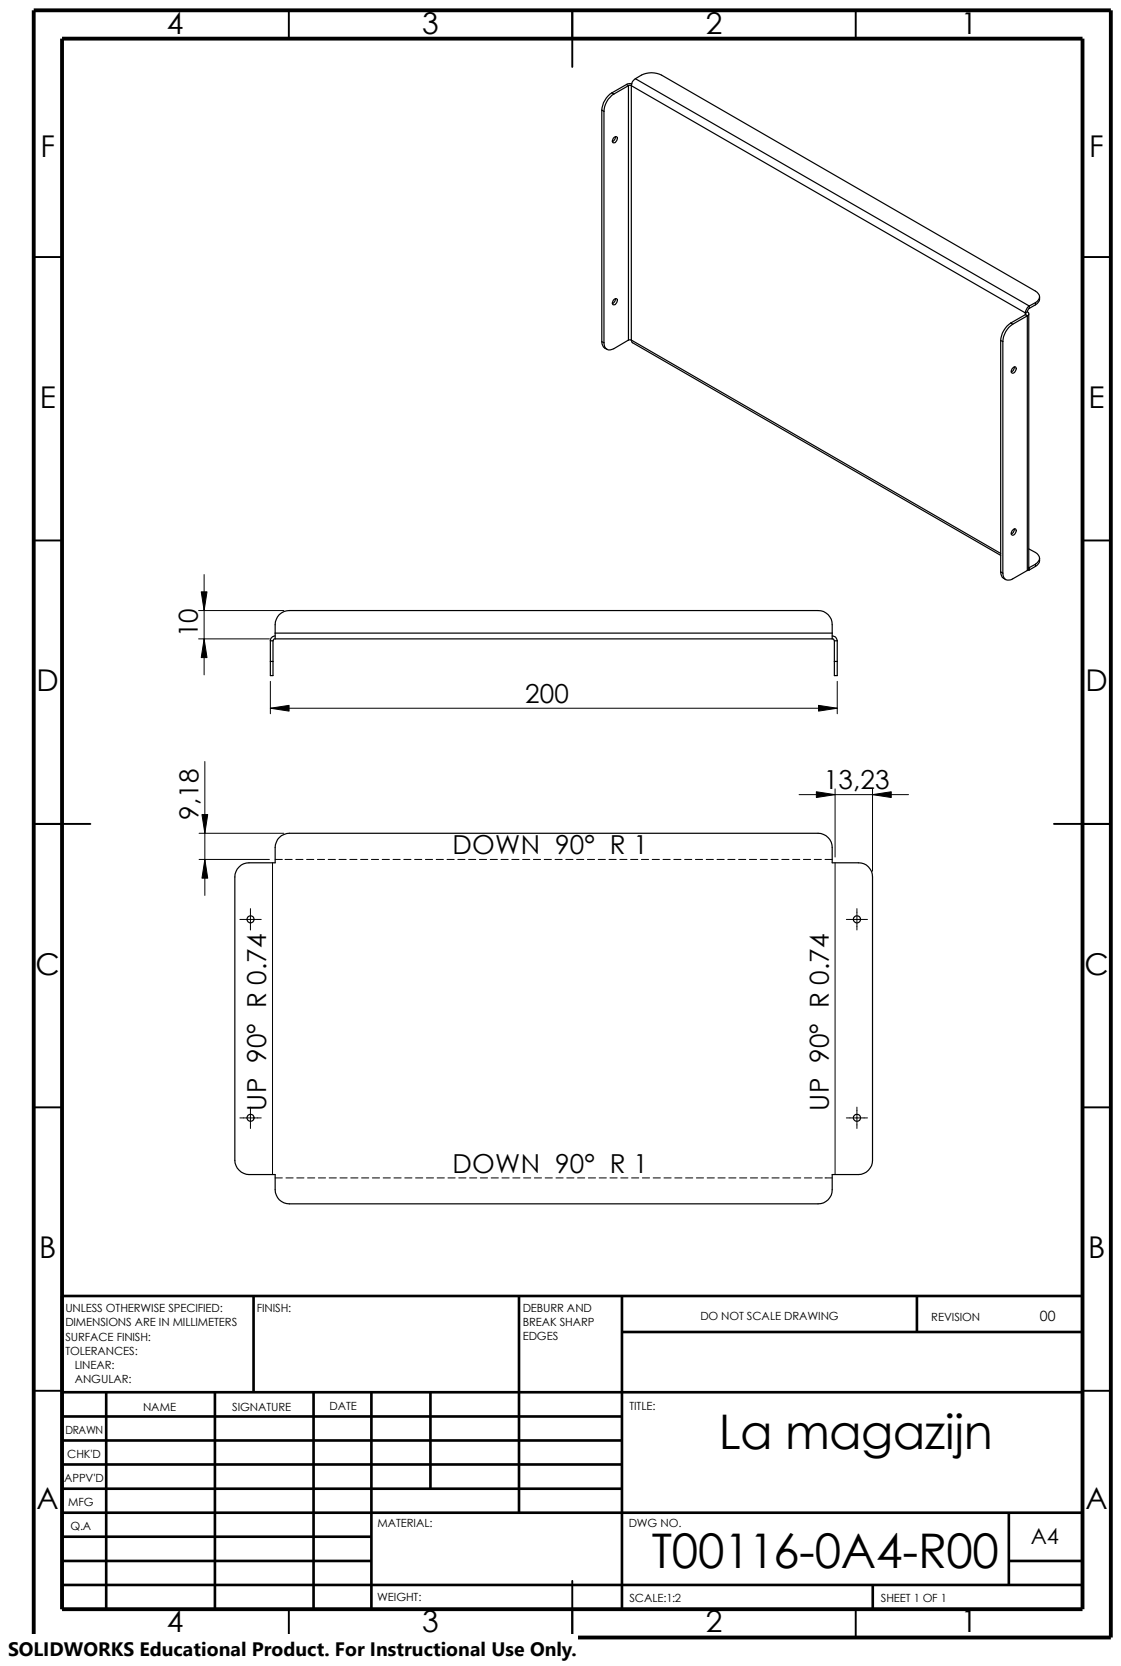
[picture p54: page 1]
REVISION; DWG NO.; SCALE:1:2; SHEET 1 OF 1; WEIGHT:; MATERIAL:; MFG; FINISH:; EDGES; DEBURR AND; BREAK SHARP; DOWN 90° R 1

UNLESS OTHERWISE SPECIFIED:
DIMENSIONS ARE IN MILLIMETERS
SURFACE FINISH:
TOLERANCES:
LINEAR:
ANGULAR:

DO NOT SCALE DRAWING

NAME | SIGNATURE | DATE | TITLE: La magazijn

DRAWN

CHK'D

APPV'D

SOLIDWORKS Educational Product. For Instructional Use Only.

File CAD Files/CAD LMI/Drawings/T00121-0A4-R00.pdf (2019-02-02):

E E

F F

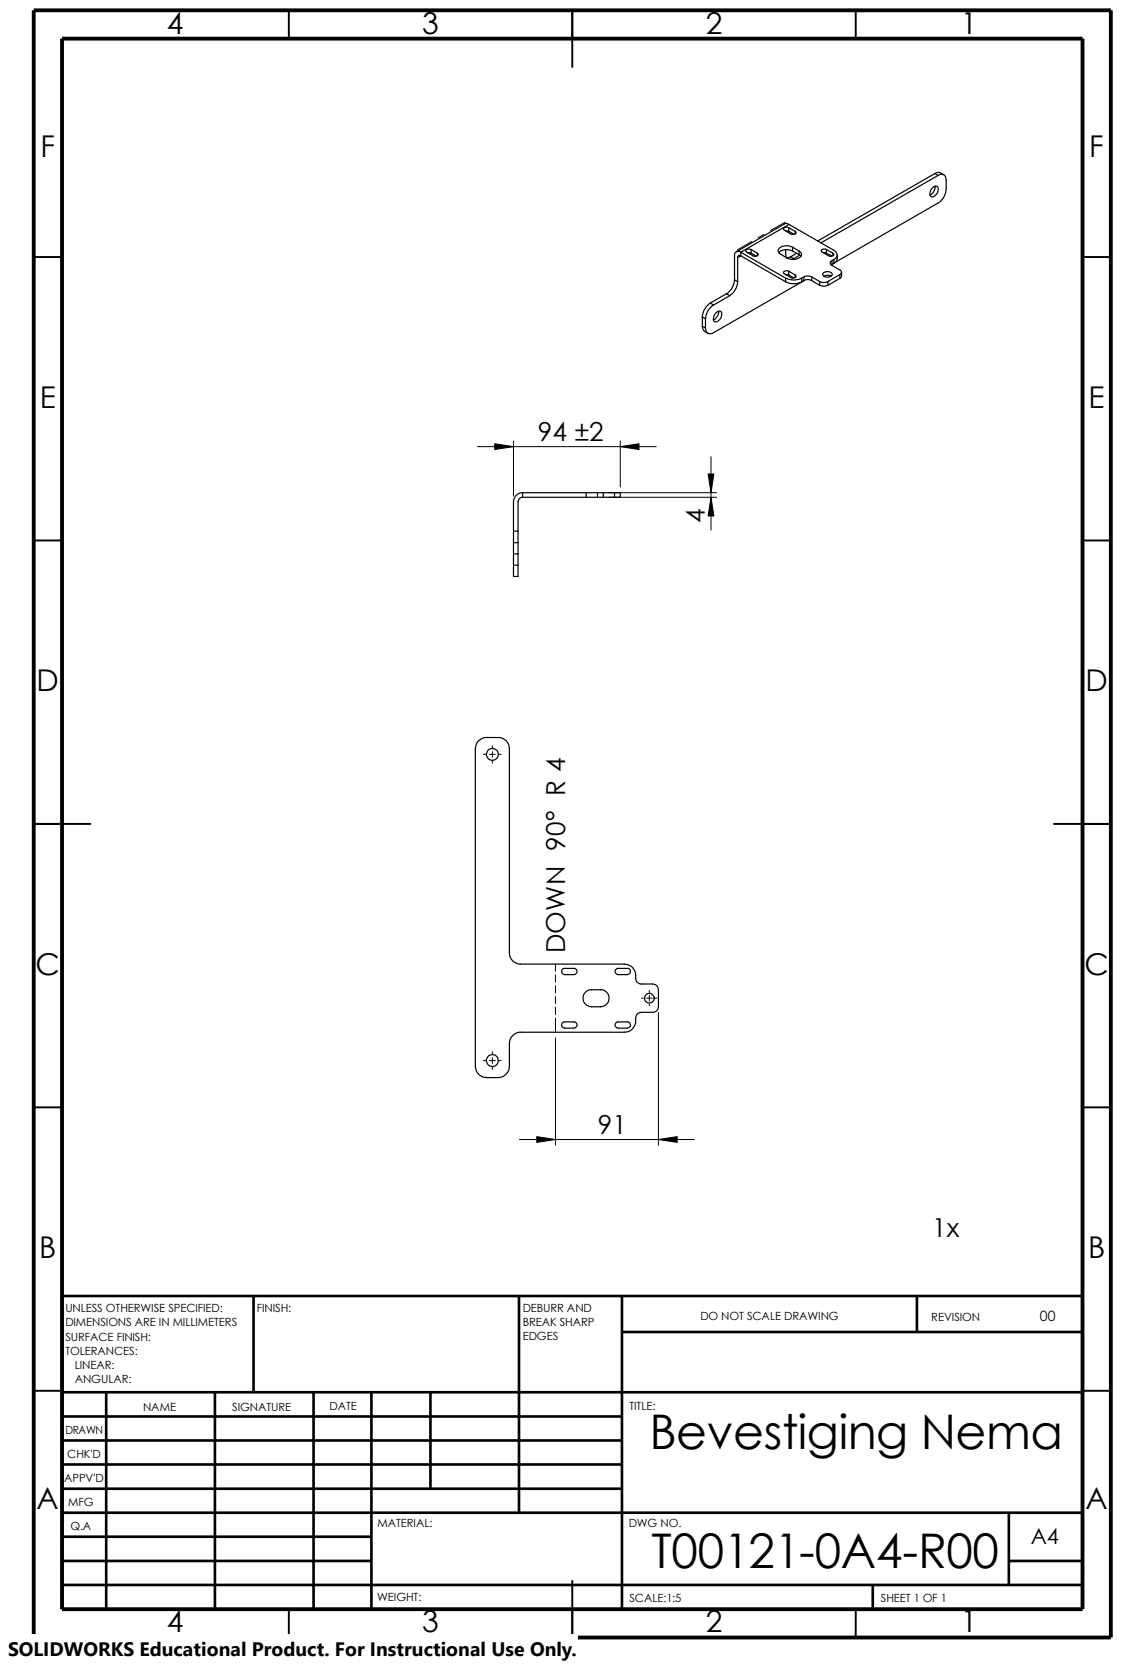
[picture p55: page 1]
SHEET 1 OF 1; DWG NO.; REVISION; SCALE:1:5; MFG; FINISH:; EDGES; MATERIAL:; WEIGHT:; DEBURR AND; BREAK SHARP; DOWN 90° R 4

UNLESS OTHERWISE SPECIFIED:
DIMENSIONS ARE IN MILLIMETERS
SURFACE FINISH:
TOLERANCES:
LINEAR:
ANGULAR:

DO NOT SCALE DRAWING

NAME | SIGNATURE | DATE | TITLE: Bevestiging Nema

DRAWN

CHK'D

APPV'D

SOLIDWORKS Educational Product. For Instructional Use Only.

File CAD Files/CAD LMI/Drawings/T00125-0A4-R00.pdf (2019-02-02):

12
E E

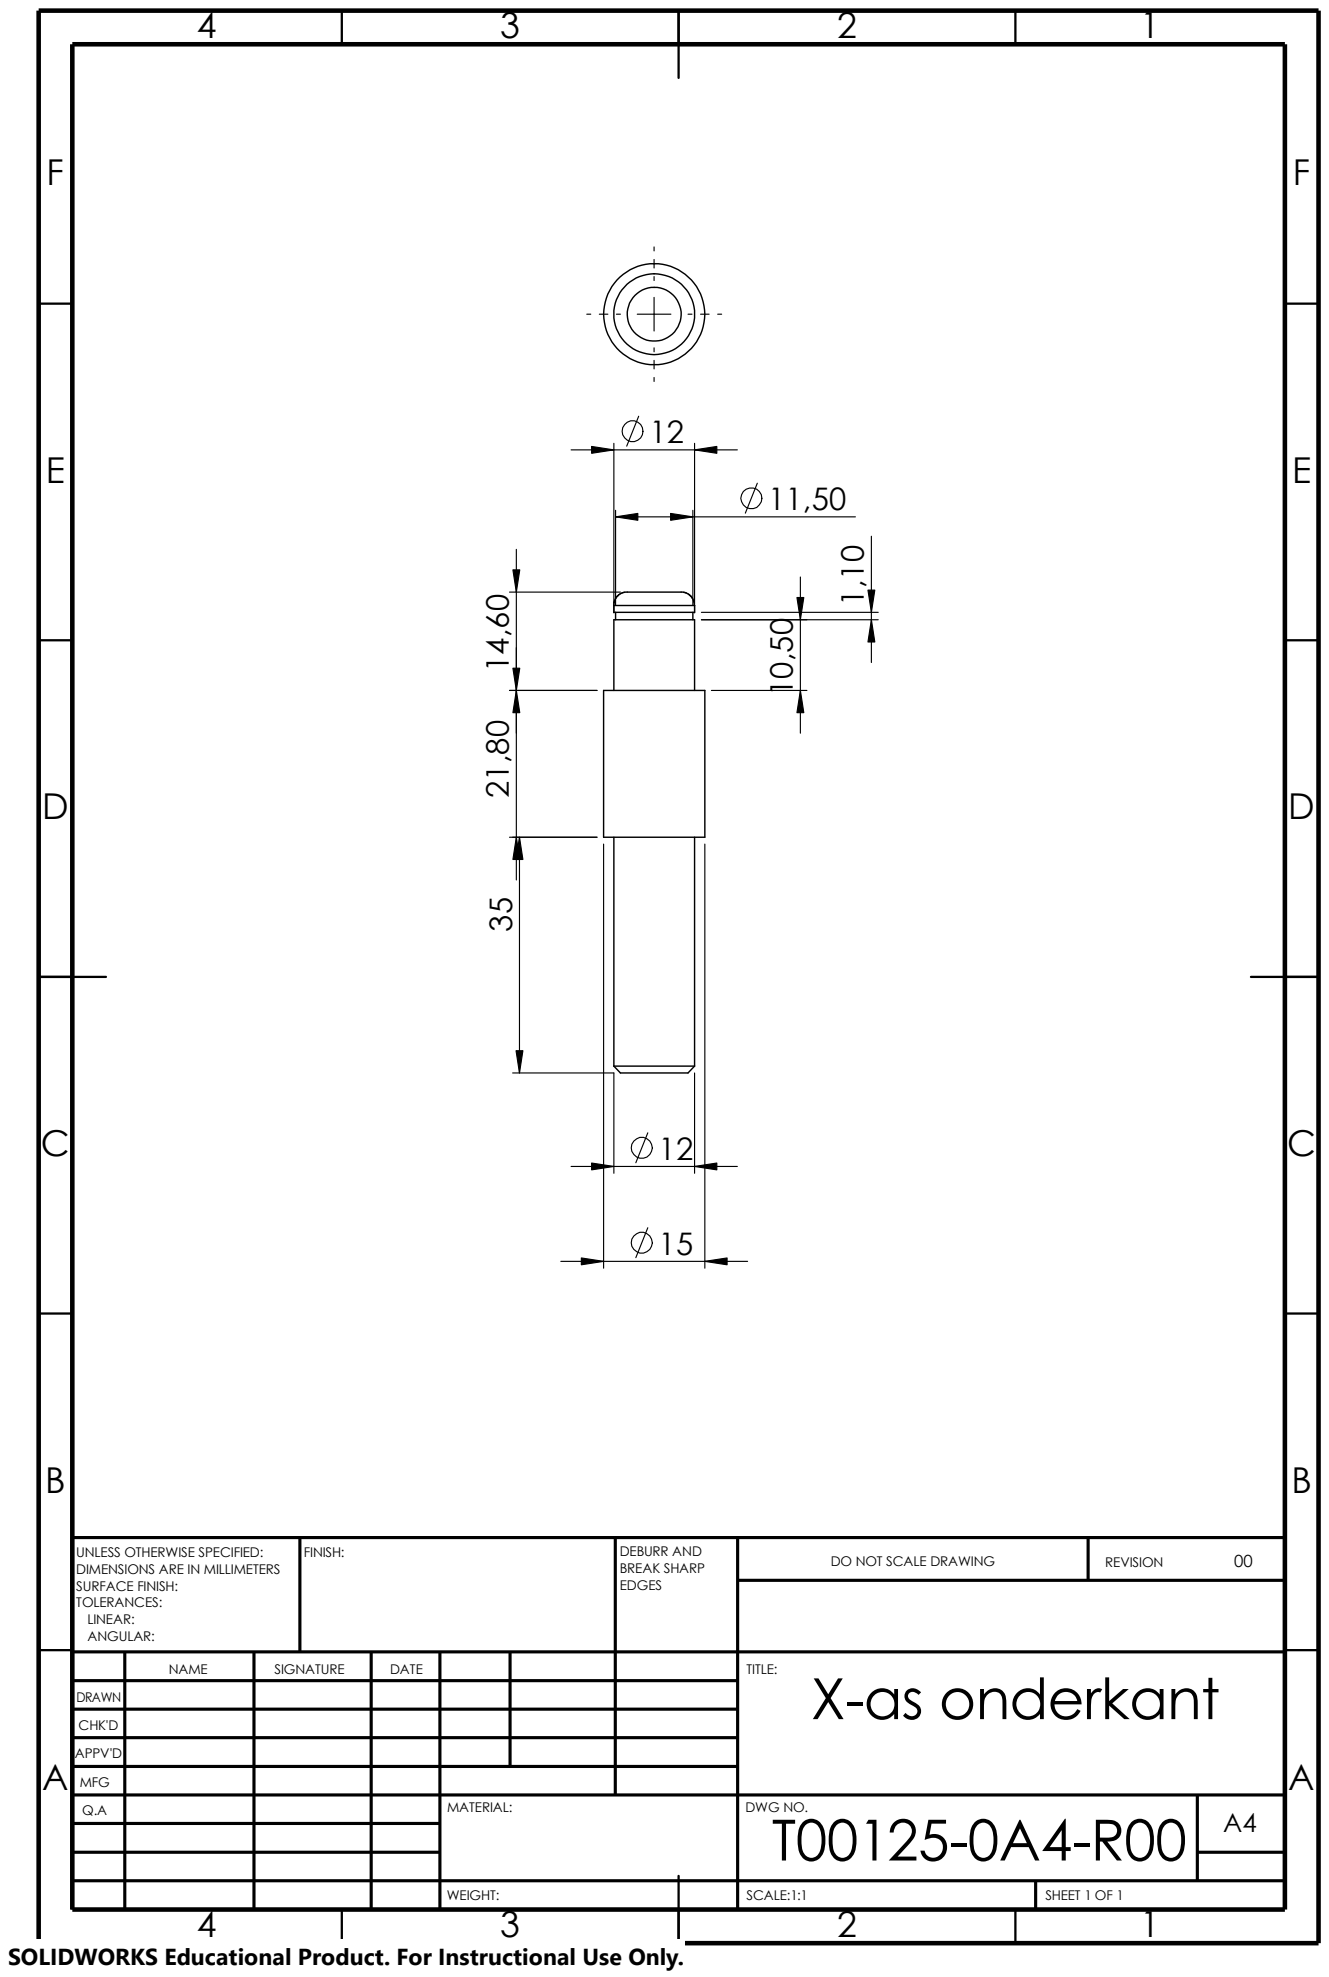
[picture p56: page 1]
WEIGHT:; SCALE:1:1; SHEET 1 OF 1; DWG NO.; REVISION; MFG; FINISH:; EDGES; MATERIAL:; DEBURR AND; BREAK SHARP

DO NOT SCALE DRAWING UNLESS OTHERWISE SPECIFIED:
DIMENSIONS ARE IN MILLIMETERS
SURFACE FINISH:
TOLERANCES:
LINEAR:
ANGULAR:

NAME | SIGNATURE | DATE | TITLE: X-as onderkant

DRAWN

CHK'D

APPV'D

SOLIDWORKS Educational Product. For Instructional Use Only.

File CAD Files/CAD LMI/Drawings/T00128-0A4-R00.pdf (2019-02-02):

E E

F F

WEIGHT:; SCALE:2:1; SHEET 1 OF 1; DWG NO.; REVISION; MFG; FINISH:; EDGES; MATERIAL:; DEBURR AND; BREAK SHARP

DO NOT SCALE DRAWING UNLESS OTHERWISE SPECIFIED:
DIMENSIONS ARE IN MILLIMETERS
SURFACE FINISH:
TOLERANCES:
LINEAR:
ANGULAR:

NAME | SIGNATURE | DATE | TITLE: As rotatie r richting

DRAWN

CHK'D

APPV'D

SOLIDWORKS Educational Product. For Instructional Use Only.

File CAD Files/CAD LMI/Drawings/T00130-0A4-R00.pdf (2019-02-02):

90
A

WEIGHT:; SCALE:1:1; SHEET 1 OF 1; DO NOT SCALE DRAWING; REVISION; MFG; FINISH:; EDGES; MATERIAL:; DWG NO.; DEBURR AND; BREAK SHARP; SECTION A-A

UNLESS OTHERWISE SPECIFIED:
DIMENSIONS ARE IN MILLIMETERS
SURFACE FINISH:
TOLERANCES:
LINEAR:
ANGULAR:

NAME | SIGNATURE | DATE | TITLE: Draaiflens

DRAWN

CHK'D

APPV'D

SOLIDWORKS Educational Product. For Instructional Use Only.

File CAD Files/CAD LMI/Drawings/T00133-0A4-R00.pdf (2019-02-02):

E E

F F

SHEET 1 OF 1; BREAK SHARP; stappenmotor A; WEIGHT:; FINISH:; EDGES; SCALE:1:2; REVISION; DEBURR AND

UNLESS OTHERWISE SPECIFIED:
DIMENSIONS ARE IN MILLIMETERS
SURFACE FINISH:
TOLERANCES:
LINEAR:
ANGULAR:

DO NOT SCALE DRAWING

NAME | SIGNATURE | DATE | | | | TITLE: Plateau

DRAWN
CHK'D
APPV'D
Q.A | | | | MATERIAL: | DWG NO. T00133-0A4-R00 | A4

MFG

SOLIDWORKS Educational Product. For Instructional Use Only.

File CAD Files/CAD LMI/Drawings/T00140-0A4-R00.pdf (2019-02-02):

E E

F F

BREAK SHARP; MFG; WEIGHT:; SCALE:1:20; SHEET 1 OF 1; FINISH:; EDGES; MATERIAL:; DO NOT SCALE DRAWING; REVISION; DWG NO.; DEBURR AND

UNLESS OTHERWISE SPECIFIED:
DIMENSIONS ARE IN MILLIMETERS
SURFACE FINISH:
TOLERANCES:
LINEAR:
ANGULAR:

NAME | SIGNATURE | DATE | TITLE: Top- en onderplaat magazijn

DRAWN

CHK'D

APPV'D

SOLIDWORKS Educational Product. For Instructional Use Only.

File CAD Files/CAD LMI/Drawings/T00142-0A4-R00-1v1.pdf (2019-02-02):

E E

F F

DOWN 90° R 4; SHEET 1 OF 1; MFG; BREAK SHARP; DEBURR AND; SCALE:1:10; FINISH:; EDGES; MATERIAL:; DO NOT SCALE DRAWING; REVISION; DWG NO.; WEIGHT:

UNLESS OTHERWISE SPECIFIED:
DIMENSIONS ARE IN MILLIMETERS
SURFACE FINISH:
TOLERANCES:
LINEAR:
ANGULAR:

NAME | SIGNATURE | DATE | TITLE: Zijplaat rechtsonder Flat-pattern

DRAWN

CHK'D

APPV'D

SOLIDWORKS Educational Product. For Instructional Use Only.

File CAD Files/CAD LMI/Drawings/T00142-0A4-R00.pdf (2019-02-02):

E E

F F

BREAK SHARP; rechtsonder A; WEIGHT:; SCALE:1:10; SHEET 1 OF 1; FINISH:; EDGES; DO NOT SCALE DRAWING; REVISION; DEBURR AND; DOWN 90° R 4

UNLESS OTHERWISE SPECIFIED:
DIMENSIONS ARE IN MILLIMETERS
SURFACE FINISH:
TOLERANCES:
LINEAR:
ANGULAR:

NAME | SIGNATURE | DATE | | | | TITLE: Zijplaat

DRAWN

CHK'D

APPV'D

MFG
Q.A | | | | MATERIAL: | DWG NO. T00142-0A4-R00 | A4

SOLIDWORKS Educational Product. For Instructional Use Only.

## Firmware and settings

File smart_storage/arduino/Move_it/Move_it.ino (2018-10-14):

#include <MultiStepper.h>
#include <AccelStepper.h>

// EG X-Y position bed driven by 2 steppers
// Alas its not possible to build an array of these with different pins for each :-(

AccelStepper stepperX(AccelStepper::DRIVER, 12, 7);
AccelStepper stepperY(AccelStepper::DRIVER, 11, 6);
AccelStepper stepperZ(AccelStepper::DRIVER, 10, 12);
AccelStepper stepperR(AccelStepper::DRIVER, 9, 5);
// Up to 10 steppers can be handled as a group by MultiStepper
MultiStepper steppers;

#define switch_hX 2 // Pin 2 connected to Home Switch (MicroSwitch)
#define switch_hY 3 // Pin 3 connected to Home Switch (MicroSwitch)
#define switch_hZ 19 // Pin 19 connected to Home Switch (MicroSwitch)
#define switch_hR 20 // Pin 20 connected to Home Switch (MicroSwitch)
#define switch_I 21 // Pin 21 connected to Home Switch (MicroSwitch)

// Communication variables
char StartChar = 'a';
char EndChar = 'a';

// movement variables and constants
long Row;
long column;
long stepsY;
long stepsX;
long columndistance = 350;     // Amount of y steps between the containers
long Rowdistance = 470;      // Amount of x steps between the containers
long Zconstant = 5000;           // Amount of steps to reach the containers
long Yconstant = 200;       // amount of steps for grabbing the container
long Rconstant = 5000;     // amount of steps to rotate the container 180 degrees


bool Homing_status = false;
long initial_homingX = -1;
long initial_homingY = -1;
long initial_homingZ = -1;
long initial_homingR = -1;
long positions[2]; // 0=X 1=Y
int state = 1;
void setup() {
  Serial.begin(9600);
  // Configure each stepper
  stepperX.setMaxSpeed(175);   //1000
  stepperX.setAcceleration(50); //200
  stepperY.setMaxSpeed(100); //1000
  stepperY.setAcceleration(50); //50
  stepperZ.setMaxSpeed(300);  //3000
  stepperZ.setAcceleration(100); //3000 
  stepperR.setMaxSpeed(200); //3000
  stepperR.setAcceleration(100); //3000


  // Then give them to MultiStepper to manage
  steppers.addStepper(stepperX);
  steppers.addStepper(stepperY);
  Home();
}
void loop() {
  switch (state) {
  case 1:
    CommandMessage();

    break;
  case 2:                 // "Get" state (Get Box)
    //Home();                //Home axis
    ConvertToSteps();     // Calculate the position of the container
    MoveToGoalXY();       // Move to the container
    

    //GrabContainer();      // Grab the container
    MoveToGoalXY();         // Go to the placing position
    //PlaceContainer();     // Place the container
    Serial.println("Complete");
    state = 1;
    break;

  case 3:               // "Set" state (Place box)
    //Home();                //Home axis
    ConvertToSteps();     // Calculate the position of the container
    MoveToGoalXY();       // Move to the container
    //GrabContainer();      // Grab the container

    MoveToGoalXY();         // Go to the placing position
    //PlaceContainer();     // Place the container
    Serial.println("Complete");
    state = 1;
    break;


  default:
    Home();
    break;
  }
}

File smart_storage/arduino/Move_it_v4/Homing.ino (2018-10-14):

void Home() {

  Homing_status = true;

  //Serial.println("DEBUG: Been here, done that. Gonna check Z.");

  //Home the Z
  while (!digitalRead(switch_hZ) && state != 4) {  // Make the Stepper move CCW until the switch is activated
    stepperZ.moveTo(initial_homingZ);  // Set the position to move to
    initial_homingZ--;  // Decrease by 1 for next move if needed
    stepperZ.run();  // Start moving the stepper
    delay(2);
  }
  //Serial.print("Z distance:");
    //Serial.println(initial_homingZ);


  //Serial.println("DEBUG: Been here, done that. Z-axis. Gonna check X");

  //Home the X
  while (!digitalRead(switch_hX) && state != 4) {  // Make the Stepper move CCW until the switch is activated
    stepperX.moveTo(initial_homingX);  // Set the position to move to
    initial_homingX++;  // Decrease by 1 for next move if needed
    stepperX.run();  // Start moving the stepper
    delay(5);
  }
  //Serial.print("X distance:");
    //Serial.println(initial_homingX);

  //Serial.println("DEBUG: Been here, done that. X-axis. Gonna check Y.");

  //Home the Y
  while (!digitalRead(switch_hY) && state != 4) {
    stepperY.moveTo(initial_homingY);  // Set the position to move to
    initial_homingY++;  // Decrease by 1 for next move if needed
    stepperY.run();  // Start moving the stepper
    delay(5);
  }
  
    //Serial.print("Y distance:");
    //Serial.println(initial_homingY);

  //Serial.println("DEBUG: Been here, done that. Y-axis. Gonna check R.");

  //Home the R
  while (!digitalRead(switch_hR)  && state != 4) {
    stepperR.moveTo(initial_homingR);  // Set the position to move to
    initial_homingR--;  // Decrease by 1 for next move if needed
    stepperR.run();  // Start moving the stepper
    delay(2);
  }
  
      //Serial.print("R distance:");
    //Serial.println(initial_homingR);


 // Serial.println("DEBUG: Been here, done that. R-axis");
  stepperZ.setCurrentPosition(0);
  stepperX.setCurrentPosition(0);
  stepperY.setCurrentPosition(0);
  stepperR.setCurrentPosition(0);
  
    stepperR.moveTo(straight);
  
  while(stepperR.distanceToGo() != 0 && state != 4){
    stepperR.run();
  }
  
  
  stepperZ.moveTo(500);
  
  while(stepperZ.distanceToGo() != 0 && state != 4){
    stepperZ.run();
  }
  

  stepperX.moveTo(-367);

   while(stepperX.distanceToGo() != 0  && state != 4){
      stepperX.run();
    }

  
  stepperY.moveTo(-  500);

   while(stepperY.distanceToGo() != 0  && state != 4){
      stepperY.run();
    }
  
  if (state == 4) Serial.println("Error state");
  delay(1000);
  
  Homing_status = false;
}

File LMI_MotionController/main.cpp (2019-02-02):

#include "mbed.h"
#include "MotionPlanner.h"

DigitalOut xs(PE_2);
DigitalOut ys(PD_11);
DigitalOut zs(PD_13);
DigitalOut rs(PD_12);
DigitalOut xd(PB_2);
DigitalOut yd(PB_6);
DigitalOut zd(PC_2);
DigitalOut rd(PF_4);

DigitalOut ybrake(PF_8);

DigitalIn xlim1(PE_15);
DigitalIn xlim2(PE_14);
DigitalIn ylim1(PE_12);
DigitalIn ylim2(PE_10);
DigitalIn zlim1(PG_14);
DigitalIn rlim1(PE_8);
DigitalIn rlim2(PG_9);

MotionPlanner xaxis = MotionPlanner(TIM2, xs, false, xd, true);
MotionPlanner yaxis = MotionPlanner(TIM2, ys, false, yd, false);
MotionPlanner zaxis = MotionPlanner(TIM2, zs, false, zd, true);
MotionPlanner raxis = MotionPlanner(TIM2, rs, false, rd, true);

char buffer[256];
char gline[128];
unsigned int buffer_length;
char* gcode_buffer;
char* gcode_pointer;
Serial host(USBTX, USBRX, 115200);

DigitalOut led1(LED1);
DigitalOut led2(LED2);
DigitalOut led3(LED3);
DigitalIn button(USER_BUTTON);

void process_gline(char * buffer);
void serial_rx();

int main()
{
    ybrake = 0;
    host.attach(&serial_rx);
    
    xaxis.set_limitswitch(xlim1, 0, false);
    xaxis.set_limitswitch(xlim2, 1, false);
    yaxis.set_limitswitch(ylim1, 0, false);
    yaxis.set_limitswitch(ylim2, 1, false);
    zaxis.set_limitswitch(zlim1, 0, false);
    raxis.set_limitswitch(rlim1, 0, false);
    raxis.set_limitswitch(rlim2, 1, false);
    
    printf("X limits: %d\n", xaxis.limit_count);
    printf("Y limits: %d\n", yaxis.limit_count);
    printf("Z limits: %d\n", zaxis.limit_count);
    printf("R limits: %d\n", raxis.limit_count);
    printf("Motion controller set up\n");
    
    __TIM2_CLK_ENABLE();
    MotionPlanner::initTimer(TIM2, TIM2_IRQn);
    xaxis.setAcceleration(1200);
    xaxis.setSpeed(2000);
    yaxis.setAcceleration(4800);
    yaxis.setSpeed(5000);
    zaxis.setAcceleration(3000);
    zaxis.setSpeed(20000);
    raxis.setAcceleration(3000);
    raxis.setSpeed(2000);
    __TIM2_CLK_ENABLE();
    
    wait(2);
    ybrake = 1;
    
    while (true) {
        char * gline_end = strchr(buffer, '\n');
        if(gline_end != NULL){
            *gline_end = '\0';
            strcpy(gline, buffer);
            process_gline(gline);
            buffer[0] = '\0';
            buffer_length = 0;
            printf("ok\n");
        }
    }
}

void serial_rx(){
    char c = host.getc();
    if(c == '\b'){
#ifdef ECHO_SERIAL
        printf("\b ");
#endif
        buffer_length--;
    }else{
        buffer[buffer_length++] = c;
    }
#ifdef ECHO_SERIAL
    printf("%c", c);
#endif
    buffer[buffer_length] = '\0';
}

bool gcode_seen(char c){
    gcode_pointer = gcode_buffer;
    do{
      // Keep searching for character until on of the following conditions is met:
      // - Character is at the start of the string
      // - Character is preceded by a whitespace
      // - The end of the stirng is reached
        gcode_pointer = strchr(gcode_pointer, c);
    }while(!(gcode_pointer == gcode_buffer || gcode_pointer == NULL || *(gcode_pointer-1) == ' '));
    return gcode_pointer != NULL;
}

long gcode_value(){
    return strtol(gcode_pointer+1, NULL, 0);
}

void process_gline(char* buffer){
    gcode_buffer = buffer;
    if(gcode_seen('G')){
        switch(gcode_value()){
            case 0:
            case 1:
                // G0 | G1: Linear move
                if(gcode_seen('X')) xaxis.prepareAbsoluteMove(gcode_value());
                if(gcode_seen('Y')) yaxis.prepareAbsoluteMove(gcode_value());
                if(gcode_seen('Z')) zaxis.prepareAbsoluteMove(gcode_value());
                if(gcode_seen('R')) raxis.prepareAbsoluteMove(gcode_value());
                xaxis.startMove();
                yaxis.startMove();
                zaxis.startMove();
                raxis.startMove();
                break;
            case 28:
                // G28: Home
                if(gcode_seen('X') || gcode_seen('Y') || gcode_seen('Z') || gcode_seen('R')){
                    if(gcode_seen('X')) xaxis.home(gcode_value());
                    if(gcode_seen('Y')) yaxis.home(gcode_value());
                    if(gcode_seen('Z')) zaxis.home(gcode_value());
                    if(gcode_seen('R')) raxis.home(gcode_value());
                }else{
                    xaxis.home();
                    yaxis.home();
                    zaxis.home();
                    raxis.home();
                }
                break;
            case 92:
                // G92: set current position
                if(gcode_seen('X')) xaxis.position = gcode_value();
                if(gcode_seen('Y')) yaxis.position = gcode_value();
                if(gcode_seen('Z')) zaxis.position = gcode_value();
                if(gcode_seen('R')) raxis.position = gcode_value();
                break;
        }
    }else if(gcode_seen('M')){
        switch(gcode_value()){
            case 200:
            //Set axis velocity
                if(gcode_seen('X')) xaxis.setSpeed(gcode_value());
                if(gcode_seen('Y')) yaxis.setSpeed(gcode_value());
                if(gcode_seen('Z')) zaxis.setSpeed(gcode_value());
                if(gcode_seen('R')) raxis.setSpeed(gcode_value());
                break;
            case 201:
            //Set axis acceleration
                if(gcode_seen('X')) xaxis.setAcceleration(gcode_value());
                if(gcode_seen('Y')) yaxis.setAcceleration(gcode_value());
                if(gcode_seen('Z')) zaxis.setAcceleration(gcode_value());
                if(gcode_seen('R')) raxis.setAcceleration(gcode_value());
                break;
            case 119:
            // Print limit switch state
                printf("Limits: ");
                printf("X(%c%c) ", xaxis.get_limitswitch_char(0), xaxis.get_limitswitch_char(1));
                printf("Y(%c%c) ", yaxis.get_limitswitch_char(0), yaxis.get_limitswitch_char(1));
                printf("Z(%c%c) ", zaxis.get_limitswitch_char(0), zaxis.get_limitswitch_char(1));
                printf("R(%c%c) ", raxis.get_limitswitch_char(0), raxis.get_limitswitch_char(1));
                break;
            case 400:
            // Wait for motion to finish
                if(gcode_seen('X') || gcode_seen('Y') || gcode_seen('Z') || gcode_seen('R')){
                    if(gcode_seen('X')) xaxis.wait();
                    if(gcode_seen('Y')) yaxis.wait();
                    if(gcode_seen('Z')) zaxis.wait();
                    if(gcode_seen('R')) raxis.wait();
                }else{
                    xaxis.wait();
                    yaxis.wait();
                    zaxis.wait();
                    raxis.wait();
                }
                break;
        }
    }
}

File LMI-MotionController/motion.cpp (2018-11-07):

#include "Arduino.h"
#include "config.h"
#include "motion.h"

uint32_t position[N_AXIS];
AccelStepper steppers[N_AXIS];
MultiStepper motion;

void setup_steppers(){
  for(uint8_t i=0; i<N_AXIS; i++){
    AccelStepper stepper(AccelStepper::DRIVER, PINS_STEP[i], PINS_DIR[i]);
    stepper.setMaxSpeed(MAX_SPEED[i]);
    stepper.setAcceleration(MAX_ACCEL[i]);
    stepper.setSpeed(DEFAULT_SPEED[i]);
    stepper.setMinPulseWidth(20);
    steppers[i] = stepper;
    motion.addStepper(stepper);
//#ifdef DRIVER_ENABLE
    pinMode(PINS_ENA[i], OUTPUT);
    digitalWrite(PINS_ENA[i], LOW);
//#endif
//#ifdef DRIVER_CURRENT
    analogWrite(PINS_CURRENT[i], 100);
//#endif
    //attachInterrupt(digitalPinToInterrupt(PINS_HOME[i]), limitSwitch, RISING);
  }
}

void setAxisFeedrate(uint32_t rate){
  int32_t dpsq[N_AXIS];
}

void home(bool x, bool y, bool z, bool r){
  // ToDo: Perform an actual homeing cycle...
  for(uint8_t i=0; i<N_AXIS; i++){
    position[i] = 0;
  }
  motion.moveTo(position);
}

float stepsToMM(uint8_t axis, uint32_t steps){
  return float(steps) / STEPS_MM[axis];
}

uint32_t mmToSteps(uint8_t axis, float mm){
  return mm * STEPS_MM[axis];
}

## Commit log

2019-02-02 Add CAD files
    [Gat elektrokast.DXF, Gat elektrokast.SLDPRT, Part1.SLDPRT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]
2019-02-03 Add barcode printer script
2019-02-03 Add README of barcode printer
